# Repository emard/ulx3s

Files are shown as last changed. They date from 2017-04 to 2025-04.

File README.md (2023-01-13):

# ULX3S PCB

[ULX3S](http://radiona.org/ulx3s) = [University digital Logic](https://www.fer.unizg.hr/en/course/diglog) Learning
Xtensible board release 3 with SDRAM,
Successor of [ULX2S](http://github.com/emard/ulx2s).

[Manual](/doc/MANUAL.md) *
[Quickstart Binaries](http://github.com/emard/ulx3s-bin) *
[ULX3S at Kitspace](https://kitspace.org/boards/github.com/emard/ulx3s)

3D preview

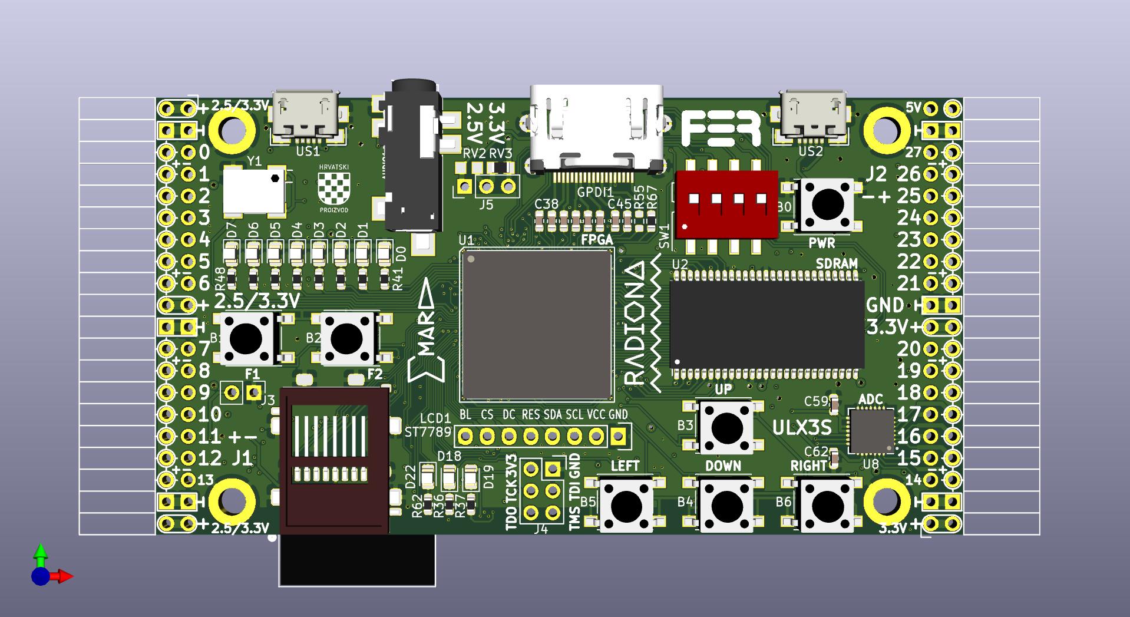
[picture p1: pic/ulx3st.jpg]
TOP

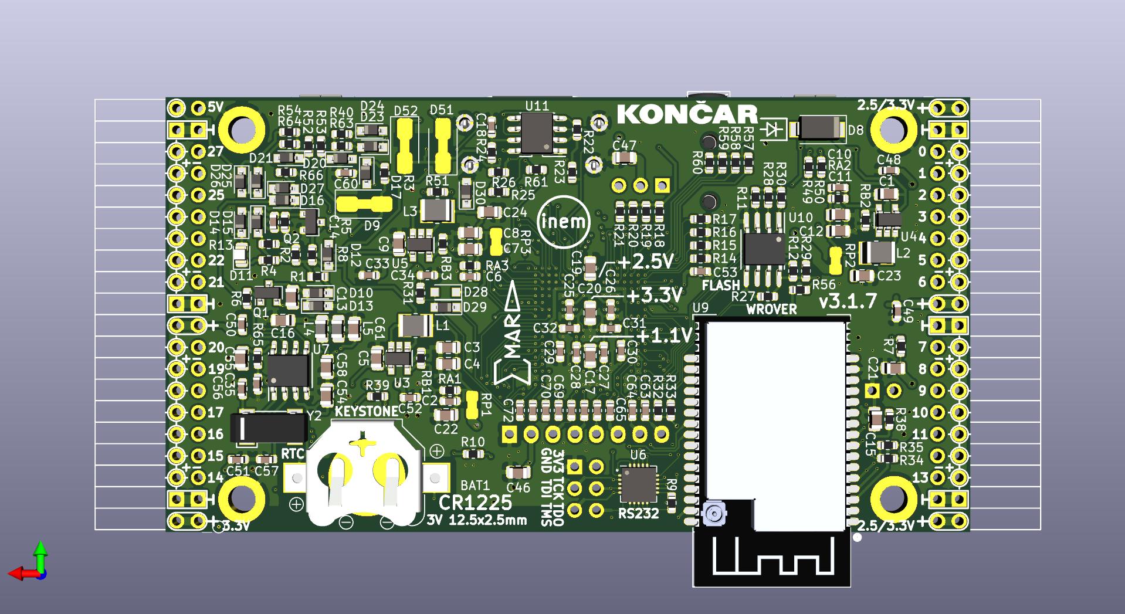
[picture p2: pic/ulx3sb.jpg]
BOTTOM


Prototypes available
at [SKRIPTARNICA](http://skriptarnica.hr/vijest.aspx?newsID=1466),
local shop inside of [FER](https://www.fer.unizg.hr/) university.

This is a small (94x51 mm) standalone FPGA board 
for education, research and general purpose, with a full 
featured selection of chips which I all wanted on
a low-cost PCB, but haven't found on the market.
It's open source and open hardware because if it is
good for our development of [f32c](http://github.com/f32c/f32c) SOC,
it should be also good to other projects.

ULX3S will carry all digital logic on our
research, [education](https://www.fer.unizg.hr/en/course/diglog) and
[makerspace](https://radiona.org) projects in next 5 years.

ULX3S is standalone embeddable gadget with onboard display, buttons,
storage, WiFi and compatible connectors.

ULX3S can do things no other board can.

ULX3S can self-reflash with a bitstream sent
remotely from web interface over WiFi or from SD
card browsed by onboard OLED display and buttons.

ULX3S can completely power down and wakeup from
battery backed RTC.

ULX3S has rich range of chips and connectivity
required for many other open source projects:
SDRAM, USB, PS/2, SDCARD, Digital Video, FLASH, RTC, I2C, OLED, AUDIO, ADC,
onboard FM/ASK antenna 88-433.92 MHz and 56 GPIO pins routed as differential
pairs and have pinout that is PMOD compatible. There are 12 true
differential bidirectional pairs and 16 single-ended pairs.

ULX3S is sufficiently equipped to
emulate [Amiga](https://github.com/emard/Minimig_ECS) retro
computer and run its games, but can do much more like
running [Linux](https://twitter.com/fpga_dave/status/1053290842809683968).

[Schematics](/doc/schematics.pdf) and PCB started with KiCAD 4.
After version v1.8 project switched to KiCAD 5 PCB editor:

    kicad ulx3s.pro

View generated gerbers

    gerbv -p plot/ulx3s.gvp

# Features

FPGA: Lattice ECP5 [LFE5U-85F-6BG381C](http://www.latticesemi.com/view_document?document_id=50461) (12/25/45/85K LUT)

USB: FTDI [FT231XS](https://www.ftdichip.com/Support/Documents/DataSheets/ICs/DS_FT231X.pdf) (500kbit JTAG and 3Mbit USB-serial)

GPIO: 56 pins (12 true differential pairs, 16 single-ended pairs),
[PMOD](https://reference.digilentinc.com/_media/pmod:pmod:originalPmodInterfaceSpecification.pdf) compatible
with power out 3.3V/1A 2.5V/1.5A

RAM: 16-bit SDRAM [MT48LC32M16](https://www.micron.com/-/media/client/global/Documents/Products/Data%20Sheet/DRAM/256Mb_sdr.pdf) (8/16/32/64 MB)

Flash: Quad-SPI Flash [IS25LP128F](http://www.issi.com/WW/pdf/25LP-WP128F.pdf) (4/8/16 MB for FPGA config and user data)

Storage: Micro-SD slot

LEDs: 11 (8 blink-LEDs, 2 USB LEDs, 1 WiFi LED)

Buttons: 7 (4 direction, 2 fire, 1 power button)

Audio: 3.5 mm jack with 4 contacts (analog stereo + digital audio or composite video)

Video: GPDI connector with 3.3V-5V I2C bidirectional level shifter

Display: placeholder for 0.96" SPI COLOR OLED [SSD1331](https://drive.google.com/file/d/0B5lkVYnewKTGRlpxcEdWaXNvWnM/view)

WiFi+bluetooth: placeholder for [ESP-32](https://www.espressif.com/sites/default/files/documentation/esp32_datasheet_en.pdf) (Standalone JTAG web interface over WiFi)

Antenna: 88-108/433 MHz FM/ASK onboard

ADC: 8 channels, 12 bit, 1 MSa/s [MAX11125](https://datasheets.maximintegrated.com/en/ds/MAX11120-MAX11128.pdf) (4/8-ch, 8/10/12-bit, 0.5/1 MSa/s)

Power: 3 Switching voltage regulators: 1.1V, 2.5V, 3.3V (1.5/2A)

Clock: 25 MHz onboard, external differential clock input

Low power sleep: 5uA/5V standby, RTC [MCP7940N](http://ww1.microchip.com/downloads/en/DeviceDoc/20005010F.pdf) clock wakeup, power button, 32768 Hz quartz and battery

GPDI is General Purpose Differential Interface,
Electrically LVDS, mostly TMDS tolerant
female receptacle more-or-less compatible
with digital monitors/TVs

# Production

Independent production
like [q3k](https://twitter.com/q3k/status/1029010026269167618) or
[samlittlewood](https://twitter.com/samlittlewood/status/1108531208001077250) is
welcome and desirable under conditions of [modified MIT LICENSE](/LICENSE.md).
If you do manual assembly here is [minimal parts list](/doc/MINIMAL.md).

ZIP the gerbers and send them to manufacturer:

    zip -r /tmp/ulx3s.zip plot/ulx3s

If you are going to order this project by yourself, it is important
what manufacturer to choose for PCBA (PCB and Assembly) service.

Parts can be ordered from [Detailed BOM](/doc/ulx3s_bom.csv)
or from [ULX3S at Kitspace](https://kitspace.org/boards/github.com/emard/ulx3s),
which automatically submits [Simplified 1-click BOM](/1-click-bom.tsv) by
clicking on "Digikey" or "Mouser" button. On each click, Digikey and Mouser will keep
accumulating the BOM in the shopping cart. Number of unique parts on Digikey and Mouser
should be equal but DigiKey may split some parts (LEDs) in multiple rows.
To reset shopping cart, click "New Cart" or "New Basket".
Kitspace may be updated with about 1 day delay after this project update.

Choose PCBA manufacturer which can produce PCB of IPC CLASS 3 quality,
5/5 mil trace resolution and 0.2 mm holes.
Avoid manufacturer who claims "quality" and "satisfaction" but doesn't
really know what will be IPC CLASS rating for this project.

PCBA manufacturer prices for the parts should be approximately equal as those
from distributors like [Mouser](http://www.mouser.com) or [DigiKey](http://www.digikey.com).
Avoid any PCBA manufacturer who asks 3$ for the 1$ part or 40$ for the 30$ part.
Select [Mouser](http://www.mouser.com) language/location icon to PCBA manufacturer
country of origin and $-currency to check is PCBA manufacturer telling the truth
about prices.

Before soldering the parts, ask manufacturer for [pictures](/pic/ulx3sb-v18.jpg) of PCB.
CLASS 3 demands, among other things, that all drill holes stay inside of VIA pads.
If some holes [break-out](/pic/ulx3sb-v18-breakout-c19.png) from pads,
ask manufacturer to make new PCBs with better drill and copper layer alignment.

[PCBCART](http://www.pcbcart.com) offers CLASS 3 quality and assembly at reasonable cost.
Prices for the parts are equal to [Mouser](http://www.mouser.com).

Don't pay everything at once. Following payment phases during the
PCBA production are recommended:

    1. Pay for the parts
    2. Manufacturer orders the parts and optionally negotiates with you about part numbers.
       Depending on market availability, some parts may come in different physical package.
    3. Send updated gerbers which fit to ordered parts.
    4. Pay for PCB
    5. Manufacturer sends pictures of produced PCB for your inspection.
       If anything looks suspicious, ask also for X-ray imaging.
    6. Pay for the assembly and shipping.

Nobody wants quality issues, so it is good to ask if manufacturer has qualified personnel
able to follow instructions 
for [ULX3S self-test](https://github.com/emard/ulx3s-bin) before shipping.

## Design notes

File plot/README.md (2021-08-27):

# Submitting for production (panelized by manufacturer)

If manufacturer panelizes, we should create
gerber files for a single PCB.

From pcbnew open PCB, view it and menu

    File->Plot

Click "Plot" to create gerbers and click "Generate Drill File"
another window will open. Click "Drill file" to create drill files.

Generate footprint positions

    File->Fabrication Outputs->Footprint Position (.pos) File

Generate floorplan PDF for top and bottom side

    File->Print
    [x] F.Fab  [ ] Print Mirrored
    [x] B.Fab  [x] Print Mirrored

RAR or ZIP to a file

    cd plot
    rar a  /tmp/ulx3s-pcb.rar gerbers
    zip -r /tmp/ulx3s-pcb.zip gerbers

Open [Seeedstudio PCB production](https://www.seeedstudio.com/fusion_pcb.html)
page, select:

    Size: 94x51 mm
    Layer: 4-layer board
    Min Solder Mask: 0.1 mm
    Min Hole size: 0.2 mm
    Min Tracking/Spacing: 5/5 mils
    Quality: IPC Class 3

click "Add your gerber file" and upload this rar file then
click on "Gerber Viewer" to see what will be produced.

Exporting for production:

Drill file:
[x] Excellon format
[x] inch units
[x] suppress trailing zeros
[x] PTH and NPTH in the same file

Footprint position file:
[x] ASCII format
[x] mm units

# Submitting for production (panelized by us)

If we panelize, we should create gerbers for panel
and the stencil. Gerbers should have a file describing
depanelization cuts (vertical v-cuts and horizontal mill
lines).

Install [KiKit](https://github.com/yaqwsx/KiKit) or upgrade

    pip3 uninstall kikit
    pip3 install git+https://github.com/yaqwsx/KiKit@master
    pip3 install --upgrade git+https://github.com/yaqwsx/KiKit@master
    pip3 show kikit
    Version: 0.99-pre1.0+35.g4fe4b78

Generate gerbers in RAR file (needs "KiKit" and "rar" installed)

    make

View panel gerbers with gerbv:

    cd plot
    gerbv (File->Open ulx3s-panel.gvp, F5 to refresh)

Count number of pads in gerbv:

    select visible either PasteTop or PasteBottom layer.
    (all other layers de-selected)
    Analyze->Analyze visible Gerber layers->D codes
    D03 count (flash aperture) is the number of pads.
    PasteTop    : 4464 pads
    PasteBottom : 1016 pads

View panel design with pcbnew (try View->3D Viewer):

    pcbnew plot/panel/ulx3s-panel.kicad_pcb

Upload "plot/panel/ulx3s-panel-gerber.rar" file generated by "make" to 
[JLCPCB](http://jlcpcb.com) and select options:

    PCB Panel
    -------------------
    Base Material       : [FR-4] Aluminium
    Layers              : 1  2 [4] 6
    Dimensions [mm]     : 213 * 246
    PCB Qty             : 5 [10] 15  20
    Different Design    : [1] 2  3  4
    Delivery Format     : Single PCB [Panel by Customer] Panel by JLCPCB
    Panel Format        : Columns: 2  Rows: 4
    PCB Thickness       : 0.8  1.0  1.2 [1.6] 2.0 mm
    Impedance           : [No] Yes
    PCB Color           : [Green] Red Yellow Blue White Black
    Silkscreen          : White
    Surface Finish      : HASL(with lead) LeadFree HASL-RoHS [ENIG-RoHS]
    Outer Copper Weight : [1 oz] 2 oz
    Inner Copper Weight : [0.5 oz] 2 oz
    Gold Fingers        : [No] Yes
    Material Type       : FR4-Standard Tg 130-145C [FR4 TG155] 
    Confirm Production file : No [Yes]
    Flying Probe Test   : [Fully Test] Not Test
    Castellated Holes   : [No] Yes
    Remove Order Number : [No] Yes  Specify Location

    Advanced options
    Min Hole            : 0.45 mm [0.2/0.4 mm]
    4-Wire Kelvin Test  : No [Yes]
    Paper between PCBs  : No [Yes]
    Appearance Quality  : [IPC Class 2 Standard] Superb Quality

    PCB Remark:         : 4 vertical V-CUTS, 16 horizontal MILL LINES of 2 mm width

    SMT Assembly        : No

    Stencil             : Yes (Order together with PCB)
    -------------------
    Framework           : No [Yes]
    Dimensions [mm]     :[470*370 (valid area 290*190)]
                          400*300 (valid area 240*140)
                          520*420 (valid area 340*240)
    Customized size     : [No] Yes
    Stencil Side        : Top+Bottom (On Single Stencil)
                          Top
                          Bottom 
                         [Top&Bottom (On Separate Stencil)]
    Electropolishing    : No [Yes]
    Fiducials           : No Fiducial
                         [Etched Through]
                          Etched Half into board

    Sending options     : EuroPacket

Check [JLCPCB extra costs](https://support.jlcpcb.com/article/62-what-cases-will-be-charged-of-extra-cost).
For stencil, up to 1000 pads above 4000 they charge 4.3$,
so they will ask for additional 9.6$ because
stencil has 4464 pads on top and 1016 on bottom, 
total 5480 pads.

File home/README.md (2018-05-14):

# User's home directory config

This is copy of my home config kicad directory

    ~/.config/kicad/

It seems that newly installed kicad 5 debian
doesn't by default set all paths correctly.

Opening ulx3s project shows many schematics simbols
as question marks.

Manually copying this config to user's home config
seems to help.

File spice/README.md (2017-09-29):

# Spice model for power section

Board can power down into low power mode and
can wake up from battery powered RTC.

RC network with adjusted time constants
tries to provide such function.

Here is spice model to test it and optionally
adjust the values

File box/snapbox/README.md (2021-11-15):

# Snap-on Screwless Box

Box for PCBs and similar.
Top and bottom parts snap-on and lock when pushed together.

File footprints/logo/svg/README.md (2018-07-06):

# Logos

Use [SVG2MOD](https://github.com/mtl/svg2mod) to convert from SVG to kicad
footprint.

In short before conversion srawing layer in the SVG file has to be
renamed usually "Layer 1" to "Cu" or "SilkS" (case insensitive). Renaming can be
done from SVG editor like "Inkscape" but in most case, "sed" will work too.

At convertsion usually some floating point scale factor is needed to make
object of desired size e.g "-f 1.5"

It can help if file is opened and saved from inkscape.

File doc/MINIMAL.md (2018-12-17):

# Minimal required parts

When manually assembling boards, it is good to know
the minimal parts list that has to be assembled for the
board to respond and be programmed.

FPGA

    U1

Switching power supplies:

    C1,U3,L1,C2,RA1,RB1,C3,C4,C22,C17
    C9,U4,L2,C10,RA2,RB2,C11,C12,C23,C19
    C5,U5,L3,C6,RA3,RB3,C7,C8,C24,C20

Power-up and hold circuit:

    US1               - USB connector
    D8                - US1 power routing diode
    R10,D12           - USB power up
    D16,R3,B0         - BTN0 power up
    R6,Q1,D13,D10,R1  - power up transistor
    D11,R4,R2         - power hold

FPGA decoupling capacitors, board could probably
work without them:

    C17,C19,C20,C25,C26,C31,C32,C27,C28,C29,C30

USB-serial to program FPGA over USB. FPGA can also
be programmed without USB-serial chip using J4 JTAG header
and external JTAG programmer:

    R49,R50,R9,U6

Clock 25MHz to properly clock examples.
FPGA will respond with JTAG ID and can be
programmed even work for combinatorial-only
examples (no registers) without this clock.

    Y1

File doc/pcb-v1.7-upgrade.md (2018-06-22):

# PCB v1.7 upgrade

This is the first board produced, most important
parts work which is mirracle in itself, and there
are some mistakes, luckily most of them can be fixed.

Mount:

    U3, U4, U5:  TLV62569DBV
    SDCARD:      SCHD3A0100
    U11 I2C:     PCA9306D SOIC-8 150-mil
    U10 FLASH:   IS25LP032D-JNLE-TR SOIC-8 150mil
    U9 WIFI:     ESP32, but not all pins! read below:

FIX: Replace this parts:

    D11=LED (High efficiency RED recommended)
    R4,R25,R26=4.7k

D11 and R4 are are on the back side on the left,
under the edge of SDRAM chip.

R25 and R26 are on the back side top,
under the GPDI connector.

Optionally, as alternative software shutdown, 
connect J2 "25-" pin to R13-D15 junction.

Don't connect ESP32 pins leading to SD card,
in the top 10-pin row, connect only 2 pins on left side and 2 pins on right
and leave 6 central pins unconnected. GND and VCC
can be connected, but no other SD signal pins.
Either cut the traces or carefully solder without 
touching those pads.

Cut WIFIEN trace and connect it to the junction of
R35 and J3, jumper should work then.

# What is fixed

Shutdown:

PCB v1.7 assembled comes with D11=1N4148 and R4=15k, those will
keep waking up the board after shutdown signal because FT231x internal
regulator will provide some voltage (cca 2.5V will appear at 3.3V line)
and that is enough to wake up the board because voltage
on ENABLE pin at switching regulators will be above its turn on
threshold of 1.5V.

Using higher voltage drop diode (RED, YELLOW or GREEN LED cca 1.7-2V, not
BLUE or WHITE) and adequate resistor, the voltage at ENABLE pin is now about
1.3V, inside of the switching regulator's hysteresis range. ENABLE is
not above turn-on threshold neither below turn-off threshold so it will
self-hold switching regulator during normal operation and at controlled
shutdown signal, it will drop below turn-off threshold, allowing reliable
shutdown.

Software shutdown is not routed to BGA pads. It is possible to connect
any GPIO (we recommend "25-") to SHUTDOWN.

I2C:

Too low pull up resistors (470 ohm) are at 5V side of the level converter PCA9306
and some monitors will receive niose with that. If data traffic at i2c is
not received 100% error-free, some monitors will get into serious problems.
When monitor interprets some data garbage as random write command and
overwrites its internal settings, such monitor might become premanently
useless. Correct pull up resistors are 4.7k and they should work properly.

WIFI:

On PCB v1.7 SD card is connected to those ESP32 pins which are widely advertised
as SD card pins, but those pins are shared with internal SPI FLASH.
So ESP32 won't boot if anything is connected there.
SD card could be connected on other pins, probably shared with OLED.
It has not yet been tested, so no patch recommendation yet.

WiFi-OFF jumper J3 doesn't have priority over FPGA enable.
If ESP32 needs to be disabled (for example, it keeps driving JTAG)
and FPGA runs bitstream which holds WiFi enabled, then J3 jumper will not
disable WiFi chip because WIFIEN is connected to wrong pin of R35.

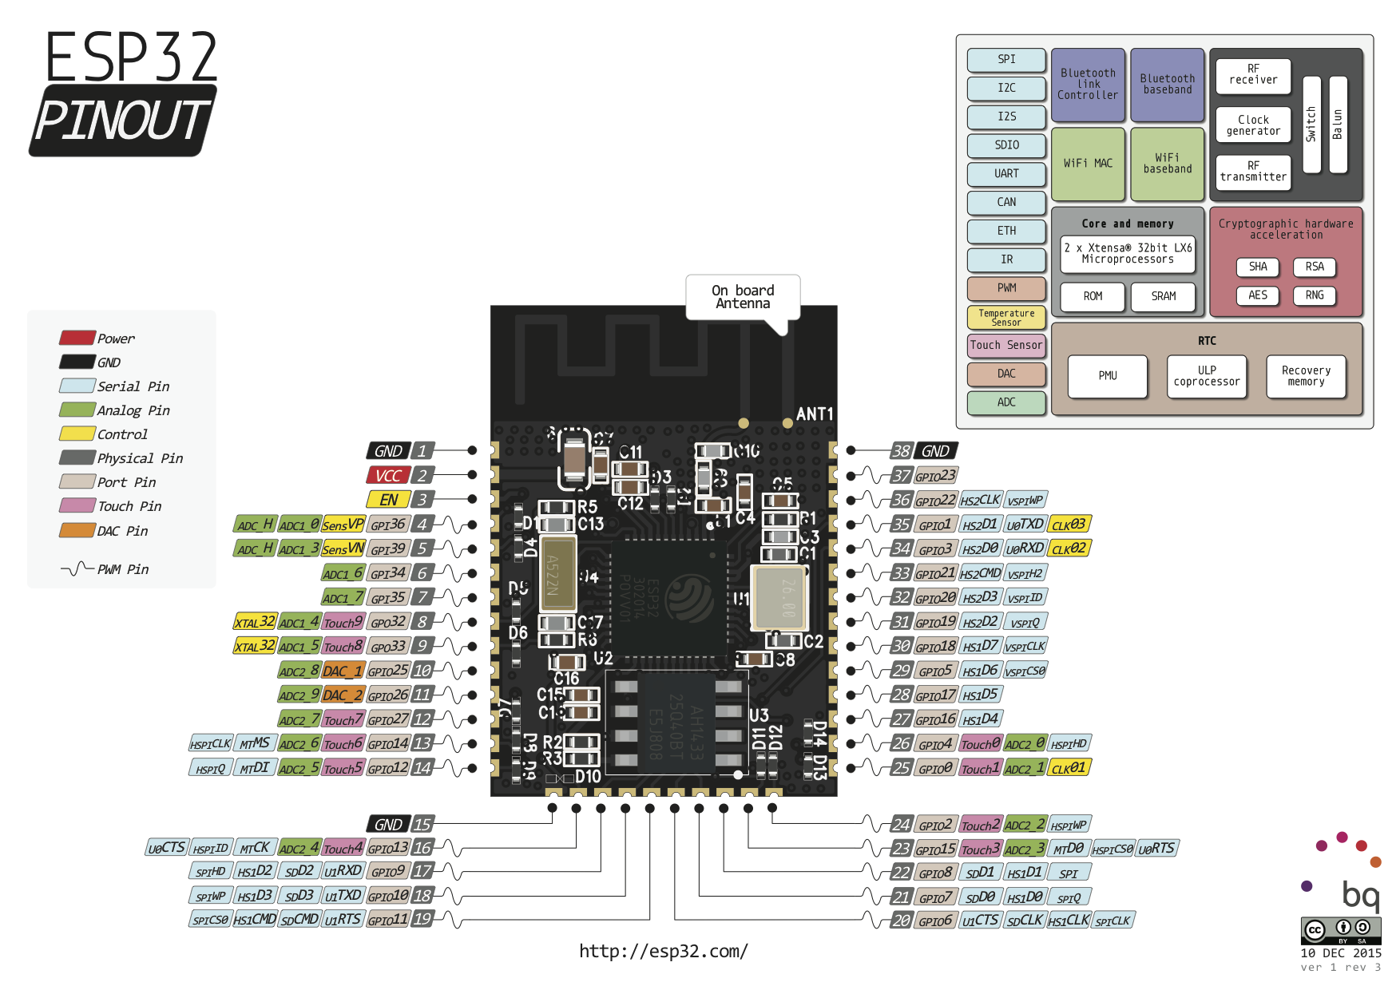
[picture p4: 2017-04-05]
doc/ESP32_Pinout_a1_3.png

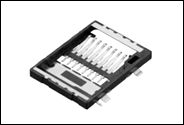
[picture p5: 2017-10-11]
doc/sdcard/sdcard-schd3a010/alps-SCHD3A0100.jpg

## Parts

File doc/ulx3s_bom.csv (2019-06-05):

Component | Description | Part | References | Value | Footprint | Quantity Per PCB | Datasheet | Koncar | Vertical | MNF1_URL | MPN | MFG1 | Digikey | price100_Vertical | Side | Mouser | price700_LCSC | LCSC | price100_RS | RS | MPN3 | Digike_y3 | MNF3_URL | Digike_y2 | MPN2 | MFG2 | MFG3 | Datasheet3 | MNF2_URL | Mouse_r2 | price1500_Mouser | Mouse_r3 | Mouse_r4 | Mouse_r5 | price1200_Chip1stop | Chip1stop | price200_Mouser | MP_N3 | MP_N2 | Datasheet2 | LowCost | price300_LCSC | TME | price300_TME | price200_LCSC | price400_LCSC | Mouser_URL | price100_AvnetEU | AvnetEU | price100_Mouser | price100_Onlinecomponents | Onlinecomponents | price300_Vertical | DatasheetLC | MP_N4 | MFG4 | MP_N5 | price_Arrow | Arrow
1 | audio jack TRS 6 pins apple/nokia | JACK_TRS_6PINS_APPLE | AUDIO1 | JACK_TRS_6PINS | CUI_SJ-43516-SMT | 1 | http://www.cui.com/product/resource/sj-4351x-smt-series.pdf | FAU001 | SJ-43516-SMT-TR | www.cui.com | SJ-43516-SMT-TR | CUI | CP-43516SJCT-ND | 0.8015$ | T | 490-SJ-43516-SMT-TR
2 | Push button switch, generic, two pins | SW_Push | B0 B1 B2 B3 B4 B5 B6 | PTS645 | SW_SPST_PTS645 | 7 | http://www.ckswitches.com/media/1471/pts645.pdf | FSW001 |  | www.ckswitches.com | PTS645SL50SMTR92 LFS |  | CKN9088CT-ND |  | T | 611-PTS645SL50SMTR92 | 0.09966$ | C221877
3 | Single-cell battery | Battery_Cell | BAT1 | CR1225 | Keystone_3000_1x12mm-CoinCell | 1 | http://www.keyelco.com/product-pdf.cfm?p=777 | FBAT001 |  | www.keyelco.com | 3000TR | Keystone | BK-885-ND |  |  | 855-S8201-46R |  |  | 0.33296$ | 1613707 | S8201-46R | 952-1662-1-ND | www.harwin.com | 36-3000CT-ND | BK-885 | MPD | Harwin | https://cdn.harwin.com/pdfs/S8201R.pdf | www.memoryprotectiondevices.com
4 | Unpolarized capacitor | C | C13 C16 C17 C19 C20 C22 C23 C24 C46 C47 | 2.2uF | C_0805_2012Metric | 10 |  | FC001 |  | www.yageo.com | CC0805MRX5R6BB225 |  | 587-5918-1-ND |  |  | 80-C0805C225K4R3123 |  |  |  |  |  |  |  | 1276-2903-1-ND |  |  |  |  |  | 603-CC805MRX5R6BB225
5 | Unpolarized capacitor | C | C14 C36 C37 C38 C39 C40 C41 C42 C43 C44 C45 C59 C60 C62 | 220nF | C_0603_1608Metric | 14 |  | FC002 |  | www.yageo.com | CC0603KRX7R8BB224 |  | 1276-1112-1-ND |  | TB | 81-GCM188R71E224K55D |  |  |  |  |  |  |  |  |  |  |  |  |  | 603-CC603KRX7R6BB224
6 | Unpolarized capacitor | C | C25 C26 C27 C28 C29 C30 C31 C32 C33 C34 C35 C48 C49 C50 C51 C52 C53 | 22nF | C_0603_1608Metric | 17 |  | FC003 |  | www.yageo.com | CC0603JRX7R8BB223 CX0603MRX7R8BB223 |  | 587-1238-1-ND |  |  | 603-CC603JRX7R8BB223 |  |  |  |  |  |  |  | 1276-2000-1-ND |  |  |  |  |  | 603-AC603KRX7R7BB223 | 35.7$
7 | Unpolarized capacitor | C | C1 C3 C4 C5 C7 C8 C9 C11 C12 C15 C21 C54 C55 C58 C61 | 22uF | C_0805_2012Metric | 15 |  | FC004 |  | www.yageo.com | CC0805ZKY5V5BB226 |  | 1276-2413-1-ND |  |  | 81-GRM21BR61A226ME1L |  |  |  |  |  |  |  | 1276-2412-1-ND |  |  |  |  |  | 81-GRM21BR61A226ME1K |  | 81-GRM219R61C226ME5L | 81-GRM188C60J226ME0J | 963-LMK212BBJ226MG-T
8 | Unpolarized capacitor | C | C56 C57 | 3.3pF | C_0603_1608Metric | 2 |  | FC005 |  | www.yageo.com | CC0603CRNPO9BN3R3 |  | 311-3848-1-ND |  |  | 710-885012006048 |  |  |  |  |  |  |  | 311-3855-1-ND
9 | Unpolarized capacitor | C | C2 C6 C10 C18 | 470pF | C_0603_1608Metric | 4 |  | FC006 |  | www.yageo.com | CS0603KRX7R9BB471 |  | 399-9086-1-ND |  |  | 603-CC603KRX7R9BB471 |  |  |  |  |  |  |  |  |  |  |  |  |  | 603-CS0603KRX79BB471
10 | Diode | D | D10 D13 D14 D16 D17 D23 D24 D25 D26 D27 D29 | 1N914 | D_SOD-323_HandSoldering | 11 |  | FV001 |  | www.fairchildsemi.com | 1N4148WS |  | 1N914BWSCT-ND |  |  | 863-MMDL914T1G |  |  |  |  |  | 1N4148WXTPMSCT-ND |  | 1N4148WSFSCT-ND |  |  |  |  |  |  |  |  |  |  | 0.01209$ | C1S541901230010
11 | Zener diode, small symbol, filled shape | D_Zener_Small_ALT | D20 D21 | 3.6V | D_SOD-323_HandSoldering | 2 | http://www.taiwansemi.com/products/datasheet/BZT52C2V4S%20SERIES_H1709.pdf | FV002 |  | www.taiwansemi.com | BZT52C3V6S |  | BZT52C3V6S-TPMSCT-ND |  |  | 833-BZT52C3V6S-TP |  |  |  |  |  |  |  |  |  |  |  |  |  |  |  |  |  |  |  |  | 0.096$
12 | Schottky diode | D_Schottky | D12 D15 | BAT54W | D_SOD-323_HandSoldering | 2 |  | FV003 |  | www.onsemi.com | NSR0530HT1G | ON semiconductor | NSR0530HT1GOSCT-ND |  |  | 755-RSX051VYM30FHTR |  |  |  |  |  |  |  |  | BAT54WSQ-7-F | Diodes inc. |  |  | www.diodes.com |  |  |  |  |  |  |  | 0.093$
13 | Light emitting diode | LED | D22 | BLUE | LED_0805_2012Metric | 1 | http://optoelectronics.liteon.com/upload/download/DS-22-99-0226/LTST-C170TBKT.pdf | FV004 |  | www.liteon.com | LTST-C170TBKT |  | 160-1579-1-ND |  | T | 859-LTST-C170TBKT |  |  |  |  |  |  |  |  |  |  |  | https://www.rohm.com/datasheet/SML-M13UT |  | 755-SMLMN2BCTT86C |  | 859-LTST-C171TBKT |  |  |  |  |  | SMLMN2BCTT86C | LTST-C171TBKT | http://optoelectronics.liteon.com/upload/download/ds22-2000-233/ltst-c171tbkt(0630).pdf
14 | Light emitting diode, filled shape | LED_ALT | D3 D7 | BLUE | LED_0805_2012Metric | 2 | http://optoelectronics.liteon.com/upload/download/DS-22-99-0226/LTST-C170TBKT.pdf | FV004 |  | www.liteon.com | LTST-C170TBKT |  | 160-1579-1-ND |  | T | 859-LTST-C170TBKT |  | C98222 |  |  |  |  |  |  |  |  |  | https://www.rohm.com/datasheet/SML-M13UT |  | 755-SMLMN2BCTT86C |  | 859-LTST-C171TBKT |  |  |  |  |  | SMLMN2BCTT86C | LTST-C171TBKT | http://optoelectronics.liteon.com/upload/download/ds22-2000-233/ltst-c171tbkt(0630).pdf | LTST-C170KRKT | 0.02930$
15 | Light emitting diode | LED | D18 | GREEN | LED_0805_2012Metric | 1 | http://optoelectronics.liteon.com/upload/download/DS22-2000-073/LTST-C170KGKT.pdf | FV005 |  | www.liteon.com | LTST-C170TGKT |  | 160-1887-1-ND |  | T | 859-LTST-C170TGKT
16 | Light emitting diode, filled shape | LED_ALT | D2 D6 | GREEN | LED_0805_2012Metric | 2 | http://optoelectronics.liteon.com/upload/download/DS22-2000-073/LTST-C170KGKT.pdf | FV005 |  | www.liteon.com | LTST-C170TGKT |  | 160-1887-1-ND |  | T | 859-LTST-C170TGKT |  |  |  |  |  |  |  |  |  |  |  |  |  |  |  |  |  |  |  |  |  |  |  |  | LTST-C170KRKT |  | LTST-C170TGKT | 0.0789$
17 | Light emitting diode, filled shape | LED_ALT | D1 D5 | ORANGE | LED_0805_2012Metric | 2 | https://optoelectronics.liteon.com/upload/download/DS-22-99-0185/LTST-C170KFKT.pdf | FV006 |  | www.liteon.com | LTST-C170KFKT |  | 160-1413-1-ND |  | T | 859-LTST-C170KFKT |  | C284931 |  |  |  |  |  |  |  |  |  |  |  |  |  |  |  |  |  |  |  |  |  |  | LTST-C170KRKT |  |  |  | 0.02075$
18 | Light emitting diode, filled shape | LED_ALT | D0 D4 D11 D19 | RED | LED_0805_2012Metric | 4 | https://optoelectronics.liteon.com/upload/download/DS-22-99-0150/LTST-C170KRKT.pdf | FV007 |  | www.liteon.com | LTST-C170KRKT |  | 160-1415-1-ND |  | TB | 859-LTST-C170KRKT |  | C94868 |  |  |  |  |  |  |  |  |  |  |  |  |  |  |  |  |  |  |  |  |  |  |  |  |  |  |  | 0.0195$ | www.mouser.com
19 | Schottky diode, small symbol | D_Schottky_Small | D8 | STPS2L30AF | D_SMA | 1 |  | FV008 |  | www.st.com | STPS2L30AF |  | 497-12310-1-ND |  |  | 511-STPS2L30AF |  |  |  |  |  |  |  |  |  |  |  |  |  |  |  |  |  |  |  |  |  |  |  |  |  |  |  |  |  |  |  | 0.22121$ | STPS2L30AF
20 | HDMI-D | HDMI-D | GPDI1 | GPDI-D | CONN-10029449-111RLF | 1 | http://portal.fciconnect.com/Comergent/fci/drawing/10029449.pdf | FX001 |  | www.amphenol-icc.com | 10029449-111RLF |  | 609-4614-1-ND |  | T | 649-10029449-111RLF |  |  |  |  |  |  |  | A136174CT-ND | 5-1903015-5 |  |  |  | www.te.com |  |  |  |  |  |  |  |  |  |  | https://hr.mouser.com/datasheet/2/418/NG_CD_1903015_S-662666.pdf |  |  |  |  |  |  |  |  |  | 0.439€ | 0.364$ | 10029449-111RLF
21 | Inductor | L | L1 L2 L3 | 2.2uH | L_1008_1210 | 3 | http://psearch.en.murata.com/inductor/product/DFE252012PD-2R2M%23.pdf | FL001 | DFE322512F-2R2M=P2 | www.murata.com | DFE322512F-2R2M=P2 | Murata | 490-10649-1-ND |  |  | 81-DFE322512F-2R2MP2 |  | C285914 |  |  |  |  | www.bourns.com |  |  | Murata | Bourns |  | www.murata.com |  |  |  |  |  |  |  |  | SRP2512A-2R2M | DFE252012P-2R2M=P2 |  | 81-DFE252012P-2R2MP2 | 0.1082$ |  |  |  |  |  |  |  |  |  |  | 0.48360$ | https://datasheet.octopart.com/LQH32PB2R2NN0L-Murata-datasheet-20916646.pdf | HEI322512A-2R2M-Q8 | Chilisin Elec | 81-LQH32PB2R2NN0L
22 | Inductor, small symbol | L_Small | L4 L5 | 33uH | L_0805_2012Metric_Pad1.15x1.40mm_HandSolder | 2 | ~ | FL002 |  | www.bourns.com | CV201210-330K |  | CV201210-330KCT-ND |  |  | 652-CV201210-330K
23 | N-MOSFET transistor, gate/source/drain | Q_NMOS_GSD | Q2 | 2N7002 | SOT-23 | 1 | https://assets.nexperia.com/documents/data_sheet/2N7002.pdf | FT002 |  | www.nxp.com | 2N7002P,215 |  | 2N7002K-TPMSCT-ND |  |  | 757-T2N7002AKLM |  |  |  |  |  |  |  |  |  |  |  |  |  | 512-2N7002L |  |  |  |  |  |  |  |  |  |  |  |  |  |  |  |  |  |  |  |  |  |  |  |  |  |  |  | 0.0437$ | T2N7002AK,LM
24 | PNP transistor, base/emitter/collector | Q_PNP_BEC | Q1 | BC857 | SOT-23 | 1 | https://assets.nexperia.com/documents/data-sheet/BC856_BC857_BC858.pdf | FT001 |  | www.nxp.com | BC857 |  | TBC857BLMCT-ND |  |  | 583-BC856A-T |  |  |  |  |  |  |  |  |  |  |  |  |  | 863-BC857BLT1G |  |  |  |  |  |  |  |  |  |  |  |  |  |  |  |  |  |  |  | 0.06$
25 | Resistor | R | R38 | 0.47 | R_0603_1608Metric | 1 |  | FR001 |  | www.ctscorp.com | 73L2R47J | CTS | 73L2R47JCT-ND |  |  | 774-73L2R47J
26 | Resistor | R | R6 R8 R14 R18 R29 R40 R54 R57 R66 | 1.1k | R_0603_1608Metric | 9 |  | FR002 |  | www.yageo.com | RC0603FR-071K1L |  | P1.10KHCT-ND |  |  | 603-RC0603FR-071K1L
27 | Resistor | R | R24 | 100k | R_0603_1608Metric | 1 |  | FR003 |  | www.yageo.com | AC0603FR-10100KL |  | P100KHCT-ND |  |  | 71-RCA0603100KJNEC |  |  |  |  |  |  |  |  |  |  |  |  |  | 71-CRCW0603100KFKEAC
28 | Resistor | R | R11 R12 R27 R28 | 10k | R_0603_1608Metric | 4 |  | FR014 |  | www.yageo.com | RC0603FR-0710KL |  | 311-10KLMCT-ND |  |  | 603-RC0603FR-0710KL
29 | Resistor | R | R7 R10 R17 R21 R39 R51 R60 | 130 | R_0603_1608Metric | 7 |  | FR004 |  | www.yageo.com | RC0603FR-07130RL |  | 311-130HRCT-ND |  |  | 603-RC0603FR-07130RL
30 | Resistor | R | R9 R13 R31 R32 R33 R34 R55 R63 R64 RA1 RA2 RA3 | 15k | R_0603_1608Metric | 12 |  | FR005 |  | www.yageo.com | RC0603FR-0715KL RC0603FR-1015KL |  | YAG3569CT-ND |  |  | 603-RC0603FR-0715KL |  |  |  |  |  |  |  |  |  |  |  |  |  | 603-RC0603FR-1015KL | 8.4$ | 603-RC0603FR-1315KL
31 | Resistor | R | R2 RB1 | 18k | R_0603_1608Metric | 2 |  | FR006 |  | www.yageo.com | RC0603FR-1018KL |  | 311-18.0KHRCT-ND |  |  | 71-CRCW060318K0FKEAC
32 | Resistor | R | R5 | 2.2M | R_0603_1608Metric | 1 |  | FR007 |  | www.yageo.com | RC0603FR-132M2L |  | P2.20MHCT-ND |  |  | 603-AC0603FR-072M2L
33 | Resistor | R | R49 R50 R52 R53 | 27 | R_0603_1608Metric | 4 |  | FR008 |  | www.yageo.com | AC0603JR-0727RL |  | 311-27.0HRCT-ND |  |  | 603-AC0603JR-0727RL
34 | Resistor | R | R16 R20 R59 | 270 | R_0603_1608Metric | 3 |  | FR010 |  | www.yageo.com | RC0603FR-07270RL |  | 311-270HRCT-ND |  |  | 603-RC0603FR-07270RL
35 | Resistor | R | R22 R23 RB3 | 3.3k | R_0603_1608Metric | 3 |  | FR009 |  | www.yageo.com | RT0603FRE073K3L |  | YAG3605CT-ND |  |  | 603-RC0603FR-073K3L |  |  |  |  |  |  |  |  |  |  |  |  |  | 603-RC0603FR-103K3L
36 | Resistor | R | R1 R3 R4 R25 R26 R30 RB2 | 4.7k | R_0603_1608Metric | 7 |  | FR011 |  | www.yageo.com | AC0603FR-104K7L |  | YAG3613CT-ND |  |  | 755-SFR03EZPF4701 |  |  |  |  |  |  |  |  |  |  |  |  |  | 603-RC0603FR-074K7L |  | 603-AC0603FR-074K7L
37 | Resistor | R | R15 R19 R35 R36 R37 R41 R42 R43 R44 R45 R46 R47 R48 R58 R61 R62 R65 | 549 | R_0603_1608Metric | 17 |  | FR012 |  | www.yageo.com | RC0603FR-07549RL |  | 311-549HRCT-ND |  | TB | 603-RC0603FR-07549RL
38 | Jumper, normally closed, small symbol | Jumper_NC_Small | RV3 | 0 | R_0805_2012Metric_Pad1.29x1.40mm_HandSolder | 1 |  | FR013 |  | www.yageo.com | RC0805JR-070RL |  | YAG1327CT-ND |  | T | 71-RCG08050000Z0EA
39 | Micro SD Card Socket with CD | Micro_SD_Card_CD | SD1 | SCHD3A0100 | SCHD3A100 | 1 | https://www.relayspec.com/catalogs/001285/2010/SCHD.pdf | FX002 |  | www.on-stars.com | SCHD3A0100 |  | WM6698DKR-ND |  | T | 538-47219-2001 |  | C164170 |  |  |  |  |  |  | 47219-2001 |  |  |  | www.molex.com |  |  |  |  |  |  |  |  |  |  | https://www.molex.com/pdm_docs/sd/472192001_sd.pdf
40 | 4x DIP Switch, Single Pole Single Throw (SPST) switch, small symbol | SW_DIP_x04 | SW1 | SW_DIP_x04 | SW_DIP_x4_W8.61mm_Slide_LowProfile | 1 | https://www.ctscorp.com/wp-content/uploads/219.pdf | FSW002 |  | www.jameco.com | 219-4MST |  | CT2194MST-ND |  | T | 774-2194MST
41 | ESP-WROOM32 | ESP-WROOM32 | U9 | ESP32-WROOM | ESP32-WROOM-stencil | 1 | http://espressif.com/sites/default/files/documentation/esp32_datasheet_en.pdf | FU001 |  | espressif.com | ESP-WROOM-32 |  | 1904-1010-1-ND |  |  | 356-ESP-WROOM-32 |  |  |  |  |  |  |  |  |  |  |  |  |  |  |  |  |  |  |  |  |  |  |  |  | Leave empty |  |  |  |  |  |  |  |  | 3.32€
42 | Full Speed USB to Full Handshake UART, SSOP-20 | FT231XS | U6 | FT231XS | FT231X-SSOP-20_4.4x6.5mm_Pitch0.65mm | 1 | www.ftdichip.com/Documents/DataSheets/ICs/DS_FT231X.pdf | FU002 |  | www.ftdichip.com | FT231XS |  | 768-1129-1-ND |  |  | 895-FT231XS-R |  |  | 1.86$ | 7570032
43 | SPI Serial EEPROM, DIP-8/SOIC-8/TSSOP-8 | 25LCxxx | U10 | IS25LP128F-JBLE | SOA008-150-208mil | 1 | http://www.issi.com/WW/pdf/25LP-WP128F.pdf | FU003 |  | www.issi.com | IS25LP128F-JBLE |  | W25Q128JVSIQCT-ND |  |  | 454-W25Q128JVSIMTR |  | C97521 |  |  | IS25LP032D-JNLA3 | 706-1607-1-ND | www.issi.com | IS25LP128F-JBLE-ND | IS25LP032D-JNLE-TR |  |  |  | www.issi.com |  |  |  |  |  |  |  |  |  |  | http://www.issi.com/WW/pdf/25LP-WP032D.pdf | 870-IS25LP032DJBLETR
44 | ECP5U85 | LFE5U-85F-6BG381C | U1 | LFE5U-85F-6BG381C | BGA-381_pitch0.8mm_dia0.4mm | 1 | http://www.latticesemi.com/~/media/LatticeSemi/Documents/DataSheets/ECP5/FPGA-DS-02012.pdf | FU004 |  | www.latticesemi.com | LFE5U-85F-6BG381C | Lattice | 220-2071-ND |  | T | 842-LFE5U85F6BG381C |  |  |  |  |  |  |  |  |  | Lattice |  |  | www.latticesemi.com |  |  |  |  |  |  |  |  |  | LFE5U-12F-6BG381C |  | 842-LFE5U12F6BG381C |  |  |  |  |  | www.mouser.com
45 | SPI ADC | MAX1112x | U8 | MAX11125 | MAX1112x-TQFN-28-1EP_5x5mm_Pitch0.5mm | 1 | https://datasheets.maximintegrated.com/en/ds/MAX11120-MAX11128.pdf | FU005 |  | www.maximintegrated.com | MAX11125ATI+ |  | MAX11125ATI+-ND |  | T | 700-MAX11125ATI+ |  |  |  |  |  |  |  |  | MAX11123ATI+ |  |  |  | www.maximintegrated.com |  |  |  |  |  |  |  |  |  |  |  | 700-MAX11123ATI+
46 | Realtime Clock/Calendar I2C Interface, SOIC-8 | PCF8563T | U7 | MCP7940NT | SOT96-1 | 1 | http://ww1.microchip.com/downloads/en/DeviceDoc/20005010F.pdf | FU006 |  | www.microchip.com | MCP7940NT-I/SN |  | MCP7940NT-I/SNCT-ND |  |  | 579-MCP7940NT-I/SN |  |  |  |  |  |  |  | 568-5306-1-ND | PCF8523T/1,118 |  |  |  | www.nxp.com |  |  |  |  |  |  |  |  |  |  | https://www.nxp.com/docs/en/data-sheet/PCF8523.pdf |  |  |  |  |  |  |  |  |  |  |  |  |  |  |  |  |  |  | MCP7940NT-I/SN
47 | SDRAM | MT48LC16M16A2TG | U2 | MT48LC16M16A2TG | TSOP54 | 1 | https://www.micron.com/~/media/Documents/Products/Data%20Sheet/DRAM/256Mb_sdr.pdf | FU007 |  | www.micron.com | MT48LC16M16A2TG-6A | Micron | 1450-1385-1-ND |  | T | 913-AS4C32M16SB-7TCN |  | C62379 |  |  | W9812G6KH-6 |  |  | 1450-1352-1-ND | IS42S16160G-7TL-TR | ISSI | Winbond |  | www.issi.com | 913-4816M16A2TG6AGTR |  |  |  |  |  |  |  |  |  |  |  |  |  |  |  |  |  |  |  |  |  |  |  |  |  | Alliance
48 | 2-Bit Bidirectional Voltage-Level Translator in SOIC-8 Package | PCA9306D | U11 | PCA9306D | SM8 | 1 | https://www.nxp.com/docs/en/data-sheet/PCA9306.pdf | FU008 |  | www.nxp.com | PCA9306D |  | 568-4215-1-ND |  |  | 771-PCA9306D-T |  |  |  |  |  |  |  |  |  |  |  |  |  |  |  |  |  |  |  |  |  |  |  |  | Leave empty
49 | DC-DC Converter | DCDC | U3 U4 U5 | TLV62569DBV | TSOT-25 | 3 | http://www.ti.com/lit/ds/symlink/tlv62569.pdf | FU009 |  | www.ti.com | TLV62569DBVR | TI | 296-47360-1-ND |  |  | 595-TLV62569DBVR |  | C141836 |  |  |  |  |  |  | DIO6015BCST5 | DIOO |  |  | www.dioo.com | 453-DIO6015BCST5 |  |  |  |  |  |  |  |  |  |  | 453-DIO6015BCST5 |  |  |  |  |  |  |  |  |  |  |  |  | http://www.dioo.com/attachments/files/20161031180022_361.pdf
50 | Micro USB | USB_OTG | US1 US2 | MICRO_USB | USB-MICRO-B-FCI-10118192-0001LF | 2 | http://portal.fciconnect.com/Comergent/fci/drawing/10118192.pdf | FU010 |  | www.fciconnect.com | 10118192-0001LF | FCI | 609-4613-1-ND |  | T | 649-10118192-0001LF |  |  |  |  |  |  |  |  | 47346-0001 | Molex |  |  | www.molex.com | 538-47346-0001 |  |  |  |  |  |  |  |  |  | https://www.molex.com/pdm_docs/sd/473460001_sd.pdf
51 | Four pin crystal, GND on pins 2 and 3 | Crystal_GND23 | Y2 | 32768Hz | Crystal_SMD_ABS25 | 1 | https://www.iqdfrequencyproducts.com/products/pn/LFXTAL016178Reel.pdf | FQ002 |  | www.iqdfrequencyproducts.com | LFXTAL016178REEL |  | 1923-1021-1-ND |  |  | 449-LFXTAL016178REEL |  |  |  |  | LFXTAL003000Reel |  |  | 1923-1019-1-ND | CM7V-T1A-32.768k-9pF-20PPM-TA-QA T3 |  |  | http://www.iqdfrequencyproducts.com/products/pn/LFXTAL003000Reel.pdf |  | 428-201568-MG03 |  | 815-ABS25-32.768KHZT |  |  |  |  |  |  |  |  |  |  | 32.768K-855MXR
52 | Four pin crystal, GND on pins 2 and 4 | Crystal_GND24 | Y1 | FNETHE025 | Crystal_SMD_7050_4Pads | 1 | https://www.diodes.com/assets/Datasheets/FNETHE025.pdf | FQ001 |  | www.diodes.com | FNETHE025 |  | FNETHE025CT-ND |  | T | 729-FNETHE025
Component Groups: | 52
Component Count: | 196
Fitted Components: | 196
Number of PCBs: | 1
Total components: | 196
Schematic Version: | 3.0.8
Schematic Date:
BoM Date: | srijeda, 05. lipnja 2019. 12:30:37 CEST
Schematic Source: | /home/guest/src/fpga/circuits/ulx3s/ulx3s.sch
KiCad Version: | Eeschema 5.0.2+dfsg1-1
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

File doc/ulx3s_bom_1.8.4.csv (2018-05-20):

Component | Description | Part | References | Value | Footprint | Quantity Per PCB | Datasheet | MFG_URL | Distributor1_PN | MFG_PN | Distributor1_URL | Distributor1_PN2 | Distributor1_PN1 | MFG2_URL | MFG1_PN | MFG2_PN | MFG1_URL | Distributor2_URL | Datasheet2 | Distributor2_PN | Note | MFG_TR_DS
1 | audio jack TRS 6 pins | JACK_TRS_6PINS | AUDIO1 | JACK_TRS_6PINS | CUI_SJ-43516-SMT | 1 | http://www.cui.com/product/resource/sj-4351x-smt-series.pdf | www.cui.com | 490-SJ-43516-SMT-TR | SJ-43516-SMT-TR | www.mouser.com
2 | single battery cell | Battery_Cell | BAT1 | CR1225 | Keystone_3000_1x12mm-CoinCell | 1 | http://www.keyelco.com/product-pdf.cfm?p=777 | www.keyelco.com | 534-3000TR | 3000TR | www.mouser.com
3 | Push button switch, generic, two pins | SW_Push | BTN0 BTN1 BTN2 BTN3 BTN4 BTN5 BTN6 | PTS645 | SW_SPST_PTS645 | 7 | http://www.ckswitches.com/media/1471/pts645.pdf | www.ckswitches.com |  | PTS645SL50SMTR92 LFS | www.mouser.com
4 | Unpolarized capacitor | C | C14 C36 C37 C38 C39 C40 C41 C42 C43 C44 C45 | 100nF | C_0603_1608Metric | 11 |  | www.yageo.com |  | CC0603KRX7R8BB104
5 | Unpolarized capacitor | C | C13 C16 C17 C19 C20 C22 C23 C24 C46 C47 | 2.2uF | C_0805_2012Metric | 10 |  | www.yageo.com |  | CC0805MRX5R6BB225
6 | Unpolarized capacitor | C | C25 C26 C27 C28 C29 C30 C31 C32 C33 C34 C35 C48 C49 C50 C51 C52 C53 | 22nF | C_0603_1608Metric | 17 |  | www.yageo.com |  | CX0603MRX7R8BB223
7 | Unpolarized capacitor | C | C1 C3 C4 C5 C7 C8 C9 C11 C12 C15 C21 C54 | 22uF | C_0805_2012Metric | 12 |  | www.yageo.com |  | CC0805ZKY5V5BB226
8 | Unpolarized capacitor | C | C2 C6 C10 C18 | 470pF | C_0603_1608Metric | 4 |  | www.yageo.com |  | CS0603KRX7R9BB471
9 | Diode | D | D10 D13 D14 D16 D17 | 1N4148 | D_SOD-323_HandSoldering | 5 |  | www.fairchildsemi.com | 512-1N4148WS | 1N4148WS | www.mouser.com
10 | Zener Diode, small symbol, alternativ symbol | D_Zener_Small_ALT | D20 D21 | 3.6V | D_SOD-323_HandSoldering | 2 | http://www.taiwansemi.com/products/datasheet/BZT52C2V4S%20SERIES_H1709.pdf | http://www.taiwansemi.com/en | 821-BZT52C3V6S | BZT52C3V6S | www.mouser.com
11 | Schottky diode | D_Schottky | D12 D15 D23 D24 D25 D26 | BAT54W | D_SOD-323_HandSoldering | 6 | https://www.diodes.com/assets/Datasheets/ds30065.pdf | www.onsemi.com | 863-NSR0530HT1G | NSR0530HT1G | www.mouser.com | 621-BAT54WSQ-7-F | 621-BAT54WSQ-7-F | www.diodes.com | BAT54WSQ-7-F | BAT54WSQ-7-F | www.diodes.com
12 | LED generic, alternativ symbol | LED_ALT | D3 D7 D22 | BLUE | LED_0805_2012Metric | 3 | http://www.mouser.com/ds/2/239/Lite-On-LTST-C170TBKT-1175372.pdf | www.liteon.com | 859-LTST-C170TBKT | LTST-C170TBKT | www.mouser.com
13 | LED generic, alternativ symbol | LED_ALT | D2 D6 D18 | GREEN | LED_0805_2012Metric | 3 | http://optoelectronics.liteon.com/upload/download/DS22-2000-073/LTST-C170KGKT.pdf | www.lite-on.com | 859-LTST-C170KGKT | LTST-C170KGKT | www.mouser.com
14 | LED generic, alternativ symbol | LED_ALT | D1 D5 | ORANGE | LED_0805_2012Metric | 2 | https://optoelectronics.liteon.com/upload/download/DS-22-99-0185/LTST-C170KFKT.pdf | www.liteon.com | 859-LTST-C170KFKT | LTST-C170KFKT | www.mouser.com
15 | LED generic, alternativ symbol | LED_ALT | D0 D4 D11 D19 | RED | LED_0805_2012Metric | 4 | https://optoelectronics.liteon.com/upload/download/DS-22-99-0150/LTST-C170KRKT.pdf | www.liteon.com | 859-LTST-C170KRKT | LTST-C170KRKT | www.mouser.com
16 | Schottky diode, small symbol | D_Schottky_Small | D8 D9 D51 D52 | STPS2L30AF | D_SMA_Handsoldering | 4 |  |  | 511-STPS2L30AF | STPS2L30AF | www.mouser.com
17 |  | HDMI-D | GPDI1 | GPDI-D | CONN-10029449-111RLF | 1 | http://portal.fciconnect.com/Comergent/fci/drawing/10029449.pdf | www.amphenol-icc.com | 649-10029449-111RLF | 10029449-111RLF | www.mouser.com |  |  |  |  |  |  | www.mouser.com | https://hr.mouser.com/datasheet/2/418/NG_CD_1903015_S-662666.pdf | 571-5-1903015-5
18 | Generic connector, double row, 02x03, odd/even pin numbering scheme (row 1 odd numbers, row 2 even numbers), script generated (kicad-library-utils/schlib/autogen/connector/) | Conn_02x03_Odd_Even | J4 | CONN_02X03 | Socket_Strip_Straight_2x03 | 1 |  |  |  |  |  |  |  |  |  |  |  |  |  |  | Do not install
19 | Generic connector, double row, 02x20, odd/even pin numbering scheme (row 1 odd numbers, row 2 even numbers), script generated (kicad-library-utils/schlib/autogen/connector/) | Conn_02x20_Odd_Even | J1 J2 | CONN_02X20 | Socket_Strip_Angled_2x20 | 2 |  |  |  |  |  |  |  |  |  |  |  |  |  |  | Do not install
20 | Generic connector, single row, 01x03, script generated (kicad-library-utils/schlib/autogen/connector/) | Conn_01x03 | J5 | VJ1 | PinHeader_1x03_P2.54mm_Vertical | 1 |  |  |  |  | www.mouser.com |  |  |  |  |  |  |  |  |  | Do not install
21 | Generic connector, double row, 02x01, this symbol is compatible with counter-clockwise, top-bottom and odd-even numbering schemes., script generated (kicad-library-utils/schlib/autogen/connector/) | Conn_02x01 | J3 | WIFI_OFF | PinHeader_1x02_P2.54mm_Vertical | 1 |  |  |  |  |  |  |  |  |  |  |  |  |  |  | Do not install
22 | Inductor | L | L1 L2 L3 | 2.2uH | L_1008_1210 | 3 | http://psearch.en.murata.com/inductor/product/DFE252012PD-2R2M%23.pdf | www.murata.com | 652-SRP2512A-2R2M | DFE252012P-2R2M=P2 | www.mouser.com
23 | Connector, single row, 01x07 | SSD_13xx | OLED1 | SSD_1331 | oled_13xx | 1 | https://drive.google.com/file/d/0B5lkVYnewKTGRlpxcEdWaXNvWnM/view | www.displaymodule.com |  | DM-OLEDC095-626 | www.mouser.com |  |  |  |  |  |  |  |  |  | Do not install
24 | Transistor N-MOSFETwith substrate diode (general) | Q_NMOS_GSD | Q2 | 2N7002 | SOT-23_Handsoldering | 1 | https://assets.nexperia.com/documents/data_sheet/2N7002.pdf | www.nexperia.com | 771-2N7002P-215 | 2N7002P,215 | www.mouser.com
25 | Transistor PNP (general) | Q_PNP_BEC | Q1 | BC857 | SOT-23_Handsoldering | 1 | https://assets.nexperia.com/documents/data-sheet/BC856_BC857_BC858.pdf |  | 771-BC857B-T/R | BC857 | www.mouser.com
26 | Resistor | R | R56 | 0 | R_0603_1608Metric | 1 |  | www.yageo.com |  | RC0603JR-070RL |  |  |  |  |  |  |  |  |  |  | Do not install
27 | Resistor | R | R38 | 0.47 | R_0603_1608Metric | 1 |  | www.ctscorp.com |  | 73L2R47J
28 | Resistor | R | R14 R18 R57 | 1.2k | R_0603_1608Metric | 3 |  | www.yageo.com |  | RC0603FR-101K2L
29 | Resistor | R | R40 R54 | 1.5k | R_0603_1608Metric | 2 |  | www.yageo.com |  | RC0603FR-071K5L
30 | Resistor | R | R24 | 100k | R_0603_1608Metric | 1 |  | www.yageo.com |  | AC0603FR-10100KL
31 | Resistor | R | R11 R12 R27 R28 R31 R32 R33 | 10k | R_0603_1608Metric | 7 |  | www.yageo.com |  | AC0603FR-0710KL
32 | Resistor | R | R7 R10 R17 R21 R39 R51 R60 | 150 | R_0603_1608Metric | 7 |  | www.yageo.com |  | AC0603FR-07150RL
33 | Resistor | R | R1 R9 R13 R34 R55 R63 R64 RA1 RA2 RA3 | 15k | R_0603_1608Metric | 10 |  | www.yageo.com |  | AC0603FR-1015KL
34 | Resistor | R | R6 R8 R29 R36 R37 R41 R42 R43 R44 R45 R46 R47 R48 R62 | 1k | R_0603_1608Metric | 14 |  | www.yageo.com |  | RC0603FR-071KL
35 | Resistor | R | R22 R23 | 2.2k | R_0603_1608Metric | 2 |  | www.yageo.com |  | RC0603FR-072K2L
36 | Resistor | R | R49 R50 R52 R53 | 27 | R_0603_1608Metric | 4 |  | www.yageo.com |  | AC0603JR-0727RL
37 | Resistor | R | R16 R20 R59 | 330 | R_0603_1608Metric | 3 |  | www.yageo.com |  | RC0603JR-07330RP
38 | Resistor | R | R5 | 4.7M | R_0603_1608Metric | 1 |  | www.bourns.com |  | CR0603-JW-475ELF
39 | Resistor | R | R3 R4 R25 R26 R30 RB2 | 4.7k | R_0603_1608Metric | 6 |  | www.yageo.com |  | AC0603FR-104K7L
40 | Resistor | R | R35 R61 | 470 | R_0603_1608Metric | 2 |  | www.yageo.com |  | RC0603FR-07470RL
41 | Resistor | R | R2 | 47k | R_0603_1608Metric | 1 |  | www.yageo.com |  | AC0603FR-0747KL
42 | Resistor | R | R15 R19 R58 | 680 | R_0603_1608Metric | 3 |  | www.yageo.com |  | RC0603FR-10680RL
43 | Resistor | R | RB1 | 18k | R_0603_1608Metric | 1 |  | www.yageo.com |  | RC0603FR-1018KL
44 | Resistor | R | RB3 | 3.3k | R_0603_1608Metric | 1 |  | www.yageo.com |  | RT0603FRE073K3L
45 | Jumper, normally closed | Jumper_NC_Small | RP1 RP2 RP3 | 0 | R_0603_1608Metric_Pad0.84x1.00mm_HandSolder | 3 |  | www.yageo.com |  | RC0603JR-070RL | www.mouser.com
46 | Jumper, 2-pole, open | Jumper_2_Open | RV2 RV3 | 0 | R_0603_1608Metric_Pad0.84x1.00mm_HandSolder | 2 |  | www.yageo.com |  | RC0603JR-070RL | www.mouser.com |  |  |  |  |  |  |  |  |  | Do not install
47 | Micro SD Card Socket with CD | Micro_SD_Card_CD | SD1 | SCHD3A0100 | SCHD3A100 | 1 | https://www.relayspec.com/catalogs/001285/2010/SCHD.pdf | www.alps.com | SCHD3A0100 | SCHD3A0100 | www.on-stars.com |  |  |  |  |  |  | www.mouser.com |  | 688-SCHD3A0100
48 | Generic connector, double row, 02x04, counter clockwise pin numbering scheme (similar to DIP packge numbering), script generated (kicad-library-utils/schlib/autogen/connector/) | Conn_02x04_Counter_Clockwise | SW1 | DIPSW | SW_DIP_x4_W8.61mm_Slide_LowProfile | 1 | https://www.ctscorp.com/wp-content/uploads/219.pdf | www.jameco.com | 774-2194MST | 219-4MST | www.mouser.com
49 |  | ESP-32S | U9 | ESP-WROOM-32 | ESP32-WROOM | 1 | http://espressif.com/sites/default/files/documentation/esp32_datasheet_en.pdf | espressif.com |  | ESP-WROOM-32 | www.mouser.com
50 | Full Speed USB to Full Handshake UART, SSOP-20 | FT231XS | U6 | FT231XS | SSOP-20_4.4x6.5mm_Pitch0.65mm | 1 | www.ftdichip.com/Documents/DataSheets/ICs/DS_FT231X.pdf | www.ftdichip.com | 895-FT231XS-R | FT231XS | www.mouser.com
51 | SPI Serial EEPROM, DIP-8/SOIC-8/TSSOP-8 | 25LCxxx | U10 | IS25LP032D-JNLE-TR | SOA008-150mil | 1 | http://www.issi.com/WW/pdf/25LP-WP032D.pdf | www.issi.com | 870-IS25LP032DJNLETR | IS25LP032D-JNLE-TR | www.mouser.com
52 | ECP5U85 | LFE5U-85F-6BG381C | U1 | LFE5U-85F-6BG381C | BGA-381_pitch0.8mm_dia0.4mm | 1 | http://www.latticesemi.com/~/media/LatticeSemi/Documents/ApplicationNotes/EH/TN1260.pdf | www.latticesemi.com | 842-LFE5U85F6BG381C | LFE5U-85F-6BG381C | www.mouser.com
53 | SPI ADC | MAX1112x | U8 | MAX11125 | QFN-28-1EP_5x5mm_Pitch0.5mm | 1 | https://datasheets.maximintegrated.com/en/ds/MAX11120-MAX11128.pdf | www.maximintegrated.com | 700-MAX11125ATI+ | MAX11125ATI+ | www.mouser.com
54 |  | MT48LC16M16A2TG | U2 | MT48LC16M16A2TG | TSOP54 | 1 | https://www.micron.com/~/media/Documents/Products/Data%20Sheet/DRAM/256Mb_sdr.pdf | www.micron.com | 913-4816M16A2TG6AGTR | MT48LC16M16A2TG-6A | www.mouser.com
55 | 2-Bit Bidirectional Voltage-Level Translator in SOIC-8 Package | PCA9306D | U11 | PCA9306D | SM8 | 1 | https://www.nxp.com/docs/en/data-sheet/PCA9306.pdf
56 | Realtime Clock/Calendar I2C Interface, SOIC-8 | PCF8563T | U7 | PCF8523 | SOT96-1 | 1 | https://www.nxp.com/docs/en/data-sheet/PCF8523.pdf |  | 771-PCF8523T/1118 | PCF8523T/1,118 | www.mouser.com |  |  |  |  |  |  |  |  |  |  | https://www.nxp.com/docs/en/packing/SOT96-1_118.pdf
57 | DC-DC Converter | DCDC | U3 U4 U5 | TLV62569DBV | TSOT-25 | 3 | http://www.ti.com/lit/ds/symlink/tlv62569.pdf | www.ti.com | 595-TLV62569DBVR | TLV62569DBVR | www.mouser.com
58 |  | USB_OTG1 | US1 US2 | MICRO_USB | USB-MICRO-B-FCI-10118192-0001LF | 2 | portal.fciconnect.com/Comergent/fci/drawing/10118192.pdf | www.fciconnect.com |  | 10118192-0001LF | www.mouser.com
59 | Four pin crystal (GND on pins 2 and 3), e.g. in SMD package | Crystal_GND23 | Y2 | 32768Hz | Crystal_SMD_ABS25 | 1 | http://www.iqdfrequencyproducts.com/products/pn/LFXTAL003000Reel.pdf | www.iqdfrequencyproducts.com | 815-ABS25-32.768KHZT | LFXTAL003000Reel | www.mouser.com
60 | Four pin crystal (GND on pins 2 and 4), e.g. in SMD package | Crystal_GND24 | Y1 | FNETHE025 | Crystal_SMD_7050_4Pads | 1 | https://www.diodes.com/assets/Datasheets/FNETHE025.pdf | www.diodes.com | 729-FNETHE025 | FNETHE025 | www.mouser.com
Component Groups: | 60
Component Count: | 196
Fitted Components: | 196
Number of PCBs: | 1
Total components: | 196
Schematic Version: | 1.8.4
Schematic Date:
BoM Date: | nedjelja, 20. svibnja 2018. 21:39:32 CEST
Schematic Source: | /home/davor/src/circuits/fpga/ulx3s/ulx3s.sch
KiCad Version: | Eeschema 5.0.0-rc2-dev-unknown+dfsg1+20180318-2

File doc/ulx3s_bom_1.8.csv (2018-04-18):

Component | Description | Part | References | Value | Footprint | Quantity Per PCB | Datasheet | Note | MFG_URL | Distributor1_PN | MFG_PN | Distributor1_URL | Distributor2_URL | Distributor2_PN | MFG_TR_DS
1 | Antenna symbol | Antenna | AE1 | 433MHz | Pin_Header_Straight_1x03_Pitch2.54mm | 1 |  | Do not install
2 | audio jack TRS 6 pins | JACK_TRS_6PINS | AUDIO1 | JACK_TRS_6PINS | CUI_SJ-43516-SMT | 1 | http://www.cui.com/product/resource/sj-4351x-smt-series.pdf |  | www.cui.com | 490-SJ-43516-SMT-TR | SJ-43516-SMT-TR | www.mouser.com
3 | single battery cell | Battery_Cell | BAT1 | CR1225 | Keystone_3000_1x12mm-CoinCell | 1 | http://www.keyelco.com/product-pdf.cfm?p=777 |  | www.keyelco.com | 534-3000TR | 3000 | www.mouser.com
4 |  | CONN_02X01 | BTN0 BTN1 BTN2 BTN3 BTN4 BTN5 BTN6 | PTS645 | SW_SPST_PTS645 | 7 | http://www.ckswitches.com/media/1471/pts645.pdf |  | www.ckswitches.com |  | PTS645SL50SMTR92 LFS | www.mouser.com
5 | Unpolarized capacitor | C | C14 C36 C37 C38 C39 C40 C41 C42 C43 C44 C45 | 100nF | C_0603 | 11
6 | Unpolarized capacitor | C | C13 C16 C17 C19 C20 C22 C23 C24 C46 C47 | 2.2uF | C_0805_HandSoldering | 10
7 | Unpolarized capacitor | C | C25 C26 C27 C28 C29 C30 C31 C32 C33 C34 C35 C48 C49 C50 C51 C52 C53 | 22nF | C_0603 | 17
8 | Unpolarized capacitor | C | C1 C3 C4 C5 C7 C8 C9 C11 C12 C15 C21 | 22uF | C_0805_HandSoldering | 11
9 | Unpolarized capacitor | C | C2 C6 C10 C18 | 470pF | C_0603_HandSoldering | 4
10 | Diode | D | D10 D13 D14 D16 D17 | 1N4148 | D_SOD-323_HandSoldering | 5
11 | Zener Diode, small symbol, alternativ symbol | D_Zener_Small_ALT | D20 D21 | 3.6V | D_SOD-323_HandSoldering | 2 | http://www.taiwansemi.com/products/datasheet/BZT52C2V4S%20SERIES_H1709.pdf |  | http://www.taiwansemi.com/en | 821-BZT52C3V6S | BZT52C3V6S | www.mouser.com
12 | Schottky diode | D_Schottky | D12 D15 D23 D24 D25 D26 | BAT54W | D_SOD-323_HandSoldering | 6
13 | LED generic, alternativ symbol | LED_ALT | D3 D7 D22 | BLUE | LED_0805 | 3 | http://www.mouser.com/ds/2/239/Lite-On-LTST-C170TBKT-1175372.pdf |  | www.liteon.com | 859-LTST-C170TBKT | LTST-C170TBKT | www.mouser.com
14 | LED generic, alternativ symbol | LED_ALT | D2 D6 D18 | GREEN | LED_0805 | 3 | http://optoelectronics.liteon.com/upload/download/DS22-2000-073/LTST-C170KGKT.pdf |  | www.lite-on.com | 859-LTST-C170KGKT | LTST-C170KGKT | www.mouser.com
15 | LED generic, alternativ symbol | LED_ALT | D1 D5 | ORANGE | LED_0805 | 2 | https://optoelectronics.liteon.com/upload/download/DS-22-99-0185/LTST-C170KFKT.pdf |  | www.liteon.com | 859-LTST-C170KFKT | LTST-C170KFKT | www.mouser.com
16 | LED generic, alternativ symbol | LED_ALT | D0 D4 D11 D19 | RED | LED_0805 | 4 | https://optoelectronics.liteon.com/upload/download/DS-22-99-0150/LTST-C170KRKT.pdf |  | www.liteon.com | 859-LTST-C170KRKT | LTST-C170KRKT | www.mouser.com
17 | Schottky diode, small symbol | D_Schottky_Small | D8 D9 D51 D52 | STPS2L30AF | D_SMA_Handsoldering | 4 |  |  |  | 511-STPS2L30AF | STPS2L30AF | www.mouser.com
18 |  | MICRO-HDMI-D | GPDI1 | GPDI-D | hdmi-swm-19 | 1 | http://portal.fciconnect.com/Comergent/fci/drawing/10029449.pdf |  | www.amphenol-icc.com | 649-10029449-111RLF | 10029449-111RLF | www.mouser.com
19 |  | CONN_02X03 | J4 | CONN_02X03 | Socket_Strip_Straight_2x03 | 1 |  | Do not install
20 |  | CONN_02X20 | J1 J2 | CONN_02X20 | Socket_Strip_Angled_2x20 | 2 |  | Do not install
21 | Generic connector, single row, 01x03 | Conn_01x03 | J5 | VJ1 | Pin_Header_Angled_1x03_Pitch2.54mm | 1 |  | Do not install |  |  |  | www.mouser.com
22 |  | CONN_02X01 | J3 | WIFI_OFF | Socket_Strip_Straight_2x01 | 1 |  | Do not install
23 | Inductor | L | L1 L2 L3 | 2.2uH | R_1210_HandSoldering | 3 | http://psearch.en.murata.com/inductor/product/DFE252012PD-2R2M%23.pdf |  | www.murata.com | 652-SRP2512A-2R2M | DFE252012P-2R2M=P2 | www.mouser.com
24 | Connector, single row, 01x07 | SSD_13xx | OLED1 | SSD_1331 | oled_13xx | 1 | https://drive.google.com/file/d/0B5lkVYnewKTGRlpxcEdWaXNvWnM/view | Do not install | www.displaymodule.com |  | DM-OLEDC095-626 | www.mouser.com
25 | Transistor N-MOSFETwith substrate diode (general) | Q_NMOS_GSD | Q2 | 2N7002 | SOT-23_Handsoldering | 1 | https://assets.nexperia.com/documents/data_sheet/2N7002.pdf |  |  | 512-2N7002 | 2N7002 | www.mouser.com
26 | Transistor PNP (general) | Q_PNP_BEC | Q1 | BC857 | SOT-23_Handsoldering | 1 | https://assets.nexperia.com/documents/data-sheet/BC856_BC857_BC858.pdf |  |  | 771-BC857B-T/R | BC857 | www.mouser.com
27 | Resistor | R | R56 | 0 | R_0603_HandSoldering | 1 |  | Do not install
28 | Resistor | R | R38 | 0.47 | R_0603_HandSoldering | 1
29 | Resistor | R | R14 R18 R57 | 1.2k | R_0603_HandSoldering | 3
30 | Resistor | R | R40 R54 | 1.5k | R_0603 | 2
31 | Resistor | R | R24 | 100k | R_0603_HandSoldering | 1
32 | Resistor | R | R11 R12 R27 R28 R31 R32 R33 | 10k | R_0603_HandSoldering | 7
33 | Resistor | R | R7 R10 R17 R21 R39 R51 R60 | 150 | R_0603_HandSoldering | 7
34 | Resistor | R | R1 R9 R13 R34 R55 RA1 RA2 RA3 | 15k | R_0603_HandSoldering | 8
35 | Resistor | R | R63 R64 | 15k | R_0603 | 2
36 | Resistor | R | R6 R8 R29 R36 R37 R62 | 1k | R_0603_HandSoldering | 6
37 | Resistor | R | R41 R42 R43 R44 R45 R46 R47 R48 | 1k | R_0603 | 8
38 | Resistor | R | R22 R23 | 2.2k | R_0603_HandSoldering | 2
39 | Resistor | R | R49 R50 R52 R53 | 27 | R_0603_HandSoldering | 4
40 | Resistor | R | R16 R20 R59 | 330 | R_0603_HandSoldering | 3
41 | Resistor | R | R5 | 4.7M | R_0603_HandSoldering | 1
42 | Resistor | R | R3 R4 R25 R26 R30 RB2 | 4.7k | R_0603_HandSoldering | 6
43 | Resistor | R | R35 R61 | 470 | R_0603_HandSoldering | 2
44 | Resistor | R | R2 | 47k | R_0603_HandSoldering | 1
45 | Resistor | R | R15 R19 R58 | 680 | R_0603_HandSoldering | 3
46 | Resistor | R | RB1 | 18k | R_0603_HandSoldering | 1
47 | Resistor | R | RB3 | 3.3k | R_0603_HandSoldering | 1
48 | Jumper, normally closed | Jumper_NC_Small | RP1 RP2 RP3 | 0 | R_0603_HandSoldering | 3 |  |  |  |  |  | www.mouser.com
49 | Micro SD Card Socket with CD | Micro_SD_Card_CD | SD1 | SCHD3A0100 | SCHD3A100 | 1 | https://www.relayspec.com/catalogs/001285/2010/SCHD.pdf |  | www.alps.com | SCHD3A0100 | SCHD3A0100 | www.on-stars.com | www.mouser.com | 688-SCHD3A0100
50 |  | DIL8 | SW1 | DIPSW | SW_DIP_x4_W8.61mm_Slide_LowProfile | 1 | https://www.ctscorp.com/wp-content/uploads/219.pdf |  | www.jameco.com | 774-2194MST | 219-4MST | www.mouser.com
51 |  | ESP-32S | U9 | ESP-WROOM-32 | ESP32-WROOM | 1 | http://espressif.com/sites/default/files/documentation/esp32_datasheet_en.pdf | Do not install | espressif.com |  | ESP-WROOM-32 | www.mouser.com
52 | Full Speed USB to Full Handshake UART, SSOP-20 | FT231XS | U6 | FT231XS | SSOP-20_4.4x6.5mm_Pitch0.65mm | 1 | www.ftdichip.com/Documents/DataSheets/ICs/DS_FT231X.pdf |  | www.ftdichip.com | 895-FT231XS-R | FT231XS | www.mouser.com
53 | FRAM memory (EEPROM compatible) with SPI interface in 8-pin package | MB85RS16 | U10 | IS25LP032D-JNLE-TR | SOA008-150mil | 1 | http://www.issi.com/WW/pdf/25LP-WP032D.pdf |  | www.issi.com | 870-IS25LP032DJNLETR | IS25LP032D-JNLE-TR | www.mouser.com
54 | ECP5U85 | LFE5U-85F-6BG381C | U1 | LFE5U-85F-6BG381C | BGA-381_pitch0.8mm_dia0.4mm | 1 | http://www.latticesemi.com/~/media/LatticeSemi/Documents/DataSheets/ECP5/FPGA-DS-02012.pdf |  |  | 842-LFE5U85F6BG381C | LFE5U-85F-6BG381C | www.mouser.com
55 | SPI ADC | MAX11125 | U8 | MAX11125 | QFN-28-1EP_5x5mm_Pitch0.5mm | 1 | https://datasheets.maximintegrated.com/en/ds/MAX11120-MAX11128.pdf |  | www.maximintegrated.com | 700-MAX11125ATI+ | MAX11125ATI+ | www.mouser.com
56 |  | MT48LC16M16A2TG | U2 | MT48LC16M16A2TG | TSOP54 | 1 | https://www.micron.com/~/media/Documents/Products/Data%20Sheet/DRAM/256Mb_sdr.pdf |  | www.micron.com | 913-4816M16A2TG6AGTR | MT48LC16M16A2TG-6A | www.mouser.com
57 |  | DIL8 | U11 | PCA9306D | SM8 | 1 | https://www.nxp.com/docs/en/data-sheet/PCA9306.pdf |  | www.nxp.com | 771-PCA9306D-T | PCA9306D | www.mouser.com
58 | Realtime Clock/Calendar I2C Interface, DIP/SOIC/TSSOP-8 | PCF8563 | U7 | PCF8523 | SOT96-1 | 1 | https://www.nxp.com/docs/en/data-sheet/PCF8523.pdf |  |  | 771-PCF8523T/1118 | PCF8523 | www.mouser.com |  |  | https://www.nxp.com/docs/en/packing/SOT96-1_118.pdf
59 | DC-DC Converter | TLV62569DBV | U3 U4 U5 | TLV62569DBV | TSOT-25 | 3 | http://www.ti.com/lit/ds/symlink/tlv62569.pdf |  | www.ti.com | 595-TLV62569DBVR | TLV62569DBV | www.mouser.com
60 |  | USB_OTG1 | US1 US2 | MICRO_USB | USB-MICRO-B-FCI-10118192-0001LF | 2 | portal.fciconnect.com/Comergent/fci/drawing/10118192.pdf |  | www.fciconnect.com |  | 10118192-0001LF | www.mouser.com
61 | Four pin crystal (GND on pins 2 and 3), e.g. in SMD package | Crystal_GND23 | Y2 | 32768Hz | Crystal_SMD_ABS25 | 1 | http://www.iqdfrequencyproducts.com/products/pn/LFXTAL003000Reel.pdf |  | www.iqdfrequencyproducts.com | 815-ABS25-32.768KHZT | LFXTAL003000Reel | www.mouser.com
62 | Four pin crystal (GND on pins 2 and 4), e.g. in SMD package | Crystal_GND24 | Y1 | FNETHE025 | Crystal_SMD_7050_4Pads | 1 | https://www.diodes.com/assets/Datasheets/FNETHE025.pdf |  | www.diodes.com | 729-FNETHE025 | FNETHE025 | www.mouser.com
Component Groups: | 62
Component Count: | 194
Fitted Components: | 194
Number of PCBs: | 1
Total components: | 194
Schematic Version: | 1.8
Schematic Date:
BoM Date: | nedjelja, 08. travnja 2018. 21:22:50 CEST
Schematic Source: | /home/davor/src/circuits/fpga/ulx3s/ulx3s.sch
KiCad Version: | Eeschema 4.0.7+dfsg1-1

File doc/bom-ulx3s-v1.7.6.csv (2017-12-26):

FOOTPRINT | QUANTITY | REF | VALUE
Buttons_Switches_SMD:SW_DIP_x4_W8.61mm_Slide_LowProfile | 1 | SW1 | DIPSW |  | 219-4MST
Buttons_Switches_SMD:SW_SPST_PTS645 | 7 | BTN0-6 | PushButton SMD |  | PTS645SL50SMTR92 LFS
Capacitors_SMD:C_0603_HandSoldering | 1 | C14 | 100nF
Capacitors_SMD:C_0603_HandSoldering | 4 | C2 C6 C10 C18 | 470pF
Capacitors_SMD:C_0805_HandSoldering | 11 | C1 C3 C4 C5 C7 C8 C9 C11 C12 C15 C21 | 22uF
Capacitors_SMD:C_0805_HandSoldering | 8 | C13 C16 C17 C19 C20 C22 C23 C24 | 2.2uF
Diodes_SMD:D_SMA_Handsoldering | 4 | D51 D52 D8 D9 | STPS2L30AF
Diodes_SMD:D_SOD-323_Handsoldering | 6 | D10 D13 D14 D16 D17 D23 | 1N4148
Diodes_SMD:D_SOD-323_Handsoldering | 2 | D20 D21 | 3.6V |  | BZT52C3V6S
Diodes_SMD:D_SOD-323_Handsoldering | 2 | D12 D15 | BAT54W
ESP32-footprints-Lib:ESP-32S | 1 | U9 | ESP-WROOM-32 |  | DNI
Housings_DFN_QFN:QFN-28-1EP_5x5mm_Pitch0.5mm | 1 | U8 | MAX11125 |  | MAX11125ATI+
Housings_SOIC:SOIC-8_3.9x4.9mm_Pitch1.27mm | 1 | U10 | IS25LP032D-JNLE-TR SOIC-8 150mil |  | ISSI mouser 870-IS25LP032DJNLETR
Housings_SOIC:SOIC-8_3.9x4.9mm_Pitch1.27mm | 1 | U11 | PCA9306D SOIC-8 150mil |  | NXP mouser 771-PCA9306D-T
Housings_SSOP:SSOP-20_4.4x6.5mm_Pitch0.65mm | 1 | U6 | FT231XS
Keystone_3000_1x12mm-CoinCell:Keystone_3000_1x12mm-CoinCell | 1 | BAT1 | CR1225 |  | Battery holder Keystone Keystone 3000
LEDs:LED_0805 | 10 | D0 D1 D2 D3 D4 D5 D6 D7 D11 D19 | LED RED |  | LTST-C170KRKT RED
LEDs:LED_0805 | 1 | D18 | LED GREEN |  | LTST-C170KGKT GREEN
LEDs:LED_0805 | 1 | D22 | LED BLUE |  | LTST-C170TBKT Blue
Power_Integrations:SO-8 | 1 | U7 | PCF8523 150mil |  | PCF8523T/1
Resistors_SMD:R_0603_HandSoldering | 1 | R38 | 0.47
Resistors_SMD:R_0603_HandSoldering | 4 | R49 R50 R52 R53 | 27
Resistors_SMD:R_0603_HandSoldering | 3 | R17 R21 R60 | 150
Resistors_SMD:R_0603_HandSoldering | 4 | R10 R39 R7 R51 | 150
Resistors_SMD:R_0603_HandSoldering | 3 | R16 R20 R59 | 330
Resistors_SMD:R_0603_HandSoldering | 11 | R36 R37 R41 R42 R43 R44 R45 R46 R47 R48 R62 | 470
Resistors_SMD:R_0603_HandSoldering | 2 | R35 R61 | 470
Resistors_SMD:R_0603_HandSoldering | 3 | R15 R19 R58 | 680
Resistors_SMD:R_0603_HandSoldering | 3 | R6 R8 R29 | 1k
Resistors_SMD:R_0603_HandSoldering | 3 | R14 R18 R57 | 1.2k
Resistors_SMD:R_0603_HandSoldering | 1 | R40 | 1.5k
Resistors_SMD:R_0603_HandSoldering | 2 | R22 R23 | 2.2k
Resistors_SMD:R_0603_HandSoldering | 1 | RB3 | 3.3k | RA, RB 2%
Resistors_SMD:R_0603_HandSoldering | 6 | R3 R4 R25 R26 R30 RB2 | 4.7k | RA, RB 2%
Resistors_SMD:R_0603_HandSoldering | 7 | R11 R12 R27 R28 R31 R32 R33 | 10k
Resistors_SMD:R_0603_HandSoldering | 8 | R1 R9 R13 R34 R55 RA1 RA2 RA3 | 15k | RA, RB 2%
Resistors_SMD:R_0603_HandSoldering | 1 | RB1 | 18k | RA, RB 2%
Resistors_SMD:R_0603_HandSoldering | 1 | R2 | 47k
Resistors_SMD:R_0603_HandSoldering | 1 | R24 | 100k
Resistors_SMD:R_0603_HandSoldering | 1 | R5 | 4.7M
Resistors_SMD:R_0603_HandSoldering | 0 | R54 | 1.5k |  | No not install
Resistors_SMD:R_0603_HandSoldering | 0 | R56 | 0 |  | No not install
Inductors_SMD:L_1210_HandSoldering | 3 | L1 L2 L3 | 2.2uH,3A,80mOhm |  | DFE252012P-2R2M=P2 Isat > 3A Rdc < 80mOhm
Socket_Strips:Socket_Strip_Angled_2x20 | 2 | J1 J2 | CONN_02X20 |  | No not install
Socket_Strips:Socket_Strip_Straight_2x01 | 1 | J3 | WIFI_OFF |  | No not install
Socket_Strips:Socket_Strip_Straight_2x03 | 1 | J4 | CONN_02X03 |  | No not install
TO_SOT_Packages_SMD:SOT-23_Handsoldering | 1 | Q1 | BC857
TO_SOT_Packages_SMD:SOT-23_Handsoldering | 1 | Q2 | 2N7002
TSOP54:TSOP54 | 1 | U2 | MT48LC16M16A2TG |  | MT48LC16M16A2TG-7E
TSOT-25:TSOT-25 | 3 | U3 U4 U5 | TLV62569DBV |  | Texas instruments TLV62569DBV (2A)
abs25:Crystal_SMD_ABS25 | 1 | Y2 | 32768Hz |  | LFXTAL003000Reel
audio-jack:CUI_SJ-43516-SMT | 1 | AUDIO1 | JACK_TRS_6PINS |  | SJ-43516-SMT-TR
hdmi-swm-19:hdmi-swm-19 | 1 | GPDI1 | HDMI connector |  | 10029449-111RLF
lfe5bg381:BGA-381_pitch0.8mm_dia0.4mm | 1 | U1 | LFE5U-45F-6BG381C
micro-sd:MicroSD_TF02D | 1 | SD1 | Micro_SD_Card_Slot |  | SCHD3A0100
oscxo:Crystal_SMD_7050_4Pads | 1 | Y1 | FNETHE025-25MHz oscillator |  | FNETHE025
usb_otg:USB-MICRO-B-FCI-10118192-0001LF | 2 | US1 US2 | USB_micro_b_socket |  | 10118192-0001LF

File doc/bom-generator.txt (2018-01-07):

try this
https://github.com/SchrodingersGat/KiBoM

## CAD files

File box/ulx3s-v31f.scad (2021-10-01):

include <upbox.scad>

/* [STL element to export] */
// Top shell
  TShell        = 1; // [0:No, 1:Yes]
// Bottom shell
  BShell        = 1; // [0:No, 1:Yes]
// Front panel ULX3S text
  FPanel        = 1; // [0:No, 1:Yes]
// Rear panel DB9 opening
  BPanel        = 2; // [0:No, 1:DB-9 2:40-pin]
// Font color: at height 2.7: M600; change filament
// button pins
  Pins          = 1; // button pins
  Pin           = 0; // one pin

// Flat Cable holes
  FlatCable     = 1;

// Front text
  Text          = 2;// [0:No, 1:Extrude, 2:Cut]

// display_type:
// 0:none
// 1:ST7789  240x240 1.3"
// 2:ST7789  240x240 1.54"
// 3:SSD1331  96x64  0.96"
// 4:SSD1351 128x128 1.54"
// 5:SSD1306 128x64  0.96"
display_type = 1;
display_center = [1,0,0]; // XYZ center adjust X +right - left, (v3.1.7 X=1) Y +up -down, Z 0
display_rotation = 0; // display z-rotation  adjust deg +cw -ccw

// multicolor front panel
/*
;BEFORE_LAYER_CHANGE
;2.7
M600 ; Pause print to change filament
*/

/*//////////////////////////////////////////////////////////////////
              -   Heartman/Hearty 2016     -                   
              -   http://heartygfx.blogspot.com    -                  
              -       OpenScad Parametric Box      -                     
              -         CC BY-NC 3.0 License       -                      
////////////////////////////////////////////////////////////////////                                                                                                             
12/02/2016 - Fixed minor bug 
28/02/2016 - Added holes ventilation option                    
09/03/2016 - Added PCB feet support, fixed the shell artefact on export mode. 

*/////////////////////////// - Info - //////////////////////////////

// All coordinates are starting as integrated circuit pins.
// From the top view :

//   CoordD           <---       CoordC
//                                 ^
//                                 ^
//                                 ^
//   CoordA           --->       CoordB


////////////////////////////////////////////////////////////////////


////////// - Box parameters - /////////////

/* [PCB_Feet--TheBoard_Will_NotBeExported) ] */
//All dimensions are from the center foot axis
// - Coin bas gauche - Low left corner X position
PCBPosX         = 0;
// - Coin bas gauche - Low left corner Y position
PCBPosY         = 0;
// - Longueur PCB - PCB Length
PCBLength       = 30*2.54;
// - Largeur PCB - PCB Width
PCBWidth        = 17*2.54;
// Thickness of PCB
PCBThick        = 1.6;
PCBThickTol     = 0.0;
BFclr = 0.7; // bottom feet clearance
// - Heuteur pied - Feet height
FootHeight      = 7;
// - Diamètre pied - Foot diameter
FootDia         = 6;
// - Diamètre trou - Hole diameter
FootHole        = 1.8;
// - 3-foot mode, one foot width-asymmetric, 0 for normal 4-foot mode
Foot3Width = 0*2.54;

// those clearances should be larger than
// the PCB edge to hole centers distances
FootClrX = 11; // foot center to panel clearance 25 for DB-9, 11 for tight
FootClrY = 10-3; // foot center to shell wall clearance
FootmvY = 3; // move foot out of center y direction

// - Wall thickness  
Thick           = 2;//[2:5]  

/* [Box dimensions] */
// - Length  
  Length        = PCBLength+2*(2*Thick+FootClrX);
// - Width add +1.5 for 1.5" display
  Width         = PCBWidth+2*(1*Thick+FootClrY+1.5);
// - Height 25 without flat cable, 28 with flat cable
  Height        = 28.7;

/* [Box options] */
// Pieds PCB - PCB feet (x4) 
  PCBFeet       = 1;// [0:No, 1:Yes]
// - Decorations to ventilation holes
  Vent          = 0;// [0:No, 1:Yes]
// - Decoration-Holes width (in mm)
  Vent_width    = 1.5;   
// - Text you want
  txt           = "ULX3S";
// - Font size  
  TxtSize       = 6;                 
// - Font  
  Police        ="Arial Black"; 
// - Diamètre Coin arrondi - Filet diameter  
  Filet         = 3; //[0.1:12] 
// - lissage de l'arrondi - Filet smoothness  
  Resolution    = 32; //[1:100] 
// - Tolérance - Tolerance (Panel/rails gap)
  m             = 0.9;
  mz            = 1.0; // panels height tolerance
// mounting legs clearance
  MountClearance = 0.1;
  // clearance between Top and Bottom shell
  ShellClearance = 0.0;


// mounting hole diameters
MountOuterHole = 2.0;
MountInnerHole = 1.8;

// fixation leg size
MountLegSize = 0; // 10
// fixation hole z-position from center
MountHolePos = 2.5;
// distance of leg to the edge
MountLegEdge = 0*MountLegSize;

  
/* [Hidden] */
// - Couleur coque - Shell color  
Couleur1        = "Orange";       
// - Couleur panneaux - Panels color    
Couleur2        = "OrangeRed";    
// Thick X 2 - making decorations thicker if it is a vent to make sure they go through shell
Dec_Thick       = Vent ? Thick*2 : Thick; 
// - Depth decoration
Dec_size        = Vent ? Thick*2 : 0.8;

//////////////////// Oversize PCB limitation -Actually disabled - ////////////////////
//PCBL= PCBLength+PCBPosX>Length-(Thick*2+7) ? Length-(Thick*3+20+PCBPosX) : PCBLength;
//PCBW= PCBWidth+PCBPosY>Width-(Thick*2+10) ? Width-(Thick*2+12+PCBPosY) : PCBWidth;
PCBL=PCBLength;
PCBW=PCBWidth;
//echo (" PCBWidth = ",PCBW);

// flat cable connector spacing between centers
flatcable_spacing = 35*2.54;



///////////////////////////////////// - Main - ///////////////////////////////////////

  // mounting hole xy-position
  Footx = 2*Thick+FootClrX;
  Footy = Thick+FootClrY+FootmvY;
  Fh = 16.7; // top feet height

  // foot xy positions
  Fxy = [
  [Footx, Footy, 0],
  [Footx+PCBLength, Footy, 0],
  [Footx, Footy+PCBWidth, 0],
  [Footx+PCBLength, Footy+PCBWidth, 0]
  ];

module connector_cut()
{
  // mounting hole x-position
  //footx = 2*Thick+FootClrX;
  //footy = Thick+FootClrY;
  cy = 60-8;
  translate([Footx,Footy,Height-Fh-9])
  {
      // cut off for WiFi
      translate([24-10,-10,7])
        cube([21,3,3],center=true);
      // cut off for HDMI
      translate([42.3+0.2,cy,11.5])
        cube([22,10,13],center=true);
      // cut off for AUDIO
      translate([21.47-0.3,cy,11.2+0.5])
        rotate([90,0,0])
          cylinder(d=13.5,h=10,$fn=32,center=true);
      // cut off for 2.5/3.3V jumper
      translate([27.07+2.54,cy,11])
        cube([13,10,7],center=true);
      // cut off for USB1
      translate([8.89+0.2,cy,9.7])
        cube([13,10,9],center=true);
      // cut off for USB2
      translate([67.31+0.2,cy,9.7])
        cube([13,10,9],center=true);
  }    
}

// xyz positions of all buttons
// relative to feet
button_pos =
[
  [68.58,34.29,0], // btn0
  [2.54,19.05,0], // btn1
  [13.97,19.05,0], // btn2
  [57.15,8.89,0], // btn3
  [57.15,0,0], // btn4
  [45.72,0,0], // btn5
  [68.58,0,0] // btn6  
];

tube_h=9; // btn tube height
tube_id=7; // button tube inner diameter
tube_od=9; // tube outer diameter

// addition to top shell - button tubes
module top_add()
{
  // mounting hole xy-position
  //footx = 2*Thick+FootClrX;
  //footy = Thick+FootClrY;
  translate([Footx,Footy,Height-tube_h/2])
  {
      // btn hole
    for(i = [0:6])
      translate(button_pos[i])
        cylinder(d=tube_od,h=tube_h,$fn=24,center=true);
  }
  for(i = [0:3])
  {
    upbase=1;
    translate([0,0,Height-Fh/2])
    translate(Fxy[i])
    {
      translate([0,0,-upbase/2])
      cylinder(d1=6,d2=11,h=Fh-upbase,$fn=24,center=true);
      // small in-hole centering cylinders
      if(0)
      translate([0,0,-Fh/2-(PCBThick-PCBThickTol-0.001)])
        cylinder(d=3,h=PCBThick-PCBThickTol,$fn=32);
    }
  }
}

module button_pin()
{
  pin_d1=6; // top dia
  pin_h=14; // total height
  pin_d2=8; // button touch dia
  pin_h2=2.5; // button touch h

      union()
      {
        cylinder(d=pin_d1,h=pin_h,$fn=32);
        cylinder(d=pin_d2,h=pin_h2,$fn=32);
      }
}

module button_pins()
{
  translate([Footx,Footy,Height-12])
  for(i = [0:6])
    translate(button_pos[i])
      button_pin();
}
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

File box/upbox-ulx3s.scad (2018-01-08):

/*//////////////////////////////////////////////////////////////////
              -    FB Aka Heartman/Hearty 2016     -                   
              -   http://heartygfx.blogspot.com    -                  
              -       OpenScad Parametric Box      -                     
              -         CC BY-NC 3.0 License       -                      
////////////////////////////////////////////////////////////////////                                                                                                             
12/02/2016 - Fixed minor bug 
28/02/2016 - Added holes ventilation option                    
09/03/2016 - Added PCB feet support, fixed the shell artefact on export mode. 

*/////////////////////////// - Info - //////////////////////////////

// All coordinates are starting as integrated circuit pins.
// From the top view :

//   CoordD           <---       CoordC
//                                 ^
//                                 ^
//                                 ^
//   CoordA           --->       CoordB


////////////////////////////////////////////////////////////////////


////////// - Paramètres de la boite - Box parameters - /////////////

/* [PCB_Feet--TheBoard_Will_NotBeExported) ] */
//All dimensions are from the center foot axis
// - Coin bas gauche - Low left corner X position
PCBPosX         = 0;
// - Coin bas gauche - Low left corner Y position
PCBPosY         = 0;
// - Longueur PCB - PCB Length
PCBLength       = 30*2.54;
// - Largeur PCB - PCB Width
PCBWidth        = 17*2.54;
// - Heuteur pied - Feet height
FootHeight      = 7;
// - Diamètre pied - Foot diameter
FootDia         = 6;
// - Diamètre trou - Hole diameter
FootHole        = 1.8;
// - 3-foot mode, one foot width-asymmetric, 0 for normal 4-foot mode
Foot3Width = 0*2.54;

// those clearances should be larger than
// the PCB edge to hole centers distances
FootClrX = 6; // foot center to panel clearance
FootClrY = 6; // foot center to shell wall clearance

// - Epaisseur - Wall thickness  
Thick           = 2;//[2:5]  


/* [Box dimensions] */
// - Longueur - Length  
  Length        = PCBLength+2*(2*Thick+FootClrX);
// - Largeur - Width
  Width         = PCBWidth+2*(Thick+FootClrY);
// - Hauteur - Height  
  Height        = 13;
  
/* [Box options] */
// Pieds PCB - PCB feet (x4) 
  PCBFeet       = 1;// [0:No, 1:Yes]
// - Decorations to ventilation holes
  Vent          = 0;// [0:No, 1:Yes]
// - Decoration-Holes width (in mm)
  Vent_width    = 1.5;   
// - Text you want
  txt           = "12*";
// - Font size  
  TxtSize       = 5;                 
// - Font  
  Police        ="Arial Black"; 
// - Diamètre Coin arrondi - Filet diameter  
  Filet         = 2;//[0.1:12] 
// - lissage de l'arrondi - Filet smoothness  
  Resolution    = 20;//[1:100] 
// - Tolérance - Tolerance (Panel/rails gap)
  m             = 1.5;
// mounting legs clearance
  MountClearance = 0.1;
  // clearance between Top and Bottom shell
  ShellClearance = 0.1;


// mounting hole diameters
MountOuterHole = 2.5;
MountInnerHole = 1.8;


/* [STL element to export] */
//Coque haut - Top shell
  TShell        = 0;// [0:No, 1:Yes]
//Coque bas- Bottom shell
  BShell        = 1;// [0:No, 1:Yes]
//Panneau arrière - Back panel  
  BPanel        = 0;// [0:No, 1:Yes]
//Panneau avant - Front panel
  FPanel        = 0;// [0:No, 1:Yes]
//Texte façade - Front text
  Text          = 1;// [0:No, 1:Yes]


  
/* [Hidden] */
// - Couleur coque - Shell color  
Couleur1        = "Orange";       
// - Couleur panneaux - Panels color    
Couleur2        = "OrangeRed";    
// Thick X 2 - making decorations thicker if it is a vent to make sure they go through shell
Dec_Thick       = Vent ? Thick*2 : Thick; 
// - Depth decoration
Dec_size        = Vent ? Thick*2 : 0.8;

//////////////////// Oversize PCB limitation -Actually disabled - ////////////////////
//PCBL= PCBLength+PCBPosX>Length-(Thick*2+7) ? Length-(Thick*3+20+PCBPosX) : PCBLength;
//PCBW= PCBWidth+PCBPosY>Width-(Thick*2+10) ? Width-(Thick*2+12+PCBPosY) : PCBWidth;
PCBL=PCBLength;
PCBW=PCBWidth;
//echo (" PCBWidth = ",PCBW);



/////////// - Boitier générique bord arrondis - Generic Fileted box - //////////

module RoundBox($a=Length, $b=Width, $c=Height){// Cube bords arrondis
                    $fn=Resolution;            
                    translate([0,Filet,Filet]){  
                    minkowski (){                                              
                        cube ([$a-(Length/2),$b-(2*Filet),$c-(2*Filet)], center = false);
                        rotate([0,90,0]){    
                        cylinder(r=Filet,h=Length/2, center = false);
                            } 
                        }
                    }
                }// End of RoundBox Module

      
////////////////////////////////// - Module Coque/Shell - //////////////////////////////////         

module Coque(top=0){//Coque - Shell  
    Thick = Thick*2;  
    difference(){    
        difference(){//sides decoration
            union(){    
                     difference() {//soustraction de la forme centrale - Substraction Fileted box
                      
                        difference(){//soustraction cube median - Median cube slicer
                            union() {//union               
                            difference(){//Coque    
                                RoundBox();
                                translate([Thick/2,Thick/2,Thick/2]){     
                                        RoundBox($a=Length-Thick, $b=Width-Thick, $c=Height-Thick);
                                        }
                                        }//Fin diff Coque                            
                                difference(){//largeur Rails        
                                     translate([Thick+m,Thick/2,Thick/2]){// Rails
                                          RoundBox($a=Length-((2*Thick)+(2*m)), $b=Width-Thick, $c=Height-(Thick*2));
                                                          }//fin Rails
                                     translate([((Thick+m/2)*1.55),Thick/2,Thick/2+0.1]){ // +0.1 added to avoid the artefact
                                          RoundBox($a=Length-((Thick*3)+2*m), $b=Width-Thick, $c=Height-Thick);
                                                    }           
                                                }//Fin largeur Rails
                                    }//Fin union                                   
                               translate([-Thick,-Thick,Height/2]){// Cube à soustraire
                                    cube ([Length+100, Width+100, Height], center=false);
                                            }                                            
                                      }//fin soustraction cube median - End Median cube slicer
                               translate([-Thick/2,Thick,Thick]){// Forme de soustraction centrale 
                                    RoundBox($a=Length+Thick, $b=Width-Thick*2, $c=Height-Thick);       
                                    }                          
                                }                                          

                if(top > 0.5)
                for(i = [0:1])
                difference(){// Fixation box legs
                    union(){
                        translate([i*(Length-6*Thick-10)+3*Thick+5,Thick,Height/2]){
                            rotate([90,0,0]){
                                    $fn=6;
                                    cylinder(d=16,Thick/2);
                                    }   
                            }
                            
                       translate([i*(Length-6*Thick-10)+3*Thick+5,Width-Thick,Height/2]){
                            rotate([-90,0,0]){
                                    $fn=6;
                                    cylinder(d=16,Thick/2);
                                    }   
                            }
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

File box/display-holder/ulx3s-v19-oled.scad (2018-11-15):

body=[27,5,11];
hole_d=2.2; // 2.2 narrow, 2.3 wide
hole_h=2.0;
hole_dist=23.60;

hdmi_width=17;
hdmi_height=14;
audio_width=5;
audio_height=13;
voltage_width=8;
voltage_height=7;

difference()
{
  union()
  {
    cube(body,center=true);
    // screw pins
    for(i=[-1:2:1])
      translate([hole_dist/2*i,0,body[2]/2+hole_h/2])
      cylinder(d=hole_d,h=hole_h+0.1,$fn=6,center=true);
  }
  // cut clearing for ribbon cable
  translate([0,0,body[2]/2])
    cube([hole_dist-5,10,2],center=true);
  // cut bottom stand
  // dip switch 
  // hdmi capacitors
  translate([-hole_dist/2+hdmi_width/2-3,+5,-body[2]/2])
    cube([hdmi_width,10,hdmi_height],center=true);
  // voltage selector
  translate([+hole_dist/2-voltage_width/2+0.01,-6,-body[2]/2])
    cube([voltage_width,10,voltage_height],center=true);
  // audio jack
  translate([hole_dist/2+audio_width/2,0,-body[2]/2])
    cube([audio_width,10,audio_height],center=true);
  // 45 deg transtion
  translate([hole_dist/2+audio_width/2+1,0,-body[2]/2+audio_height-audio_width-1.5])
    rotate([0,45,0])
      cube([audio_width,10,audio_width],center=true);
}

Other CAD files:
box/display-holder/ulx3s-v19f-lcd-st7789-13.scad
box/display-holder/ulx3s-v17-oled.scad
box/display-holder/ulx3s-v19f-lcd-st7789-15.scad
box/screwbox/ulx3s-v17.scad
box/screwbox/ulx3s-v19.scad
box/screwbox/ulx3s-v19f.scad
box/screwbox/ulx3s-v31f.scad
box/screwbox/upbox.scad
box/snapbox/boxhook.scad
box/snapbox/snapbox.scad
box/snapbox/ulx3s.scad
box/snapbox/ulx3s_pcb.scad

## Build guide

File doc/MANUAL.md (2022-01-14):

# ULX3S Manual

# Connectors

    US1    Main micro-USB for power, program and communication.
           All onboard hardware can be programmed or reconfigured
           over US1: FPGA, FLASH, WiFi, RTC.

    US2    Auxiliary micro-USB connected directly to FPGA pins
           for experimenting with user-defined USB cores or to
           connect PS/2 keyboard or mouse using USB-OTG and 
           USB-PS/2 adapters.
           Board provides power to US2.
           Board v1.7 can't be powered from US2 by default.
           Board v2.0 and higher can be powered from US2.
           If you want to power board v1.7 from US2, reverse diode
           D9 near US2 connector or short D9 with a wire.

    GPDI   Plug for cable to digital monitor or TV,
           4 TMDS+- video out differential pairs
           1 HEAC+- pair (future expansion)
           SDA,SCL  I2C (DDS EDID)
           CEC      remote control
           +5V      supply to enable plug-in detection

    AUDIO  3.5 mm jack with 3 channels for earphones
           and digital audio or composite video (analog TV)
           Suitable cables are 3.5mm to 3-RCA (cinch)
           Red-White-Yellow for iPhone/iBook/NOKIA.
           Sony cables are the most popular and look identical
           but are not suitable, they have GND at Ring2!
           Tip:    Left analog audio
           Ring1:  Right analog audio
           Ring2:  Digital audio SPDIF
           Sleeve: GND

    OLED   7-pin 2.54 mm header OLED1 for ST7789/SSD1331/SSD1351/SSD1306
           COLOR/BW LCD/OLED 3.3V
           pinout:   CS DC RES SDA SCL VCC GND

    JTAG   6-pin 2.54 mm header J4 for external JTAG programmer
           pinout:   3V3 GND
                     TCK TDI
                     TDO TMS
    
    GPIO   40-pin 2.54 mm double-row connectors J1 and J2 for GPIO 
           at 3.3V logical level with 56 pins from which are:
           J1 GP,GN 0-7 are single-ended pins.
           J1 GP,GN 8-13 are differential bidirectional pairs.
           J2 GP,GN 14-21 are differential bidirectional pairs.
           J2 GP,GN 22-27 are single-ended pins.
           Differential pairs can be used also as single-ended pins.
           J1 GP,GN 12 is differential primary clock capable.
           J1 GP,GN 0,1 are single-ended primary clock capable.
           J1 GP 13 and J2 GN 17 are general routing (non-primary)
           clock capable.
           J1 pins GP,GN 9-13 are shared with ESP32 WiFi on PCB v1.7.
           J1 pins GP,GN 11-13 are shared with ESP32 WiFi on PCB >v2.0.
           J2 pins GP,GN 14-17 are shared with ADC.
           4 PMOD connectors can be made out of it
           (GND and 3.3V power are on the right place)
           J1-J2 distance is suitable to be plugged into triple
           protoboard using a single row of J1/J2.      
           J2 has also 5V IN/OUT (be careful, GPIO pins are not
           5V tolerant).

    SD     Micro SD card, all signal pins are routed to FPGA and
           shared with ESP32

    ESP32  Placeholder to solder ESP32 module.
           ESP32 can provide standalone web interface for uploading
           bitstream into FPGA and its config FLASH. 

# Constraints (board pinout)

For [PCB v1.7 patched for ESP32 to work](/doc/constraints/ulx3s_v17patch.lpf)

For [PCB v2.x.x and v3.0.x](/doc/constraints/ulx3s_v20.lpf)

# Power

Plug US1 into PC or USB charger and board should power up.

Initial voltage rise at USB 5V line will trigger board powering
up and holding the power.

On PCB v1.7, USB-serial chip FT231X will always be powered from 5V USB.
The board has switching voltage regulators
which can be turned off to reduce power consumption.

On PCB v2.0 and later, USB-serial chip FT231X will be directly
powered only from US1. If board is powered from US2, there is diode
preventing 5V to FT231X power pin, but FT231X will still be weakly
back-powered from its other pins connected with rest of the board 
and it will appear as some load. For most practical cases, we
are lucky that FT231X appears as high-z when not directly powered.
Pin loads from unpowered FT231X may sometimes prevent
JTAG'ing from ESP32 or external JTAG, so for more reliable JTAG
we recommend to keep FT231X powered.

Green LED D18 behaviour is the "Power LED". Green LED ON will keep 
board powered up. By factory default, when USB-serial chip
is enumerated by PC, Green LED will turn ON.
Normally when board is plugged into USB charger Green LED may shortly
blink and stay OFF, but board will keep being powered.

Board PCB v1.7 must be hardware patched to be able to reliably
enter shutdown mode. (It will keep waking up).

Onboard 3V lithium battery CR1225 is only to keep RTC clock running
and hold its configuration for a year or so. 3V battery is too
weak to power up complete ULX3S board.

A regulated clean and stable power supply is required,
like USB port on PC or USB charger. 5V/0.5A should be enough for fully
loaded and constantly active FPGA, SDRAM, LEDS, AUDIO, SD,
ESP32 WiFi and OLED. Maximum tolerant USB voltage is 6V. Exceeding
this limit will instantly damage the board!

If other devices are connected and powered from ULX3S J1/J2 GPIO/PMOD
connectors then more than 0.5A may be required - board can draw 2-3A
when externally loaded.

On J2 connector there are 2 pins for 5V external power input
and output. They are located on top right, near pin labeled 27 
and US2 connector. On PCB v2.0 and later boards, both J2 5V pins are
connected to US2 5V but there are onboard jumpers which can be
carefully cut and schottky diodes soldered on their pads to route the
5V power in and/or out of the board.

Powering only from 3.3V is not possible because switching regulators
need 5V to generate 2.5V and 1.1V.

Switching regulators use ferrite core inductors L1,L2,L3 which can saturate
at magnetic fields above 0.3T. Never approach neodymium magnets
near powered board.

# Low Power Mode

RTC without battery will keep waking up the board as factory default.
3V battery CR1225 and configured RTC chip is required for the board to
enter shutdown mode. There are several ways to wake up the board:

    1) Press BTN0
    2) Re-plug US1 micro-USB cable
    3) RTC ALARM (using MCP7940N or PCF8523 arduino example)
    4) Turn on Green LED D18 (using ftx_prog or libftdi)

Just a short pulse at RTC (ALARM INT1 shortly pull down) or
Green LED shortly going HIGH is enough to wake up the board.

There is SHUTDOWN pin where FPGA can turn OFF the board.
This pin is not correctly routed on PCB v1.7 and needs
hardware upgrade to make it work.

To accept SHUTDOWN D18 (green LED on top side near SD card)
must be OFF and D11 found on back side of the board near J1 pin 22.

D18 is controlled by USB-serial chip and when lit indicates that
USB-serial chip holds board constantly powered up.

D11 is controlled by RTC chip and when dimly lit (visible in the dark),
it indicates that RTC chip has ALARM INT1 pin set as inactive (high-Z, open drain).
Due to its primary function as voltage drop in analog circuit, D11 never gets fully
lit like other LEDs.

RTC must have 3V battery and registers set for current time, alarm
time and alarm logic to trigger RTC ALARM in the future. Then
board is ready to accept SHUTDOWN signal, which is indicated when LED D11
is very dimly lit, visible in the dark.

While D11 is dimly lit, and D18 is OFF, board can be powered down by
setting SHUTDOWN signal to 1 from FPGA logic or by
connecting 1k resistor between SHUTDOWN pin of R13 and 3.3V, carefully and
only for a moment. When RTC ALARM is triggered, RTC ALARM INT1 open-drain
pull down will become active and board should turn ON.

When D11 is OFF, or D18 is ON, it is indicating that board can't enter SHUTDOWN,
probably RTC ALARM flag has to be cleared or other RTC registers configured.

To get D18 OFF, either power board from US2 connector, power it from US1
with charger which doesn't do USB enumeration or power it from PC at US1
but reconfigure USB chip to turn D18 OFF:

    ftx_prog --cbus 3 DRIVE_0

# Precompiled opensource tools for all platforms

Here is daily-fresh binary build of
[OSS ECP5 opensource tools for all platforms](https://github.com/YosysHQ/oss-cad-suite-build/releases/)
with ECP5 compilers, fujprog and openFPGALoader.

Here was nightly-fresh binary build of
[OrangeCrab ECP5 opensource tools for all platforms](https://github.com/open-tool-forge/fpga-toolchain/releases).
Last known successful build for linux and apple
was [2021-10-06](https://github.com/YosysHQ/fpga-toolchain/releases/tag/nightly-20211006)
with ECP5 compilers and openFPGALoader.
It works for ULX3S but is actually made for
[OrangeCrab](https://gregdavill.github.io/OrangeCrab/r0.2/),
interesting miniature ECP5 board, a must-have item.

Unzip it anywhere and set shell command search path:

    Linux              : export PATH=[path-to-bin]:$PATH
    MacOS              : export PATH=[path-to-bin]:$PATH
    Windows Powershell : $ENV:PATH = "[path-to-bin];" + $ENV:PATH
    Windows cmd.exe    : PATH=[path-to-bin];%PATH%

# Precompiled linux opensource tools (KOST)

Not so often updated but almost all you need for
linux, including Verilog and VHDL compilers, USB programmers,
everything except diamond is in
[KOST's ULX3S git releases](https://github.com/alpin3/ulx3s/releases).
Installation is simple:

    dpkg -i ulx3s-toolchain_2020.05.24-2_amd64.deb

Tools contain latest "openocd" with ft231x support.
System's "openocd" should be removed if it was
installed before:

    apt-get remove --purge openocd

# Programming options

To program ULX3S bitstream, there are many programming options:

[fujprog source from GIT](https://github.com/kost/fujprog)

[ujprog source from GIT](https://github.com/f32c/tools)
or [ujprog binary from EMARD](https://github.com/emard/ulx3s-bin/tree/master/usb-jtag)
or [ujprog binary from FER](http://www.nxlab.fer.hr/dl)
Accepts *.bit or *.svf files which all tools can generate.

[OpenFPGA Loader](https://github.com/trabucayre/openFPGALoader)
can do everyting fujprog can, at the same speed or slightly
faster. Accepts *.bit files which all tools can generate.
Supports not only ULX3S but many other boards and is actively developed.

EMARD's fork of Xark's [FleaFPGA-JTAG source](https://github.com/emard/FleaFPGA-JTAG)
or [FleaFPGA-JTAG binary](https://github.com/emard/ulx3s-bin/tree/master/usb-jtag)
Accepts *.vme files which AFAIK can be created only with closed
source tools (diamond) but cannot be created with open source tools
(trellis).

[OpenOCD soruce](https://sourceforge.net/p/openocd/code/ci/master/tree)
or [OpenOCD binaries 2019 or later](https://github.com/gnu-mcu-eclipse/openocd/releases)
(ft232r interface configured for ULX3S FT231X pinout). Accepts *.svf files
which all tools can generate. It is much slower than f/ujprog.

Onboard [ESP32 WiFi FTP](https://github.com/emard/esp32ecp5).
It is much faster than f/ujprog and can also remotely write to
FLASH and SD card. Accepts *.bit files which all tools can generate.

Onboard ESP32 WiFi web interface. Accepts *.svf files which all tools can generate.

External USB-JTAG programmer connected to JTAG header.

Most external JTAGs should work with OpenOCD.
FT2232 or FT4232 JTAGs are recommended as they are
fast, compatible and work with Lattice Diamond native programmer.
Get Lattice original FT2232 JTAG cable or some generic FT2232 JTAG like
[FT2232 breakout board from DangerousPrototypes](http://dangerousprototypes.com/docs/FT2232_breakout_board).

# USB port "US1" factory default

If you have receved your fresh board it will have FT231X already
programmed, so you can skip this ftx_prog section. You can get back
here when want to return board to factory default state.

It is good idea to write on a papaer or save in a file original
USB serial number and description strings of your board if
accidentaly overwritten.

Factory default (empty) onboard FT231X has to be initialized in order
to be autodetected by "ujprog" or "FleaFPGA-JTAG" use ftx_prog.

This needs to be done only once and board will remember it
after power down. Settings enable max USB power consumption of 500mA
set autodetectable product/manufacturer name of FT231X chip, serial
number, set proper USB-serial activity LED and sets CBUS line to
wake up board when FT231X is enumerated by host computer (PC).

    ftx_prog --max-bus-power 500
    ftx_prog --manufacturer "FER-RADIONA-EMARD"
    ftx_prog --product "ULX3S FPGA 12K v3.0.3"
    ftx_prog --new-serial-number 120001
    ftx_prog --cbus 2 TxRxLED
    ftx_prog --cbus 3 SLEEP

Optionally you can change "45K" to "25K" or "12K" in regard with FPGA chip size.
Re-plug the USB and it will appear as new name which can be autodetected
with USB-serial JTAG tool.

# Programming over USB port "US1"

If running linux, some udev rule is practical in order to allow non-root users
(in given example, members of "dialout" group) access to the USB-serial JTAG:

    # file: /etc/udev/rules.d/80-fpga-ulx3s.rules
    # this is for usb-serial tty device
    SUBSYSTEM=="tty", ATTRS{idVendor}=="0403", ATTRS{idProduct}=="6015", \
      MODE="664", GROUP="dialout"
    # this is for ujprog libusb access
    ATTRS{idVendor}=="0403", ATTRS{idProduct}=="6015", \
      GROUP="dialout", MODE="666"

"fujprog" or "ujprog" tool acceps BIT or SVF files for uploading to the FPGA SRAM
or FLASH.

    fujprog bitstream.bit
    fujprog -j flash bitstream.bit
    fujprog bitstream.svf

"openFPGALoader" tool accepts BIT files or gzipped BIT files for uploading
to the FPGA SRAM or
FLASH.

    openFPGALoader --board=ulx3s bitstream.bit
    openFPGALoader -b ulx3s bitstream.bit.gz

    openFPGALoader --board=ulx3s --write-flash bitstream.bit
    openFPGALoader -b ulx3s -f bitstream.bit.gz

Here is a hacky shell script for most common uses of "fujprog"
replaced with "openFPGALoader", assuming 1-argument call is
to program SRAM, 3-argument call is to program FLASH

    chmod +x /usr/local/bin/fujprog
    cat /usr/local/bin/fujprog
    #!/bin/sh -e
    if [ $# -eq 1 ]
    then
      openFPGALoader --board=ulx3s ${1}
    fi
    if [ $# -eq 3 ]
    then
      openFPGALoader --board=ulx3s --write-flash ${3}
    fi

"FleaFPGA-JTAG" tool accepts VME files for uploading to the FPGA SRAM or onboard 
SPI FLASH chip. SRAM VME file is simple to make, but when generating 
FLASH VME file, follow the Lattice 
TN02050 document: 
"Programming External SPI Flash through JTAG for ECP5/ECP5-5G"
section:
"6. Programming the SPI Flash with bitstream file using Diamond Programmer"
and select FLASH chip type:

    Family: SPI Serial Flash
    Vendor: Micron
    Device: SPI-M25F32
    Package. 8-pin VDFPN8
    Verify: No

When it creates VME file, pass it to FleaFPGA-JTAG argument.
Disabled "verify" will make flashing fast, but if enabled, expect to wait
5-15 minutes. You don't need verify because bitstream always checks
its own CRC and it will just not load if FLASHed with errors.

    FleaFPGA-JTAG bitstream-flash.vme

"OpenOCD" tool accepts SVF files and can upload to SRAM or onboard FLASH.
For details see their ft232r driver documentation. In short, this
config file should help to get started, modified to set actual
CHIP_ID and bitstream.svf:

file "ft231x.ocd"

    # file: ft231x.ocd
    interface ft232r
    ft232r_vid_pid 0x0403 0x6015
    # ft232r_serial_desc 123456
    ft232r_tck_num DSR
    ft232r_tms_num DCD
    ft232r_tdi_num RI
    ft232r_tdo_num CTS
    ft232r_trst_num RTS
    ft232r_srst_num DTR
    ft232r_restore_serial 0x15
    adapter_khz 1000

file "ecp5.ocd"

    # file: ecp5.ocd
    telnet_port 4444
    gdb_port 3333

    # JTAG TAPs
    jtag newtap lfe5 tap -expected-id 0x21111043 -irlen 8 -irmask 0xFF -ircapture 0x5

    # -expected-id should match ECP5 CHIP_ID:
    # 12F: 0x21111043
    # 25F: 0x41111043
    # 45F: 0x41112043
    # 85F: 0x41113043

    init
    scan_chain
    svf -tap lfe5.tap -quiet -progress bitstream.svf
    shutdown

commandline

    openocd --file=ft231x.ocd --file=ecp5.ocd

# Programming over USB port "US2"

There is possibility to program ULX3S SPI config FLASH thru
US2 connector and
a [fork of hackaday 2019 badge DFU bootloader](https://github.com/emard/had2019-playground/tree/master/projects/bootloader)
or [fork of tinyfpga bootloader](https://github.com/tinyfpga/TinyFPGA-Bootloader) loaded
to FPGA, either loaded from US1 temporary to FPGA SRAM or permanently 
to SPI config FLASH. Bootloader uses multiboot feature of ECP5 FPGA.

DFU bootloader is very stable, fast, has multiplatform compatible tools
to write flash (dfu-util, openFPGALoader, and others) so it can be
regularly used. It enumerates as OpenMoko DFU device. Examples:

    dfu-util -a0 -D bitstream.bit
    dfu-util -a0 -e

    openFPGALoader --board=ulx3s_dfu bitstream.bit
    openFPGALoader -b ulx3s_dfu bitstream.bit.gz

Tinyfpga bootloader is less stable, sensitive to cable length and
USB port type and its tool should be compiled from C source.
It enumerates as some vendor specific USB-HID USB device
and "tinyfpgasp" application can be used to write or read arbitrary
image to FPGA SPI config FLASH.

ULX3S with fully functional US2 bootloader can be used to program
FPGA config FLASH without use of USB-serial chip FT231X.

For bootloader convenience, it is recommended to solder D28 diode
at empty placeholder located on back side near OLED and JTAG header.
Observe diode polarity, see how other similar diodes are soldered on ULX3S.
Any general purpose or schottky diode in SOD-323 package will fit
like 1N914 1N4148 BAT54W etc. This diode will convert BTN0 function
to unconditionally switch to next multiboot image by pulling down
FPGA PROGRAMN pin. Without diode, option is to replug USB cable end
hold BTN1 to enter bootloader or to assign BTN to PROGRAMN in user's
bitstream.

User bitstream should be uploaded to byte address 0x200000 of SPI config
FLASH at 12/25/45F/85F.

Bootloader in multiboot mode can reside in multiple copies on SPI config
FLASH chip. "primary"
bootloader image is at byte address 0 of SPI config FLASH.
Near the end of FLASH bank are 256 bytes with some special FPGA
lattice boot state machine commands (detailed meaning and format not yet
known, it's like some primitive CPU assembly) that setups and controls
multiboot function.

User should try not to overwrite any of boot related areas with something
else otherwise US1 or JTAG recovery will be required. "esp32ecp5" tools
support write protection of the bootloader at FLASH chip hardware level
to prevent accidental overwrite but remain upgradeable. Some FLASH chips
like Winbond can be set to keep bootloader persistent and not upgradeable.

# Programming over JTAG header

Any openocd compatible JTAG like FT2232 can be connected to JTAG header
and it will program SRAM and FLASH at maximum speed possible.
Even Diamond programmer can use any FT2232 module as a native programmer,
with a little help - it will work after first bitstream is programmed
over FT2232 with openocd. If FT2232 is equipped with EEPROM you can use
original "FT_PROG" for windows or this linux tool to read/write the EEPROM
and confgure it:

    apt-get install ftdi-eeprom
    man ftdi_eeprom

Openocd accepts SVF files, everything applies the same as for VME files

    ddtcmd -oft -svfsingle -revd -if ulx3s_flash.xcf -of bitstream.svf

Connect JTAG cable to ULX3S JTAG header with female-female color wires.
Carefully observe the pinout. It's standard pinout to MPSSE bus A or B
written as TCK/TDO/TDI/TMS either on the JTAG board/cable or in
manual/schematics. The pinout also appears as comments in the
file "ft2232.ocd" listed below.

To be on safe side, do not to connect 3.3V line unless required by JTAG cable manual.
3.3V line is not needed for most cables as they use their own USB supply and
have default 3.3V TTL level. 3.3V power rail from ULX3S is 2A current
capable and can damage the cable if accidentally connected to wrong pin.

For FT2232 generic cable, this openocd config file can be used with above
file "ecp5.ocd" to program "bitstream.svf":

file "ft2232.ocd"

    # file: ft2232.ocd

    interface ftdi
    # ftdi_device_desc "Dual RS232-HS"
    ftdi_vid_pid 0x0403 0x6010
    ftdi_layout_init 0x3088 0x1f8b

    # default is port A if unspecified
    # pinout ADBUS 0-TCK 1-TDI 2-TDO 3-TMS 
    #ftdi_channel 0

    # uncomment this to use port B
    # pinout BDBUS 0-TCK 1-TDI 2-TDO 3-TMS 
    #ftdi_channel 1

    adapter_khz 25000

commandline

    openocd --file=ft2232.ocd --file=ecp5.ocd

External FT2232 JTAG cable can be used by Lattice Diamond native programmer
on linux. Prior to use the FT2232 port A or B which is connected as JTAG,
USB-serial kernel driver must be detached from the FT2232 port. 
To detach detach port B manually:

    ls /sys/bus/usb/drivers/ftdi_sio
    1-6.2:1.0  1-6.2:1.1  bind  module  uevent  unbind
    echo -n "1-6.2:1.1" > /sys/bus/usb/drivers/ftdi_sio/unbind

To detach port B automatically:

    #/bin/bash
    allow_io=`lsusb | sed -n 's/^Bus \([0-9]*\) Device \([0-9]*\): ID 0403:6010 .*/\1\/\2/p'`
    unbind_tty=`ls /sys/bus/usb/drivers/ftdi_sio/ | sed -n 's/\(.*\:1\.1\).*/\1/p'`
    sudo chmod a+rw \/dev\/bus\/usb\/$allow_io
    sudo sh -c "echo $unbind_tty > /sys/bus/usb/drivers/ftdi_sio/unbind"

When USB-serial driver is detached from port A or B, Lattice Diamond programmer
can use this port as native JTAG programmer. See also
[Versa under Linux](https://section5.ch/index.php/2017/01/26/ecp5g-versa-board-under-linux/).

For JTAG sharing with ESP32 port B should be set to high impedance
and the experimentally found solution is to set this port to FIFO or OPTO
using "ftdi_eeprom" tool
source is here
[ftdi_eeprom source](https://www.intra2net.com/en/developer/libftdi/index.php)
there's also
[ftdi_eeprom readme](http://developer.intra2net.com/git/?p=libftdi;a=blob;f=README.build)
and the binary is already in linux distro:

    apt-get install ftdi_eeprom

make "ftdi_eeprom.conf" config file, set manufacturer/product strings
to your liking but important line for high impedance for port B is
to set it as FIFO or OPTO:

    chb_type=FIFO

write config to eeprom:

    ftdi_eeprom --flash-eeprom ftdi_eeprom.conf

re-plug USB to reload new eeprom content.

# Preparing WiFi (passthru)

Passthru bitstream should be written to FPGA config flash
in order to program ESP32 FLASH and efuse by US1 usb-serial port.
Get binary passthru suitable for ULX3S board version and
FPGA chip 12/25/45/85 from 
[ulx3s-bin passhtru](https://github.com/emard/ulx3s-bin/tree/master/fpga/passthru)
or compile it from [ULX3S passthru source](https://github.com/emard/ulx3s-passthru)

    fujprog -j flash passthru.bit

"Passthru" bitstream configures FPGA to route lines from USB-serial to ESP32.

# Preparing WiFi (ESP32 efuse)

Skip this section if unsure.

ESP32 has one-time programmable efuses that need to be
properly set for using ESP32 with SD card.
SD card needs pull-up on all of its pins.
ESP32 with unprogrammed efuse needs pin GPIO12 pull-down in
order to boot from its FLASH and as GPIO12 is shared with
SD we have conflicting situation which can be resolved by
programming efuse.

efuse should be programmed by ULX3S manufacturer during test and setup phase.
A wrong efuse setting will make ESP32 module unbootable and only
fix is to replace it with new ESP32.

Remove SD card and burn efuse to ignore GPIO12 by fixing internal
module's FLASH voltage to 3.3V. This is in assumption that inside of
ESP32 is FLASH that works at 3.3V and it is currently true for all known
ESP32 WROOM modules mounted on ULX3S. If you have WROVER module, efuse
setting is different for 1.8V FLASH or it may work with SD card without
this efuse setting so don't do it. Here are archived
[ESP32 serial tools](https://github.com/emard/ulx3s-bin/tree/master/esp32/serial-uploader)
which are known to work or you can use latest from ESP.

    # WROVER only - don't apply to WROOM
    python serial-uploader/espefuse.py --port /dev/ttyUSB0 set_flash_voltage 3.3V

After this there is no way back. ESP32 should boot again and accept SD cards.

# Programming over WiFi (ESP32 micropython)

[Micropython ESP32 ECP5 programmer](https://github.com/emard/esp32ecp5)
can be used from WiFi remote shell prompt or
FTP or pull data from remote WEB server.
Faster than (f)ujprog, ESP32 keeps it all in micropython source
for easy user-customizeation and other applications.
Easy programming, rapid development.

# Programming over WiFi (ESP32 firmware)

ESP32 firmware provides standalone JTAG SVF player over web HTTP and TCP interface for
programming and flashing in convenient and OS independent way. Web interface
requires no client software installed but web browser. It is much faster than
FT231X but still not as fast as FT2232. It accepts SVF files but you need to limit
SVF command size to max 8 kilobits "-maxdata 8", effectively it will split
upload into many shorter SVF commands because ESP32 doesn't have enough
memory to buffer entire bitstream delivered in a long single SVF command.

    ddtcmd -oft -svfsingle -revd -maxdata 8 -if ulx3s_flash.xcf -of bitstream.svf

Write "passthru" to FPGA config flash as described above in section "Preparing WiFi
(passthru)".
Install Arduino and its ESP32 support, and
install Emard's library [LibXSVF-ESP](https://github.com/emard/LibXSVF-ESP),
required library dependencies and 
[ESP32 SPIFFS uploader](https://github.com/me-no-dev/arduino-esp32fs-plugin/releases/tag/v0.1)
Version "ESP32FS-v0.1.zip" worked for me.

In Arduino boards manager select this ESP32 board:

    DOIT ESP32 DEVKIT V1

Select "Examples->LibXSVF->websvf" and optionally change
its default ssid/password. Compile and upload the code by
clicking "Sketch->Upload", check reports on lower terminal
window, successfull upload will finish with this:

    Hash of data verified.
    Leaving...
    Hard resetting...

Then upload the web page content to ESP32 FLASH filesystem,
at websvf window click "Tools->ESP32 Sketch Data Upload".
successful upload will finish with same as above.

ESP32 will try to connect to your local WiFi as client with

default ssid=websvf password=12345678
Insert SD card with file "ulx3s-wifi.conf" in SD root directory:

    {
       "host_name": "ulx3s",
       "ssid": "ulx3s",
       "password": "testpass",
       "http_username": "user",
       "http_password": "pass"
    }

By editing this file you can set
ssid and password for connection
to your local WiFi access point.

If client connection is unsuccessful ESP32 it will become
access point with the same ssid and password, but so far many people
reported unsuccessful connection attempts from PC to ESP32 in AP mode.
If you want to try, AP mode ESP32 web address is "http://192.168.4.1"
and internet should not to work in this case :).

If ESP32 connected as a client, IP address will vary depending
on local network. Discover it by using WiFi access
point web interface, ARP, NMAP, or by sniffing it.
On the ESP32 page something like this will appear:

      Select SVF File or use minimal or svfupload.py
      [File] File not selected
      [Upload]
      [0%              ]

Navigate file selector to bitstream.svf file, it will show
its size in KB. Then click "Upload", progress bar will run
from 0% to 100% in few seconds (if it's SRAM upload) and
bitstream will be started. FLASH can also be written from
web iterface it takes 2-3 minutes. Also on the web interface
there's available for download a small python commandline 
upload tool.

Note that FPGA can enable or disable ESP32 module. If ESP32
is disabled by newly uploaded bistream, some alert window will
pop-up after otherwise successful upload because ESP32 cannot
close HTTP session properly.
To make it go smooth, in the bitstream make FPGA pin "wifi_en"
as input (HIGH-impedance, pull up).

Technically, ESP32 can be loaded with such a code that
permanently holds JTAG lines while FPGA can at the same time
have in FLASH a bitstream that permanenly enables ESP32.
Such combination will preventing JTAG from working so
ULX3S board may become "Bricked". There is jumper J3 to disable
ESP32, its left of SD card slot. Note boards PCB v1.7 need
upgrade for this jumper to work correctly.

Precompiled ESP32 firmware from
[ESP32 LibXSVF-ESP source](https://github.com/emard/LibXSVF-ESP):

# Programming ESP32

ESP32 WiFi module soldered on ULX3S is usually shipped
to end-users with WiFi Web-JTAG application loaded in ESP32.
User can overwrite ESP32 with any other sketch  like "blink"
and then ESP32 Web-JTAG interface will temporarily disappear.

Web-JTAG ESP32 application can be restored back to factory
default state using binaries and linux scripts
from [ulx3s-bin](https://github.com/emard/ulx3s-bin) or
by recompiling from [LibXSVF-ESP Source](https://github.com/emard/LibXSVF-ESP).

Load "passthru" bitstream to FPGA config flash, install
Arduino and its ESP32 support. In "tools" pull down menu, under ESP32 
select board "WEMOS LOLIN32" and normally program ULX3S onboard ESP32
from Arduino by clicking right arrow round button (->) to upload sketch.
Examples->Digital->Blink_without_delay any you should see blue LED D22
blinking.

This automagically works because "passthru" bitstream will
redirect USB-serial ESP32 programming traffic from PC thru FPGA to ESP32.

There might be strange issues on getting this to work on windows.
On linux usually only USB-serial port access permission is required.

Note boards PCB v3.1.x: if esptool.py can't program when passthru
bitstream is loaded, connect TMS and GND at JTAG header and try
programming then.

To avoid programming difficulties, ESP32 firmware should not
drive PIN 5 (wifi_gpio5, blue LED D22, TMS) as output first few
seconds after ESP32 boot. If PIN 5 is driven immediately at
boot, esptool.py can't program. Solution is to force PIN 5 low
at JTAG header by connecting TMS and GND (blue LED will turn ON)
and holding it at least until ESP32 programming starts.
It can be released when flash starts writing from 0x00010000.
Or simply when red LED D19 TX/RX blinks for few seconds.

# LCD/OLED Display

Solder 7-pin 2.54mm female header on ULX3S and obtain some
pin compatible display:

    1.3" 7-pin 240x240 Color ST7789 SPI LCD.
    (Best buy, cheap, very fast, good brightness).
    
    1.54" 8-pin 240x240 Color ST7789 SPI LCD.
    (Same as 1.3" but larger and costs more.
    Pin 8 (backlight) is default ON when not connected).
    
    0.95" 7-pin 96x64 Color SSD1331 SPI OLED.
    (Supported by "websvf". Expensive, very fast, full-featured, good brightness).

    1.54" 7-pin 128x128 Color SSD1351 SPI OLED.
    (Expensive, fast, low brightness).

    0.95" 7-pin 128x64 BW SSD1306 SPI OLED.
    (Expensive, no color).

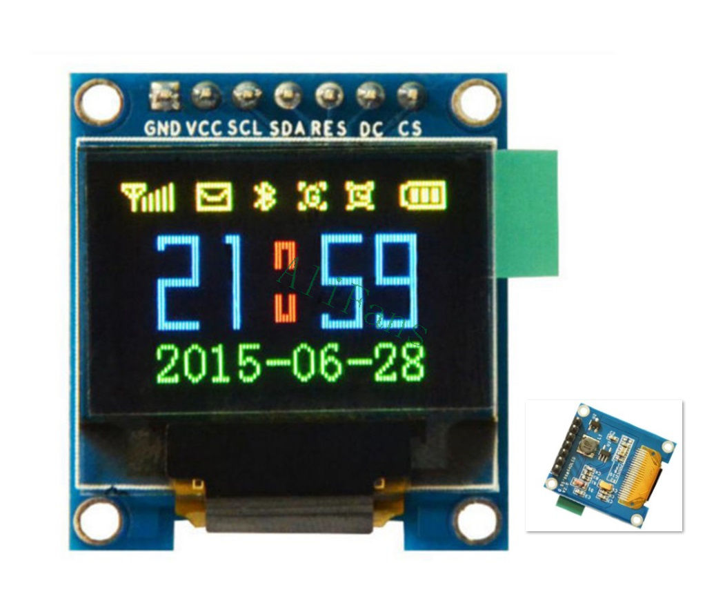
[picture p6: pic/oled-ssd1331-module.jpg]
OLED COLOR DISPLAY SSD1331


Pin names on OLED module should match those written on ULX3S silkscreen.
Cheapest from ebay or aliexpress are all good and work.
Display glass may be glued a bit off-angle from module to module,
that's kinda "normal" for 7$. It can display nice and readable high
contrast color picture :)

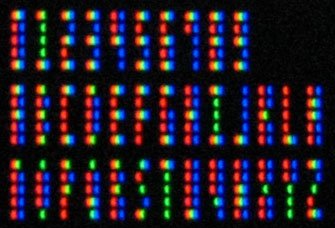
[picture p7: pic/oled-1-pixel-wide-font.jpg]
OLED 1-PIXEL FONT


# e-ink/e-paper Display

Those displays may keep picture without any power applied
and are ideal for ULX3S in low-power sleep and wake-on-RTC.

Currently e-ink/e-paper displays are availabe on ebay and others
with pinout that can be directly plugged to J1/J2 connector.
For OLED connector, read pinout carefully, VCC and GND should be
swapped!

e-ink 1.54" v2 BW 200x200 SPI with IL3829 driver chip:

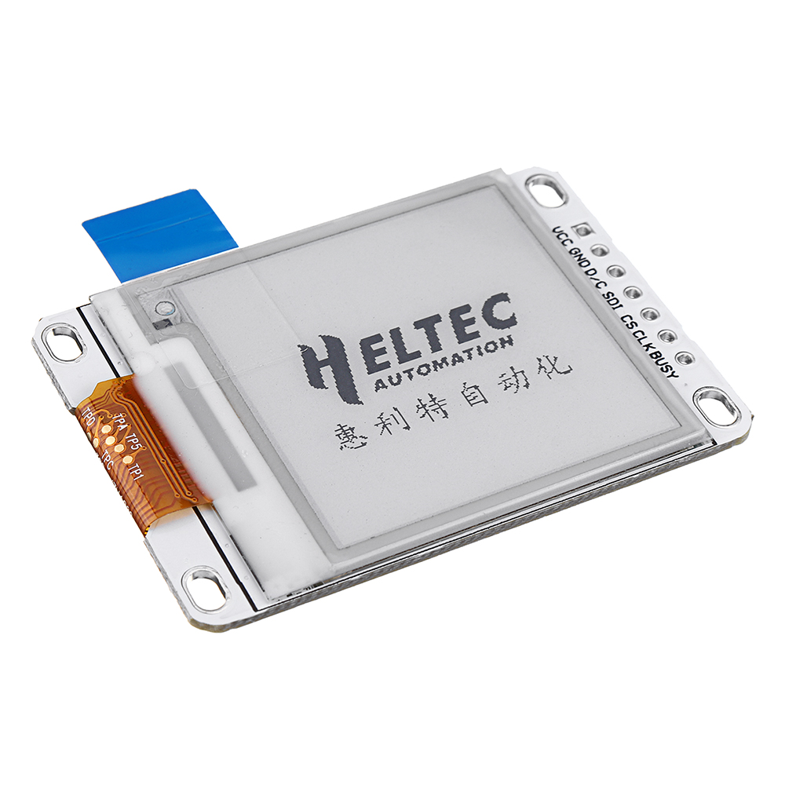
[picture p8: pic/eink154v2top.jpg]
eink154v2top

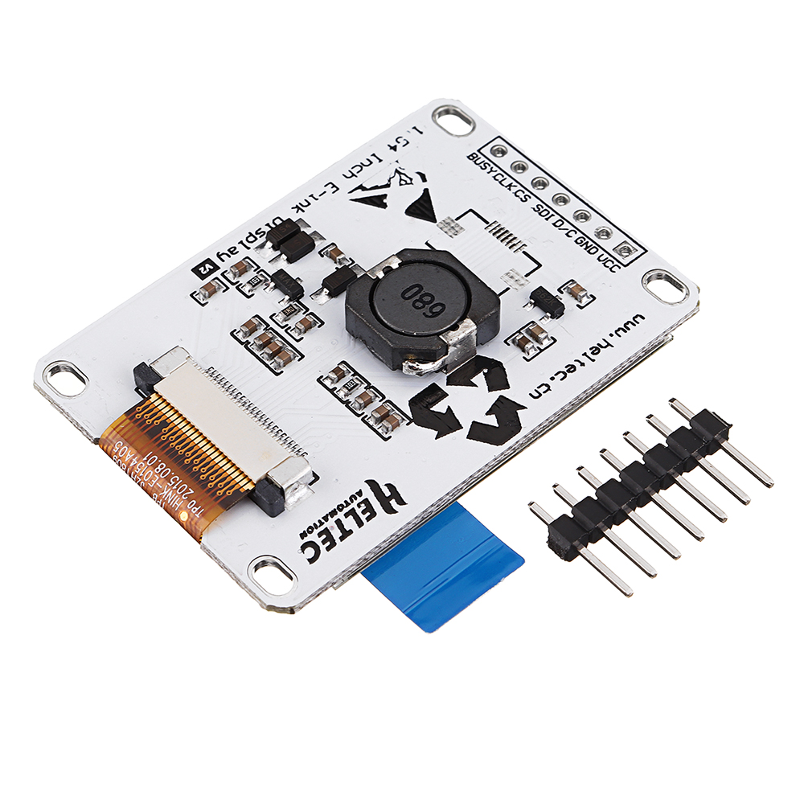
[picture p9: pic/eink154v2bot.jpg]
eink154v2bot


# US2 connector as OTG, PS/2 or sniffer

Here is list of some useful cables and adapters for US2 connector

For US2 to various things:

[micro-USB-male to USB-female aka OTG adapter](https://www.ebay.com/itm/Micro-USB-2-0-A-Female-to-B-Male-Converter-OTG-Adapter-Cable-for-Samsung-HTC-LG/311201513107)

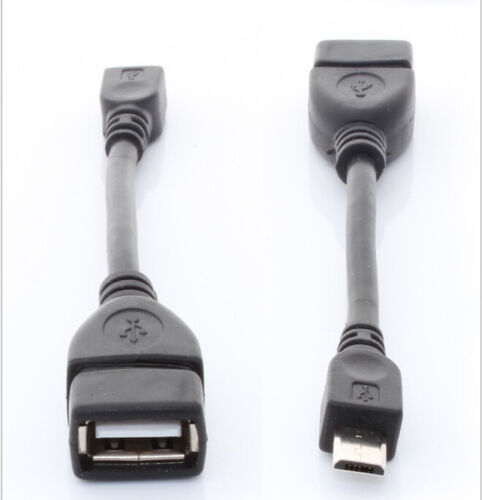
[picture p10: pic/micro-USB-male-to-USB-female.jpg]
micro-USB-male to USB-female


For PS/2 keyboard or mouse:

[USB-male to PS/2-female](https://www.ebay.com/itm/PS-2-Adapter-Female-To-USB-Male-Converter-Keyboard-Mouse-Adaptor-Connector-Mini-/303015055836)

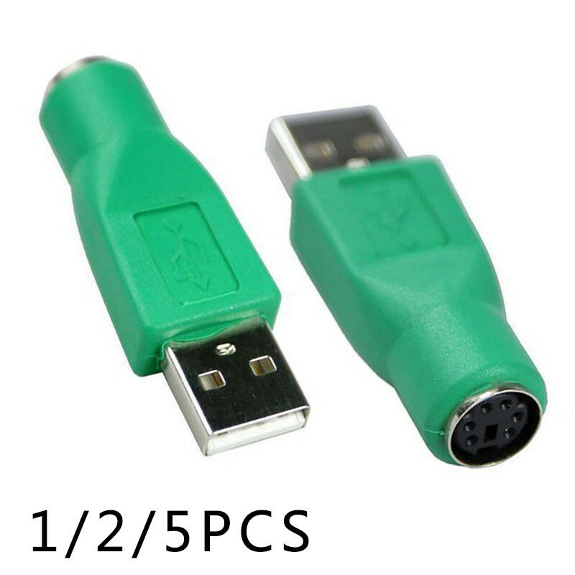
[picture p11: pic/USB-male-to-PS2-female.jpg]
USB-male to PS/2-female


For PS/2 keyboard, combo USB-PS/2 keyboard is recommended, some older
Logitech are known to work. Recently reported working is
[CiT KB2106C USB/PS2 Combo Keyboard](https://www.cclonline.com/product/76320/KB-2106C/Keyboards/CiT-KB-2106C-USB/PS2-Combo-Keyboard/KBD0426/)

For electrical USB sniffer you need this:

[USB-male to USB-male](https://www.ebay.com/itm/351868263369)

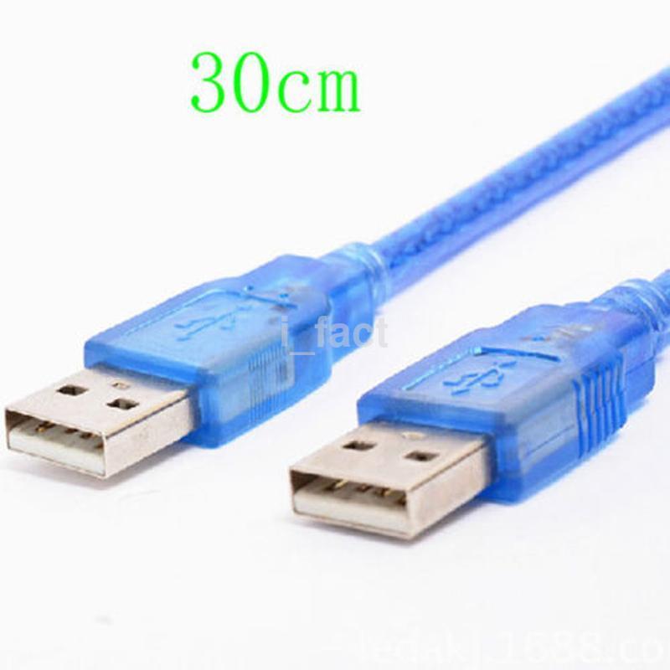
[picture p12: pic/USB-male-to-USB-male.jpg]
USB-male to USB-male


[1-RJ45-male to 3-RJ45-female](https://www.ebay.com/itm/RJ45-1-To-3-Ethernet-LAN-Network-Cable-Splitter-Extender-Adapter-Connector-KY/113393365472)

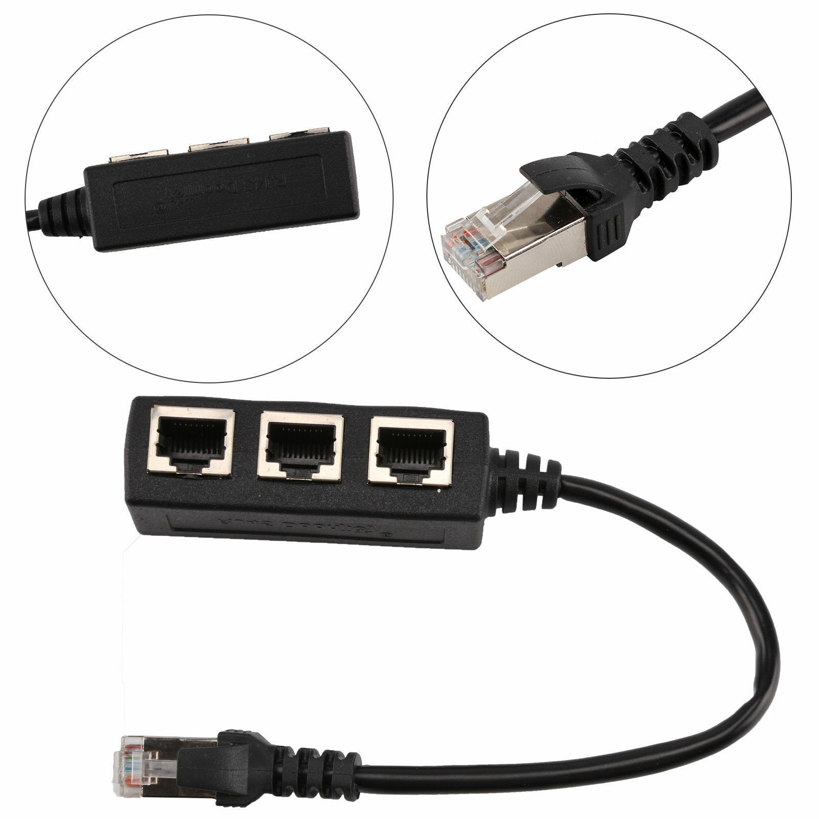
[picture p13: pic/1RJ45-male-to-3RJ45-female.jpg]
1-RJ45-male to 3-RJ45-female


[RJ45-male to USB-female](https://www.ebay.com/itm/2Pcs-Ethernet-RJ45-Male-to-USB-Female-Connector-Converter-Adapter-LAN-Network/391958541369)
you need 3 but it's double-packed, so buy 2, you get 4

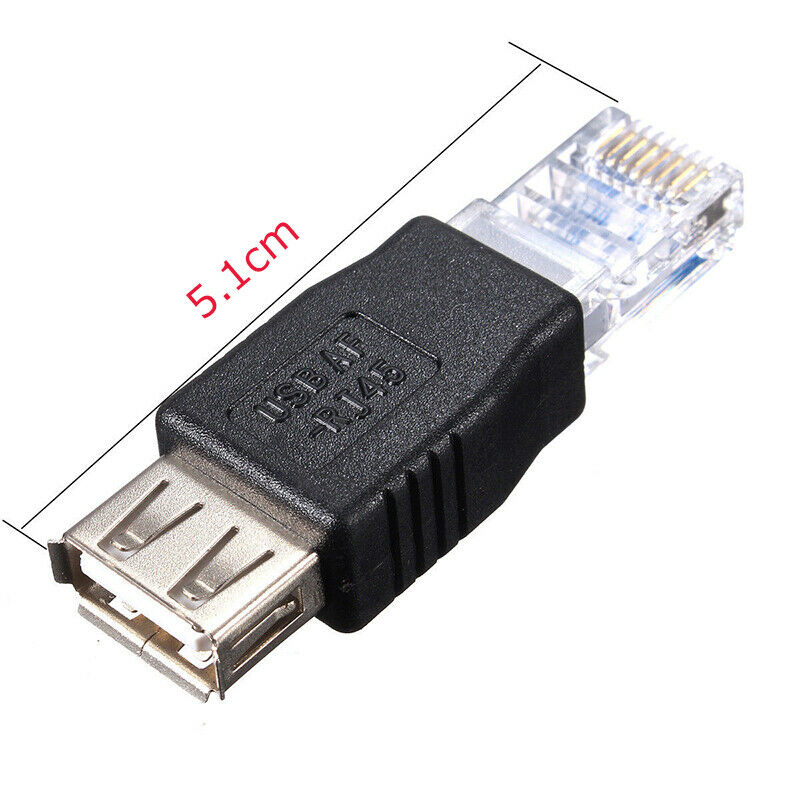
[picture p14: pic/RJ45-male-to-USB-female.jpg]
RJ45-male to USB-female


# ETHERNET RJ45

ULX3S doesn't have onboard RJ45 ethernet but on ebay
there are cheap 100-Mbit RMII-standard pin compatible ethernet modules
which can be directly plugged into ULX3S (pins GP,GN 9-13 VCC=3.3V).
Warning: LAN8720 module will be permanently damaged if powered at 5V instead of 3.3V.

[LAN8720 RMII RJ45 Ethernet
module](https://www.ebay.com/itm/163847001207?hash=item26260ad477:g:oX8AAOSwM0Rdb23Z)

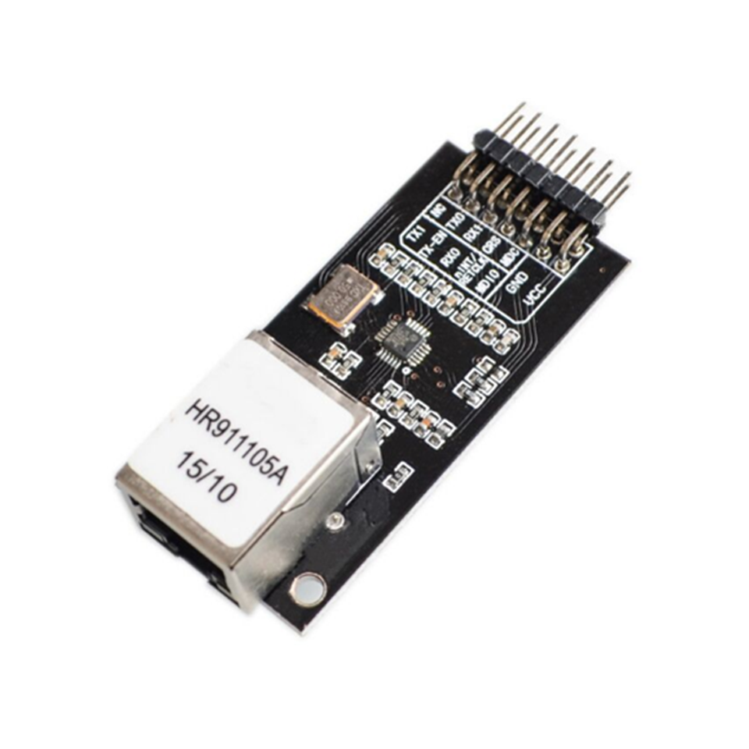
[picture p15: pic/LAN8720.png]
LAN8720 RMII RJ45 Ethernet module


# AUDIO Jack to Cinch Cable

ULX3S 3.5 mm audio jack is compatible with stereo earphones/headphones.
Output is loud enough, amplifier is not needed. It has 3-channel 4-bit
DAC with 75 ohm output impedance and 0-3.3V DC swing.

To use 3rd channel for SPDIF audio or compositie video together with
2-channel analog audio, use Apple/Nokia compatible 3-cinch cable.
It can be easily found on ebay, search for
"3.5mm 4 Pole Male Plug To 3 RCA (Red/Yellow/White) Female Jack Cable".

Compatible cable wiring is "OMTP" as descrbed in the
[TRRS standards](https://en.wikipedia.org/wiki/Phone_connector_(audio)#TRRS_standards)

WARNING: Sony compatible 3-cinch cables are NOT SUITABLE for ULX3S!
Sony cables are the most often found in consumer audio/video shops.
Visually they look identical, but the pinout is different.
Check the unknown cable pinout with instrument.

Correct pinout is this:

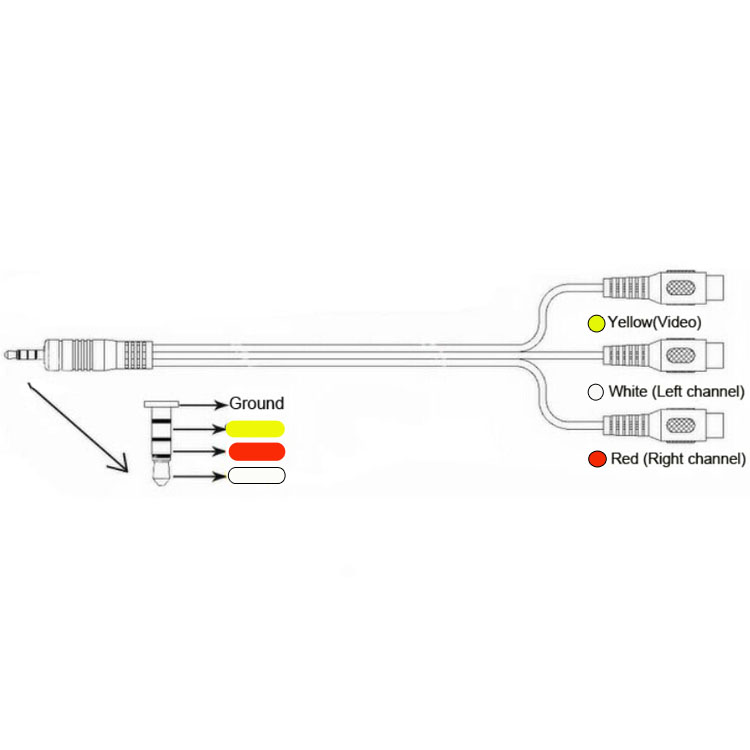
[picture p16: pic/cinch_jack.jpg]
AUDIO JACK TO CINCH


# i2s-Quality Audio Module

Onboard audio jack has cheap and educative 4-bit DAC
which is good for audible tones but may be noisy.
Better audio quality can be obtained from external
I2S module PCM5102 for clean stereo PCM 192kHz 16-bit sound.
Module also has amplifiers for headphones, it is loud enough.

On ebay it is sold for about 4$.

[PCM5102 I2S Interface DAC Decoder GY-PCM5102 I2S Player Module for Raspberry Pi](https://www.ebay.com/sch/i.html?_from=R40&_trksid=p2047675.m570.l1313&_nkw=PCM5102&_sacat=0)

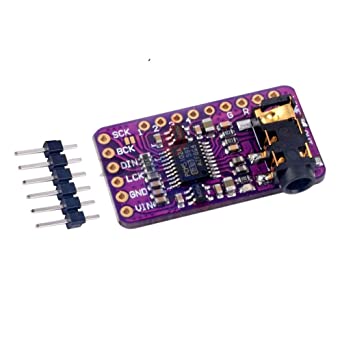
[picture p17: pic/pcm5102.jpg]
I2S AUDIO MODULE


# Fast ADC/DAC

Onboard ADC allows total bandwith of 1 MSa/s, shared for all channels used.
For faster ADC/DAC there are options to connect external boards:

Module AN108 32 MSa/s 8-bit input AD9280 and 125 MSa/s 8-bit output AD9708.
It is not directly pluggable, but
[gojimmypi made adapter](https://github.com/gojimmypi/ulx3s-adda/),
which can be ordered from oshpark:
[ULX3S FPGA to AD/DA Converter Adapter
Board](https://oshpark.com/profiles/gojimmypi).

Module AN926 12-bit 2-ch 50 MSa/s AD9226 is "almost" directly pluggable,
user has to re-crimp or modify few lines of a 40-pin flat cable and it
should fit.

AN108 8-bit AD/DA 32 MSa/s IN, 125 Msa/s OUT
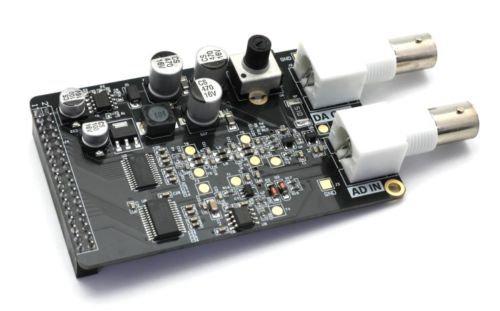
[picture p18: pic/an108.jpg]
AN108 8-bit AD/DA 32 MSa/s IN, 125 Msa/s OUT


AN926 12-bit 2-ch AD 50 MSa/s IN
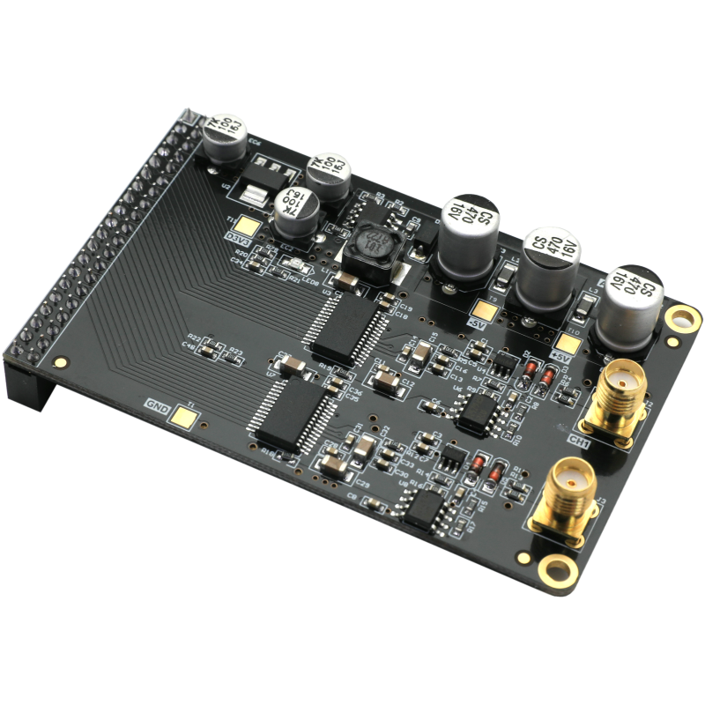
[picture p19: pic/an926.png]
AN926 12-bit 2-ch 50 MSA/s


# Plastic Box

In the [box](/box) directory is 3D model for the
box enclosure (recommended is [snapbox](/box/snapbox))
and display holders. Models are parametric and 3D printable,
written in [OpenSCAD](https://openscad.org/).
Enable one part (up/bottom/pin), render (press F6),
export as .stl file, slice one or more .stl files to
.gcode and print.

# Board differences

v1.7 prototype

The first prototype made. Has 45F and 32MB SDRAM.
To get ESP32 working it has to be manually wire patched.
Flash is connected as 1-bit SPI, US2 connector doesn't have
all lines needed to be both host and device. This board
doesn't have series C to GPDI connector which makes it
very sensitive to static discharge or bad GND connection.

Main reason for redesign was to get ESP32 working properly.
BTN UP, BTN RIGHT and some other pins have changed routes to
FPGA pins in later versions.

v2.0.x and v3.0.x

Very successful and widely produced boards. There are no
important differences between v2.0.x, v2.1.x and v3.0.x to the user.

Most differences are in thermal management for soldering and
reducing number of faulty produced boards. Significant problems
were at version v2.0.5 and earlier with BGA soldering and "tombstoning"
effect when resistors rise up due to unequal local temperature between
pads.

FLASH is connected as 4-bit QSPI, supports 1-bit SPI but user
must take care to hold unused lines at '1' (logic high level)
otherwise some ISSI FLASH chips will not work because of crosstalk.

BTNs are slightly different routed.

US2 connector now has 6 routes to FPGA, supports both device and host mode,
differential and single-ended connections, low-speed 1.5 Mbps
and high-speed 12Mbps.

GPDI has 220nF series capacitors for coupling.

Around v3.0.5 some unused FTDI LED line was connected to unused
pin of FPGA in schematics with idea to create fully connected secondary
openocd JTAG channel from FTDI to debug FPGA softcore RISC5 CPUs with linux
on litex and saxonsoc. Such FTDI JTAG is fully functional but very slow
and linux needs big data thruput so in practice external JTAG is used
there anyway.

Main reason for redesign was to allow placement of
ESP32-WROVER-E modules 4MB RAM/16MB FLASH.
Micropython is now used on ESP32 to control 
ULX3S boards. It is user-friendly but RAM hungry.

Second reason was some RF interference with ESP32.
When video signal 800x600 or 1024x768 is generated
and monitor connected to GPDI port, then ESP32 almost
completely looses WiFi signal. When GPDI is unplugged,
connection is restored.

SD card slot need footprint for compatibility
alternative with slide-in/out reliable but inxepensive
SD card slot which is on-stock available from common suppliers.

RTC clock runs 30 ppm too fast.

GPDI hotplug HPD doesn't work because of C coupling.

No SERDES.

v3.1.4

New prototype, currently tested.

Board accepts ESP32-WROOM and ESP32-WROVER, ESP32 JTAG glitch was
fixed by connecting JTAG to different ESP32 pins. ESP32 wiring
now should provide ESP32-RMII connectivity from WiFi to FPGA.

GPDI series C lowered from 220nF to 22nF to reduce interference. 
GPDI hotplug line now has R coupling and protection Zener
diode which should make hotplug line work.

Board accepts old and new SD card slots. Old non-hinged SD slots
with landing contacts were cheapest and I liked them most, but are
no longer available from western suppliers. They may be still available
directly from china with longer ordering times. Hinged SD card slots
are available from western suppliers, have landing contacts too and make
good connectivity but hinge is fragile and makes insertion procedure longer.
Now board supports quick slide-in/out SD card slots with wiping contacts,
similar as RPI, on-stock available from western suppliers. Contact is good
but as those are wiping contacts, friction forces will
slowly wear out contacts at each insertion. Luckily all SD
operations can be done remotely by ESP32 so number of insertions
is negligible.

7-pin OLED/LCD header is extended to 8-pin and shared with
3 SERDES input differential pairs (1xRXCLK, 2xRXDATA) coupled with
series C=22nF. Additional 2 SERDES pairs (1xRXDATA, 1xTXDATA)
are routed only to C=22nF for possible manual wire patching.

RTC load capacitors are increased from 3.3pF to 4.7pF in attempt
to reduce clock error below 20ppm.

Generally all should work as before except ESP32 pinout is now
different. wifi_gpio16 and wifi_gpio17 are gone because WROVER
needs them for internal RAM, but here are many new available, so
wifi_gpio26 and wifi_gpio27 can be used instead for example.

v3.1.6

New prototype, currently tested.

Small change in ESP32 routing, 
GPIO0 routed to FPGA clock capable pin,
EN and GPIO22 changed.

Board has minor problem ESP32 will not boot standalone,
bitstream must pull up or output high to GPIO0 and then
pulse EN for ESP32 to boot. "Official" patch is to solder
15k 0603 resistor at GPIO0 pin which is 3rd soldered pin,
near letter "R" of R33 label. With thin wire 0.1mm connect
other end of 15k resistor to 3.3V at other end of R33.

v3.1.7

Adds R56 resistor which should make ESP32 boot standalone,
without help of FPGA bitstream.

# Board Versions

This project is open source, freely downloadable so there can be
as many versions as here are git commits.

v3.0.3 is sold at
[skriptarnica](http://skriptarnica.hr/vijest.aspx?newsID=1466).

v3.0.8 has been sold at
[Mouser](https://hr.mouser.com/Search/Refine?Keyword=ulx3s)
before 2022

v3.1.7 will be sold at
[Mouser](https://hr.mouser.com/Search/Refine?Keyword=ulx3s)
from 2022

Other versions are either prototypes or independently produced.

Up to our knowledge those versions are currently circulating around.
All listed versions should work if all parts (notably BGA) are properly
soldered.

    PCB       assembly       quantity                constraints
    version   facility       produced   date         compatibility   note       SDRAM                 FLASH
    -------   ------------   --------   ----------   -------------   --------   ----------------      ------------
    v1.7      PCBWay         8          dec 2017     v17patch        prototype
    v1.7      lemilica.com   1          jan 2018     v17patch        handwork
    v1.8      PCBWay         10         may 2018     v18             prototype
    v2.0.3    q3k            1          aug 2018     v20             handwork   MT48LC16M16A2TG-6A    IS25LP128F-JBLE
    v2.1.2    INEM-KONČAR    35         sep 2018     v20             prototype  MT48LC16M16A2TG-6A    IS25LP128F-JBLE
    v3.0.3    INEM-KONČAR    220        oct 2018     v20             for sale   MT48LC16M16A2TG-6A    IS25LP032D-JNLE-TR
    v2.0.5    Marvin         1          nov 2018     v20             handwork   MT48LC16M16A2TG-6A    S25FL064L-ABMF
    v2.0.5    Markus         1          dec 2018     v20             handwork   MT48LC16M16A2TG-6A    S25FL064L-ABMF
    v3.0.3    INEM-KONČAR    35         jan 2019     v20             for sale   MT48LC16M16A2TG-6A    IS25LP128F-JBLE
    v2.0.5    Zvone          2          mar 2019     v20             handwork   MT48LC16M16A2TG-6A    S25FL064L-ABMF
    v3.0.6    Sam Littlewood 2          mar 2019     v20             handwork
    v3.0.7    Kalle          1          jul 2019     v20             handwork
    v3.0.7    Watterott      8          aug 2019     v20             for sale   AS4C32M16SB-7TCN      W25Q128JVSIQ
    v3.0.3    Anil Gurses    1          aug 2019     v20             handwork
    v3.0.8    Fork Sand      5          oct 2019     v20             prototype  MT48LC16M16A2TG-6A    IS25LP128F-JBLE
    v3.0.8    Lolsborn       1          oct 2019     v20             handwork
    v3.0.3    INEM-KONČAR    220        oct 2019     v20             for sale   M12L2561616A-6TG2T    W25Q128JVSIQ
    v3.0.7    Watterott      88         nov 2019     v20             for sale   AS4C32M16SB-7TCN      W25Q128JVSIQ
    v3.0.8    INEM-KONČAR    1000       jul 2020     v20             for sale   IS42S16160G-7TL       W25Q128JVSIQ
    v3.1.4    INTERGALAKTIK  1          nov 2020     v314            prototype  MT48LC16M16A2TG-6A    W25Q128JVSIQ
    v3.1.6    e-RADIONICA    16         may 2021     v316            prototype  IS42S16160G-7TL       W25Q128JVSIQ
    v3.1.7    e-RADIONICA    64         sep 2021     v316            prototype  IS42S16160G-7TL       IS25LP128F-BL3
    v3.1.7    D&M            8          dec 2021     v316            for sale   IS42S16160G-7TL       W25Q128JVSIQ
    v3.1.7    D&M            168        jan 2022     v316            for sale   IS42S16160G-7TL       W25Q128JVSIQ

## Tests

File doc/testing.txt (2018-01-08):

[x] i2c hdmi
[x] i2c RTC (first disable CLKOUT - it will enable INT1 wakeup)
    by default RTC does CLKOUT and constantly wakes up the board
[x] Shutdown in enumerated state
[x] Shutdown in non-enumerated state
[x] RTC wakeup
[x] USB wakeup
[x] power button wakeup
[x] config flash
[x] sdram memory test
[x] ADC
[x] OLED
[x] SDCARD behaviour with wifi
[ ] GPIO normal mode
[ ] GPIO differential mode
[x] AUDIO jack
[ ] USB2 with soft-usb core

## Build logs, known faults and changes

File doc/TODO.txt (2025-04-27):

# TODO

Here is checklist what was done or should be done in the next PCB release.

    [x] Silkscreen Double outline for BGA chip
    [x] Silkscreen do not write over the solder pads
    [x] Silkscreen JTAG signal names on 6-pin 2.54 mm header
    [x] Silkscreen remove OLED outline
    [x] Solder stop mask must go inbetween all SMD chip pads
    [x] External differential clock input at J1_33 +/-
    [x] physically sprinkle VCC blocator capacitors under BGA
    [x] Dedicated antenna pin
    [x] onboard 433 antenna
    [x] 433 remove GND and silkscreen test point
    [x] Resistors for LEDs
    [x] Move USB LEDs from bottom to top side
    [x] Improve SDRAM routing - use VIAs for closest pins
    [x] Increase thickness of power lines (5V, 3.3V, 2.5V)
    [x] Compile a f32c bitstream using the schematics
    [x] Compile differential GPDI output
    [x] Connect more lines from ESP-32 to FPGA
    [x] Connect FPGA USB D+/D- with 1.5k pullup in USB 1.1 (full speed) mode
    [x] FPGA USB add 27 ohm + 3.6 V zener
    [x] Symmetrically place USB connectors left-right 
    [x] External JTAG header
    [x] Move JTAG 2 mm left
    [x] Move WiFi Disable jumper closer to the BTN1 (angled header)
    [x] Sprinkle 2.2uF capacitors on power lines
    [x] Spice simulation of power-up/shutdown network
    [x] 27ohm D+/D- to FT231XS
    [x] DIP switch (4 switches)
    [x] MAX11123 ADC SPI
    [x] I2C for RTC
    [x] main usb connector on top side 
    [x] space screw to other parts
    [x] move battery away from screw hole
    [x] top layer GND fill
    [x] R25 move away from oled screw hole
    [x] DIP switch to the right near RAM
    [x] Move GPDI a bit closer to OLED
    [x] 32768Hz oscillator footprint
    [x] SD card footprint SCHD3A0100
    [x] center the SD footprint for T&R
    [x] SD connect GND (thin pins)
    [x] move USB 0.5-1mm more out
    [x] DIP SW footprint correct
    [x] AUDIO jack footprint fits
    [x] AUDIO jack pin 4 (ring2) connected to 4-bit DAC
    [x] BTN footprint too small
    [x] SMPS jumpers default OFF for prototype testing
    [x] FPGA DONE to ESP-32
    [x] Diodes manual soldering
    [x] R56: FT231X rev A,B,C TXDEN to GND
        workaround from TN140_FT231X Errata
    [x] PCB for LFE5UM ready (some GND will change to
        VCC for Serdes power supply, see LFE5U->LFE5UM
        migration docs)
    [x] Check GND/VCC for 45 and 85 packages,
        for example pin T11 is NC on 25U, GND on 85U and VCC ond 85UM
    [x] Reconnect WIFI_OFF so that jumper has priority
    [x] 25MHz oscillator: needs clearance from LEDs, move under USB1
    [x] connect SHUTDOWN to FPGA
    [x] ESP-32: won't boot when SD connected. Don't solder it at PCB v1.7
        It is routed differently in newer release
        Arduino->Examples->ESP32->SD_MMC_Test
        https://github.com/espressif/esp-idf/blob/master/examples/storage/sd_card/README.md
        moved blue LED from GPIO2 to GPIO5
    [x] I2C resistors increased 470->2.2k
    [x] GPDI AC-coupling 100nF to each differential line.
    [x] reliable shutdown (D11=RED LED, R4=4.7k)
    [x] SDRAM raster back to 0.8 mm
    [x] connect SPI Flash Quad Mode (QSPI)
    [x] allow powering the board without powering FTDI chip
    [x] micro USB extended pads for Handsoldering (already were extended)
    [x] move 25MHz oscillator away from USB connector for handsoldering
    [x] schematics gpio J..+- pins renamed to gp/gn for easier readability
    [ ] route 16-channel ADC
    [x] move 8 LEDs a bit down and right
    [x] let SD_CLK go to FPGA clock capable pin: swap SD_CLK and SD_D2 pins 
    [x] additional 2 differential lines for US2
    [x] additional US2 pins for pullup 1.5k
    [x] additional US2 pins for pull up-down 15k
    [x] unified US2 pullup/down: resistor-diode nework for pullup 1.5k and pulldown 15k
    [x] clear silkscreen mess with Cx under FPGA
    [x] power decoupling capacitors for ESP32 and OLED
    [x] Connect switching power supply jumpers
    [x] every 1-2 seconds there are clicks at analog audio output, fixed in v2.1.2
    [x] 3.6V zener diodes must be on FPGA side
    [x] can esp32 second tx/rx port make serial communication with FPGA
    [x] Jumper to switch 2.5V/3.3V for left IO banks
    [x] move usb pull from gpio bank0 to gpdi bank1
    [x] isolate each PMOD group to each io bank
    [ ] move GP7,GP8 from gpio bank0 to gpio bank7
    [x] route selected voltage to VCCio0/7
    [x] route selected voltage to J1 PMOD instead of 3.3V fixed
    [x] more bank0,1,7 decoupling capacitors
    [x] Move Jumper 2.5V/3.3V deeper inside PCB (angled header)
    [x] 0R resistor placeholders to hardwire 2.5V/3.3V instead of the jumper
    [x] Selected 2.5/3.3V to J1 header (instead fixed 3.3V)
    [x] RTC battery capacitor
    [x] battery + pad clearance
    [x] PCB v1.8.1 redesigned to fit digital video 649-10029449-111RLF (the cheapest)
    [x] use cheaper diodes 1N914
    [x] fix copper layer after using non-handsoldering resistor footprints
    [x] DIP switch must be pulled up at 2.5/3.3V or 2.5V line, not 3.3V
    [x] RTC time loss at power down fixed with 1k+22uF - see page 54 of datasheet
    [x] Rotate SD card 180° for easier front loading
    [x] Move C1, C21, C50 away from J1, J2 connectors (make space for IDC header)
    [x] Smaller USB pads
    [x] Smaller pads (not for handsoldering)
    [x] Revert USB to datasheet default
    [x] ADC text smaller font, move above ADC chip
    [x] ULX3S/version left of ADC chip   
    [x] (inem) KONCAR logo on bottom side
    [x] BTN font size like TCK
    [x] Combo pads for flash 150/208 mil
    [x] SDRAM text smaller font size
    [x] SW1 increase size, to more visible place
    [x] GPIO numbering on bottom side, all pins in smaller font
    [x] enlarge FER logo
    [x] Descriptive audio jack schematic symbol
    [x] USB ID pin to RTC WAKEUPn
    [x] Move 25MHz clock down closer to LEDs
    [x] i2c chip U11 VCC1=2.5V EN=3.3V for low power sleep
    [x] Noise filter for ADC (LC)
    [x] Non-GND yellow layer clearance from board's edge
    [x] VIAs thru-GND
    [x] no paste on SW1 pads 
    [x] diode for BTN0 to PROGRAMN
    [x] capacitor for BTN0 debounce
    [x] BGA pad=0.4mm mask=0.5mm paste=0.35mm
    [x] VIA align to 0.4mm raster
    [x] min VIA enlarge 0.4 mm -> 0.419 mm
    [x] USB: copper fill keepout
    [x] ADC: footprint according to MAX1112x land pattern 90-0023
    [x] fix tombstoning see https://www.tempoautomation.com/blog/surface-mount-tombstone-experiment/
    [x] Avoid VIAs on the PADs
    [x] aligment marks for BGA footprint using exposed gold plated copper
    [ ] Order ADCs in reel (not bulk, not tube).
    [x] check increased distance of 2 pad rows of SDRAM
    [x] check decreased distance of 2 pad rows of FT231X
    [x] route FTDI_nRXLED to FPGA
    [ ] resistor in series with + battery
    [ ] GPDI clock to clock capable pins, swap with USB pullup
    [x] GPDI eth->hpd/cec with resistors
    [ ] more routing to true differential pins (avoid bank 0 and 1)
    [ ] FT2232H port B MPSSE JTAG, powered from 3.3V onboard.
        SOT-23-6 SPI EEPROM like 24CW1280T-I/OT placeholder
        by default SPI also routed to FPGA for emulation
    [ ] Pull-up <10k for clk_oe
    [x] 8-pin LCD header
    [x] prototype test: connect blue LED+R on TMS line (ESP32-FPGA-FT231x)
    [x] ESP32 enlarge solder paste openings in all 3 directions
        openings should extent longer than copper area for sufficient
        solder to be pulled under the pad
    [x] ESP32 wifi_gpio26,27,35 directly to FPGA
    [ ] ESP32 wifi_gpio25 3.3V io connected 3.3V/2.5V, OK?
    [ ] ESP32 LED standalone?
    [ ] ESP32 avoid sharing with true differential lines
    [x] GPDI capacitors sorted
    [x] BGA J2 weak GND
    [x] SD new footprints
    [ ] why i2c pullup to 2.5V instead of 3.3V?
    [x] FT231 too close to LCD holes
    [x] OLED 3.3V/GND internal copper fill standoff (be able to cut for serdes)
    [x] return of PCB logos
    [x] stencil opening with briges and island for THT holes of GPDI
    [ ] ESP32 wroom vias, remove from area where not connected pads are
    [ ] U11 silkscreen move bottom right, write C11 there
    [x] swap WIFI_EN with WIFI_GPIO22, for GPIO22 to connect to clock capable pin
    [x] WIFI_GPIO0 to FPGA clock capable pin, swap WIFI_GPIO22 with WIFI_GPIO0

Digi-Key Part Number 	WM12834TR-ND 	
Manufacturer 	Molex 	
Manufacturer Part Number 	5031821852 	
Description 	MICRO SD NORMAL ULTRALOWPRO8CKTE 	
Manufacturer Standard Lead Time 	12 Weeks 	
Detailed Description 	10 (8 + 2) Position Card Connector microSD™ Surface Mount, Right Angle Gold 

Digi-Key Part Number 	WM9750TR-ND 	
Manufacturer 	Molex 	
Manufacturer Part Number 	5031821853 	
Description 	CONN MICRO SD CARD PUSH-PUSH R/A 	
Detailed Description 	10 (8 + 2) Position Card Connector Secure Digital - microSD™ Surface Mount, Right Angle Gold 

Digi-Key Part Number 	2073-MEM2075-00-140-01-ACT-ND 	
Manufacturer 	GCT 	
Manufacturer Part Number 	MEM2075-00-140-01-A 	
Description 	MICRO SD PUSH-PUSH, SMT, 1.40MM 	
Manufacturer Standard Lead Time 	6 Weeks 	
Detailed Description 	9 (8 + 1) Position Card Connector microSD™ Surface Mount, Right Angle Gold 

ESP32S3

    [ ] reconnect esp32 for s3
        connection for ESP32 classic (old)
        GPIO4    SD_D1
        GPIO12   SD_D2
        GPIO14   SD_CLK
        GPIO21   WIFI_GPIO21
        GPIO22   WIFI_GPIO22

        connections for ESP32S3 (new)
        ESP32    ESP32S3
        GPIO0    GPIO0  - PWRBTn (D28 anode)
        GPIO12   GPIO19 - US1 D- (USB esp32s3, was esp32 SD_D2)
        GPIO14   GPIO20 - US1 D+ (USB esp32s3, was esp32 SD_CLK)
        GPIO21   GPIO42 - SD_CLK (was esp32 WIFI_GPIO21)
        GPIO22   GPIO2  - SD_D2  (was esp32 WIFI_GPIO22)
        GPIO19   GPIO40 - SD_D1  (was esp32 SD_D1)
        GPIO4    GPIO35 - NC (cutoff, Octal PSRAM caution)

        ESP32S3 bottom pins: 
        connect to RS232 signaling and FPGA
        GPIO 3,9-14,21,47,48

        drawbacks after this reconnection when ESP32 classic
        is mounted
    [ ] SDMMC mode unavailable on classic ESP32
    [ ] RMII unavailable on classic ESP32
    [ ] ESP32S3 doesn't have bluetooth classic, only BLE
    [ ] multiboot esp32 switching between micropython and esp32s3-jtag

pinout for esp32s3-jtag (arduino sketch)

#define PIN_TCK  39
#define PIN_TMS  38
#define PIN_TDI  1
#define PIN_TDO  6
#define PIN_SRST 41

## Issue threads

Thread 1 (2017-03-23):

Maybe placeholders for two cameras if we have spare pins?

goran-mahovlic, 2017-03-23:
For experiments with computer vision ...
http://www.voti.nl/docs/OV7670.pdf
http://www.electrodragon.com/w/OV7670_Module

emard, 2017-03-23:
Pin count will be tight as this BGA-381 has many pins used as GND and VCC
So some pins might be shared with something else

Let's list some more wishes for placeholders
IR camera
SPI OLED display
LORA module
RTC

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

emard, 2017-11-13:
SPI OLED display, RTC and ESP-32 made it.
IR camera and LORA haven't.
Useful pin count is low, though there are still some free pins
in the inner circle of BGA but most of them are unrouteable
using 5/5 mil process. Going to 4/4 mils PCB will be too expensive.

Closed 2017-11-13.

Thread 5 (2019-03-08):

Some questions about using an external oscillator and pins on the ULX3S

nsajko, 2019-03-08:
Greetings,

I was introduced to ulx3s (I have the ECP5  LFE5U-25F-6BG381C FPGA and ULX3S v3.0.3) as part of the FER "Digital Logic" course (where we used it with VHDL) and now I am approaching it again as a hobbyist with the aim of making a High Speed USB (over US2) microphone array. Please bear with my ignorance as this is my first electronics project.

While preparing for this project I realized that it would maybe be necessary to have a more stable and precise oscillator than the 25 MHz one included on ulx3s, so I have some related questions:

* This 250 MHz LVDS oscillator [0] looks OK to me as a clock source. Is there perhaps a reason that trying to use it with ULX3S and my ECP5 instead of the 25 MHz oscillator on the ULX3S would be a bad idea?

* Is there a reason besides cost-cutting that ULX3S does not come with a better oscillator?

* I do not know how LVDS works, but that does not matter as the FPGA takes care of LVDS after I connect it with the "test" circuit suggested in the oscillator datasheets, only presenting digital clock signals to VHDL code? At least that is how I would prefer the situation to be!

* Am I correct in thinking that to use the LVDS oscillator with the ECP5, it is needed to connect its OUT pad/pin terminal to the J1 GP12 connection (marked with "+" on the ULX3S PCB), which would be accessible through VHDL with the gp(12) signal, assuming I use your LPF? Does the same hold for OUT- on the oscillator and J1 GN12 on the ULX3S PCB and gn(12) in VHDL, and is gn(12) supposed to always be the logical compement of gp(12) in such a case?

* Do I set the IO_TYPE for the gp[12] and gn[12] to **LVDS25** in the IOBUF PORT command/statement in the LPF file?

* Can somebody perhaps explain the purpose of the "N/C" pin terminal on the linked oscillator? I think it is supposed to always be left unconnected electrically??

* Can the Ground pin terminal be connected to something on the ULX3S? Likewise, how to draw power from the ULX3S to power the oscillator and other electronics necessary for my project? (I will probably use some kind of linear voltage regulator or voltage reference to get a more stable voltage source than the switching regulators on ULX3S can provide.) I would very much appreciate a photo of the v3.0.3 PCB with the necessary pins circled.

* Related to the previous question, I think the square-looking connections (there are 6 pairs of them on the ULX3S PCB) are ground, can I connect the oscillator ground to one of them? Are they all equivalent? On another note, what are the 4 wide circular connections with big holes through them on the ULX3S PCB?

* I am not sure how exactly to set up the LVDS resistors in the FPGA, or whether I need them.

* Did anybody ever need a heatsink for the ECP5 in their projects? Maybe I will need one ...

[0] https://www.arrow.com/en/products/dsc1103ai5-250.0000/microchip-technology

emard, 2019-03-08:
HI

Too many questions at once, I'll try to summarize and provide initial "mixed"
answer and then.

If you need to connect external differential clock source, currently
only option is GP,N 12 at external pins for PCB v3.0.3.
This is the only true Differential Clock INPUT capable pin pair.
For clock output, you can use several other pin pairs though therefore
you can route output the clock to other boards if you need to synchronize them.

You can power this LVDS oscillator directly from ULX3S it has 1A available
for powering external circuits.

Usually 3.3V powered bank can also accept 2.5V differential levels as input.
ULX3S also has jumper to completely switch GP,N 0-13 pins to 2.5V level if
you really need so. In this case LEDs will also become dimmer.

you don't need to worry much about setting of internal differential
resistor terminations,
usually any settings will work, but there are also Lattice Techincal
Notes describing
setting it in detail if you really want to be 100% electrical compliant

Squared PCB pin pads are GND, they are also labeled with "T" shaped
symbol, you have
multiple choices at each header, any will work. Headers have also 3.3V
pads "+" marked
(or they can become 2.5V, selected by the jumper between audio jack
and video connector)

at least 1A  is available to draw from the board at "+" or VCC marked pads
near GND pads. Near GP,N 27 is also +5V source directly from USB connector.

Switching regulators are noisy but for LVDS oscillator it should be no problem
as it probably has its own independent internal source.  Of course you are free
to add linear regulator if you need it but I don't think you will get
clock stability
from this.

For most stable clock source I would recommend atom clock or GPS disciplined
frequency source.

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

emard, 2019-03-08:
VCC +3.3V and GND are all equivalent and wired together.

ECP5 is relatively low power FPGA it would heat to about 50°C
when max loaded, so heatsink is not needed, save it for Artix-7

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

Closed 2019-07-15.

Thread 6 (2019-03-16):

constraint file pin numbering comments for gp[]

gojimmypi, 2019-03-16:
Regarding the comments for the gp pins:

I'm wondering if perhaps there's a mistake in the numbering in the comments, for example, [in the constraint file](https://github.com/emard/ulx3s/blob/master/doc/constraints/ulx3s_v20.lpf#L389):

```
LOCATE COMP "gp[14]" SITE "U18"; # J2_5+  GP14 DIFF ADC1
LOCATE COMP "gn[14]" SITE "U17"; # J2_5-  GN14 DIFF ADC0
```

specifically, I would have thought that  `J2_5+` and `J2_5-` should instead be labeled `J2_14+` and `J2_14-` (the differential numbering in the middle of the connector; J2_5 appears to be the J2 connector pin number for GN14 = U17)

or perhaps the comments should be `J2_5+` and `J2_6-` if using connector pin numbers (then what does the `14` in the middle represent?)

from the schematic:
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

If not, then what exactly does the `5` mean in  `J2_5+` and `J2_5-` ?

emard, 2019-03-16:
HI

this was remains of my pin numbering required for kicad
to "understand" differential so my "logic" was to use odd
connector pins like j1_5 for the pair j1_5+ j1_5-

problem is with kicad, it would not "understand" that
j1_5+ j1_6- belong to the same differential pair because
in kicad, differential pins must be named the same except
being different by trailing - or +, then kicad autodetects this
as "pair".

But anyway, just ignore this J1_x+ pinning, use GP,N which is more logical

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

gojimmypi, 2019-03-16:
hm. yes, I see. I think I'll add some notes for clarification. PR coming soon.

but on this topic, I'm wondering if perhaps the `- +` label on the PCB for J2 might be reversed?

Note from the pic above, that differential pair 14 is near the end of the connector closest to Pin 1. As the 14 is near the bottom of J2, I assume this means the physical board numbering is reverse of that on the schematic, right? (this would make sense, since it is rotated 180 degrees as compared to J1.

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

However, if indeed Pin 1 of J2 is at the bottom of the PC board near the `3.3+`,  that would make pin one, and all the odd numbers of J2, the negative side of the differential, right?

Note the tiny `- +` printed on the board between the `14` and `15` of J2.

For clarity, here's J2 schematic upside down, but oriented the same as viewing the PC board with the USB and DVI connectors at the top:

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

The negative side of the differentials should be to the right, correct? (odd J2 pin numbers on the bottom of the connector as view in the pic)

emard, 2019-03-17:
Pin 1 side left/right will be switched depending if connector
soldered is MALE or FEMALE board accepts both so some user
can solder MALE and find pinout OK, some user can solder FEMALE
and found pinout mirrored, or vice versa.

silkscreen markings on PCB should be self explainatory.
Outside pin row is differential +, inside pin row is differential -

Schematics symbol doesn't exactly map to physical appearance
of actual connector pins. I should have them mirrored/rotated probably
:)

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

gojimmypi, 2019-03-17:
yes, I did find that the _silkscreen on the board **is** correct_ - but the schematic is not? It does appear all of the _**even**_ numbers are G**N**xx; (as indicated by the `- +` on the J2 silkscreen) and the **_odd_** pin numbers, closest to the edge of the board are G**P**xx (of `J2`, I did not check `J1`).

For me, this became most evident when my AD/DA was not doing any conversions. I found the CLK on pin 29 of my board, needed to be connected to [GN14 on pin 6](https://github.com/gojimmypi/ulx3s-adda/blob/development/ulx3s_v20.lpf#L492), even though pin 6 (on the inverted J2 image, above) is labeled as G**P**14.

It is certainly good news that the silkscreen is correct. Unfortunately I was working from the schematic for quite some time before I realized that.

I've certainly had my share of _where is pin 1_ issues over the years... ;)  however that was usually with the cable. Regardless of male or female connector, pin one on the PC board remains the same, no? I do believe all the P/N notations on the schematic are reversed - and it would be really great to also invert the connector on the schematic to reflect the inverted orientation on the PC board, do you agree?

As further evidence, check out this view of the KiCad, J2 from above - viewing front of board:

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

And here it is rotated 180 degrees:

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

Note this view is from the top of the board. The only way that pin 1 would be on the left when looking from above, is if in fact the connector was on the back of the board. Do you agree? (see also [this pic](https://en.wikipedia.org/wiki/Pin_header#/media/File:Stiftwanne2x13v2.jpg) on wikipedia)

Also: Perhaps on the next version of silkscreen, you could add something to make pin 1 abundantly obvious?

If you agree with all this, I'd be happy to implement and submit a PR :)

emard, 2019-03-18:
It is possible that I made a male/female mismatch of schematic
symbol for header and the footprint of the header.
Kicad allows to mix everything and supposes the user knows what to do.

My personal preference is that pin numbering is for the straight male pins.
Then pin 1 of the cable (suppose you use IDE/CDROM 40pin cable) will
match pin 1 at the board markings

WHen using 90° female angled connectors, then usually nobody has cable
with male pins that can plug in female headers. It is
supposed to plug PMOD male connectors which have completely
unexpected pin numbering you don't want to know...

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

emard, 2019-03-18:
I'm looking again at the schematics -> I'd say pins on both
schematics and pcb footprint are consistenly numbered for
female 90° angled connectors.

If you soldered straight male pin header, even and odd numbering
will swap sides.

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

gojimmypi, 2019-03-18:
Well, I don't mean to be so persistent that I am annoying - but respectfully, I disagree. :) I'm also certainly willing to be wrong.

For one, I do not believe that changing between male and female headers changes the numbering scheme on the board. I think the reversal you are thinking of, is looking at the cable connector, or the device connector.

First, do we agree the "Front" of the ULX3S is as labeled in KiCad - the side with the display and connectors?

Let's take a look at another example, the J8 header mounted on the front of the board for the Raspbettery Pi. See the [Schematic](https://github.com/raspberrypi/documentation/blob/master/hardware/raspberrypi/schematics/rpi_SCH_3bplus_1p0_reduced.pdf):

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

Pin 1 is in the same position on the physical board of the RPi, (to the left when looking down at the connector on the front of the board) regardless of male or female connector that may be soldered on, as well as regardless of straight or angled. Agreed?

And [here's](https://github.com/raspberrypi/documentation/blob/master/usage/gpio/README.md) where they document Pin 1 as the 3v3 for the header, which would be Pin 1 for a male or female connector when the header is mounted on top of the board:

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

For reference, [here's a Molex angled connector from Mouser](https://www.mouser.com/datasheet/2/276/0877604016_PCB_HEADERS-176440.pdf):

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
emard, 2019-03-18:
this is my "conversion scheme" for J+-
J2_5-  -> J2_5
J2_5+ -> J2_6

The silkcreen markings +/- should be consistent with digital
differential +/- for FPGA, but are OPPOSITE for differential mode
of ADC

if you use ADC in differential mode, it is of course connected
shared on pins GP/N14-17. What is + for digital FPGA pins is -
for ADC in differential mode and vice versa

However (I now not sure but I _think_ that) binary numbers obtained
from ADC are also reversed. Connecting + voltage to ADC+ and - voltage
to ADC- will obtain lower hex values, and reverse the higher values.
So now wonder have I reversed reversed - + and got correct HEX? :)?

You know what's difference between good and bad scientist?
Good scientist makes wrong sign even number of times :)

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

gojimmypi, 2019-03-18:
Well, I certainly appreciate your patience here... Clearly I've not been very effective in communicating the issue. ;)

First: Ironically, despite the GP/N14 differential pins in question being _ADC pins_, I am not actually _using_ them for that. My AD/DA converter is _external_, connected to the ULX3S as shown [here](https://github.com/gojimmypi/ulx3s-adda/blob/development/doc/ribbon-cable-ADDA-bottom.PNG) and in operation [here](https://twitter.com/gojimmypi/status/1107054057125040128) - having nothing to do with the fact that those ULX3S pins are also differential A/D pins (I was referring to the general topic of differential P/N for all naming of the pins).

The issue I am trying to convey is the schematic has Pin 1 reversed, shown on the left, and the PC Board has Pin 1 on the right:

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

So for instance when looking at the schematic for GN14, I connected my wire here:

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

Which I thought was this position on the header, Pin 5:

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

But the PC Board (Female connector as you noted) has that numbered as Pin 6 for both J1:

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

and J2:

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

Pin 6 is actually G**P**14, correctly noted on schematic, but illustrated on the opposite side when actually viewing the connector.

emard, 2019-03-18:
Your image snapshots are referring to old schematics

New schematics have mirrored/rotated the connectors
that in my kicad and PDF now look the same,
are numbered the same and are rotated to visually
match the same appearance as physical pins when
viewed from above of the PCB (buttons side up).

I hope now this is easier to read. Tell me if you still can
find any difference of mis-leading facts?

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

gojimmypi, 2019-03-18:
old? _OLD_!? LOL. You mean "old" as in the [version prior](https://github.com/emard/ulx3s/commit/2dba7d3caa8b1b38d21afe40399291c0e050c252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) to the one you [edited just yesterday](https://github.com/emard/ulx3s/commit/a639b5e2f4d1e8efecb6504374c8083047c69553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)?? ;)

well then: yes! that's great! :) Just like that. (and yes, I feel rather silly for ranting on above, but in the end, it appears you agreed with me that the _old_ schematic was misleading).

I did see your changes yesterday regarding default page orientation and text searching - both excellent updates - but I had not noticed the connector changes!

This is great, much more helpful:

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

Thank you for making those changes. :)

emard, 2019-03-18:
Yes it's OLD there were few updates today :)
Pin numbering remains but it's now rotated and mirrored
for a more intuitive reference to the PCB.

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

gojimmypi, 2019-03-18:
yes, indeed. :)

Regarding this comment, from above:
> this was remains of my pin numbering required for kicad to "understand" differential so my "logic" was to use odd connector pins like j1_5 for the pair j1_5+ j1_5- problem is with kicad, it would not "understand" that j1_5+ j1_6- belong to the same differential pair because in kicad, differential pins must be named the same except being different by trailing - or +, then kicad autodetects this as "pair". But anyway, just ignore this J1_x+ pinning, use GP,N which is more logical

I wonder if perhaps since this was _your "logic"_ - perhaps the notation should be removed from the constraint file?  (using the rationale that if it was confusing to me, it may be to others as well?) Or clarified: `J1_5_6+` and `J1_5_6-` - particularly now that the note had been added to the schematic about the change in numbering based on a male or female header.

I do agree `GP,N` is more logical.

btw - you may with to add some text to the schematic that states _why_ the default as shown is a female connector, specifically to accommodate  PMOD connectors without an adapter.

emard, 2019-03-19:
HI

I prefer to keep Jm_n+- notation for now, in the constraints
file before GP/N I have added comments with examples
that describe how to convert J1_5+ to J1_5 or J1_6, depeding
on connector type.

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

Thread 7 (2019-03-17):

schematics pdf is not searchable

dpavlin, 2019-03-17:
It seems that schematics pdf is not searchable, which is shame, since finding components is much easier using search. Just re-creating schematics from current version of KiCad wil fix it. Tested with KiCad 5.0.2+dfsg1-1 on Debian sid.

This will also create color pdf with correct orientation, so win, win :-)

emard, 2019-03-17:
J1/J2 mirrored to look the same as on PCB.
Schematics exported from "Plot" menu is now searchable.

Before I was exported it from "Print" menu and that was
the main reason of unsearchability.

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

gojimmypi, 2019-03-18:
this is a great change! and thanks for orienting the schematic to be readable in landscape mode, too :)

Closed 2019-03-19.

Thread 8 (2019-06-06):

ESP32 to SSD1331 HWSPI using correct default pin numbers?

gojimmypi, 2019-06-06:
I am unable to get the SSD-1331 display working in HWSPI (fast) mode. I'm wondering if the SPI pins are connected the same as the default ESP-Dev-Module (WROOM-32). I'm thinking perhaps not.

I was able to get the ESP32 to use the SSD-1331 display in SWSPI (slow) mode. using these pin definitions and the passthru code loaded on the FPGA:

```
// ULX3S names in physical connector order:
#define oled_csn  17 // aka cs
#define oled_dc   16 // aka ds
#define oled_resn 25 // aka rst
#define oled_mosi 15 // aka mosi
#define oled_clk  14 // aka sclk
```

For the SWSPI, the `option 1` in the [Adafruit LCDGFXDemo example](https://github.com/adafruit/Adafruit-SSD1331-OLED-Driver-Library-for-Arduino/blob/master/examples/LCDGFXDemo/LCDGFXDemo.ino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), the display is instantiated like this:

```
// Option 1: use any pins but a little slower
#pragma message "Using SWSPI"
Adafruit_SSD1331 display = Adafruit_SSD1331(oled_csn, oled_dc, oled_mosi, oled_clk, oled_resn);
```

For HWSPI, the display is instead instantiated like [this](https://github.com/adafruit/Adafruit-SSD1331-OLED-Driver-Library-for-Arduino/blob/master/examples/LCDGFXDemo/LCDGFXDemo.ino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):
```
#pragma message "Using HWSPI"
Adafruit_SSD1331 display = Adafruit_SSD1331(&SPI, oled_csn, oled_dc, oled_resn);
```

I have some addition notes in my [SSD1331 Branch of Examples](https://github.com/gojimmypi/ulx3s-examples/tree/SSD1331/VisualMicro-SSD1331-Display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)  and duplicated here:

## Arduino Implmentation Notes

This an Arduino-style solution, suitable for use with either the [Ardunio IDE](https://www.arduino.cc/en/Main/Software),
or [Visual Micro](https://www.visualmicro.com/). The display can be initialized either with this software SPI, which is
perhaps more flexible but a little slower:

```
Adafruit_SSD1331 display = Adafruit_SSD1331(cs, dc, mosi, sclk, rst);
```

... or the alternative is this hardware SPI instantiation (untested / not working at this time):
```
Adafruit_SSD1331 display = Adafruit_SSD1331(&SPI, cs, dc, rst);
```
Note the [comments in the Adafruit code](https://github.com/adafruit/Adafruit-SSD1331-OLED-Driver-Library-for-Arduino/blob/master/examples/LCDGFXDemo/LCDGFXDemo.ino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):

> hwspi hardcodes those pins, no need to redefine them.

 **As the ULX3S appears to use different pins, is HWSPI even possible?** The `cs`, `dc`, `rst` pins do not seem to be otherwise defined without the macros.

The `&SPI` is defined in `%USERPROFILE%\Documents\Arduino\hardware\espressif\esp32\libraries\SPI\src\SPI.cpp` of interest, is this initialization code:

```
    if(sck == -1 && miso == -1 && mosi == -1 && ss == -1) {
        _sck = (_spi_num == VSPI) ? SCK : 14;
        _miso = (_spi_num == VSPI) ? MISO : 12;
        _mosi = (_spi_num == VSPI) ? MOSI : 13;
        _ss = (_spi_num == VSPI) ? SS : 15;
    } else {
        _sck = sck;
        _miso = miso;
        _mosi = mosi;
        _ss = ss;
    }
```
We're looking for the defaults not explicitly stated in the declaration `Adafruit_SSD1331(&SPI, oled_csn, oled_dc, oled_resn);` specifically (`MOSI` and `SCLK`) - however here it appears `MISO` is pin 12 and `SCK` is 15 (we are expecting `MOSI`=15 and `SCK`=14) when `_spi_num != VSPI`.

TODO: where is `_spi_num` defined?

The last line of file `SPI.cpp`
```
SPIClass SPI(VSPI);
```

Note in `MAIN_ESP32_HAL_SPI_H_` (.\Arduino\hardware\espressif\esp32\cores\esp32\esp32-hal-spi.h)
```
#define VSPI  3 //SPI bus normally attached to pins 5, 18, 19 and 23, but can be matrixed to any pins
```

emard, 2019-06-06:
Hardware SPI to OLED display is of course possible.

ESP32 shares SD card pins with FPGA. In my esp32 web-jtag
firmware, so I use hardware SPI to both SD and OLED
with a small help of FPGA logic that routes it thru.

Only 1 additional esp32 gpio pin is used for chip select OLED.
So when you want to talk to OLED instead of SD card,
de-select SD_CSn=1, select OLED_CSn=0 and SPI traffic
will be received by OLED, SD will ignore it.

All you need is to control SPI chip select of
SD card to be in 3-state mode and

SD card uses
hardware SPI. Therefore, what I do is just use another
wifi

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

gojimmypi, 2019-06-06:
hello @emard and thank you for your prompt response.

yes, I saw your [ESP32 web-JTAG](https://github.com/emard/LibXSVF-ESP) project (looks very interesting, btw) ... but that's _only_ the ESP32 part and not the _small help of FPGA logic_ which I think may be the issue in my case. Does your standard [passthru](https://github.com/emard/ulx3s-examples/tree/master/passthru) include the right pins for the HWSPI OLED display? If not - what specific small help of FGPA is needed? :)

Specifically, here's what (I believe) the passthru does:
```
N2 to N3 for oled_csn /CS  to wifi_gpio17 (GPIO17)
P1 to L1 for oled_dc /DC   to wifi_gpio16 (GPIO16)
P2 to E3 for oled_resn/RES to wifi_gpio25 (GPIO25)
P3 to J1 for oled_mosi/SDA to sd_cmd      (GPIO15)
P4 to H2 for oled_clk /SCL to sd_clk      (GPIO14)
```
I have more documentation on that in my WIP example [here](https://github.com/gojimmypi/ulx3s-examples/blob/SSD1331/VisualMicro-SSD1331-Display/README.md)

Unfortunately, I've not been able to get your LibXSVF-ESP to compile. After chasing all the dependencies, I have this error on the [tft.nop()](https://github.com/emard/LibXSVF-ESP/blob/master/examples/websvf_sd/keyboard.cpp#L13):

```
'class SSD_13XX' has no member named 'nop'
```

Are you using this one: https://github.com/sumotoy/SSD_13XX ?

Is [this](https://github.com/emard/LibXSVF-ESP/blob/master/examples/websvf_sd/disp.cpp#L5) the line where you instantiate HWSPI for the display?

```
SSD_13XX tft = SSD_13XX(__CS_TFT, __DC_TFT);
```
it was my understanding that the ESP32 WROOM-32 device _can_ use both the SD and OLED at the same time. The [Adafruit code](https://github.com/adafruit/Adafruit-SSD1331-OLED-Driver-Library-for-Arduino/blob/master/examples/LCDGFXDemo/LCDGFXDemo.ino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) even has this comment:

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

but let's see if I can simply get the HWSPI OLED working solo first.

thanks a lot for your help. :)

emard, 2019-06-06:
HI

I have emard's SSD_13XX on my github
the firmware is still somehow difficult to compile

yes, in passthru bitstream is already everything
needed for OLED to work over hardware SPI

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

gojimmypi, 2019-06-06:
ah yes, [your version of SSD_13XX](https://github.com/emard/SSD_13XX). Indeed a bit difficult but I now have your [websvf_sd](https://github.com/emard/LibXSVF-ESP/tree/master/examples/websvf_sd) compiled and working.  Well, more specifically I see output on the serial port. The display is blank.

I instead then tried using your [pre-compiled websf_sd](https://github.com/emard/ulx3s-bin/blob/master/esp32/upload-executable.sh) - and in this case the display _does_ seem to work - well, at least it is not blank: an IP address is shown. The question then: was the [source](https://github.com/emard/LibXSVF-ESP/tree/master/examples/websvf_sd) for `websvf_sd/websvf_sd.ino.partitions.bin` using HWSPI? Clearly something is different between the working pre-compiled version and the source code.

If the pre-compiled version _is_ using HWSPI, then I would assume that shows the FPGA properly configured, agreed?

For the _version I compiled_ (non-working display), here are the pins being used:

```
__CS_SD =13
__MOSI_TFT =15
__MISO_TFT =2
__SCL_TFT =14
__DC_TFT =16
__CS_TFT =17
__RES_TFT =25
```

There's a note in the [README](https://github.com/emard/LibXSVF-ESP/blob/master/README.md)

> In ESP32 arduino support directory, edit file "SD.cpp"

```
// spi.begin(int8_t sck, int8_t miso, int8_t mosi, int8_t ss)
spi.begin(14, 12, 13, -1); // v1.7
spi.begin(14, 2, 15, -1); // v1.8 and higher
```

however my `SD.cpp` has only one instance of `spi.begin()` with no parameters.

```
bool SDFS::begin(uint8_t ssPin, SPIClass &spi, uint32_t frequency, const char * mountpoint)
{
    if(_pdrv != 0xFF) {
        return true;
    }

    spi.begin();

    _pdrv = sdcard_init(ssPin, &spi, frequency);
    if(_pdrv == 0xFF) {
        return false;
    }

    if(!sdcard_mount(_pdrv, mountpoint)){
        sdcard_unmount(_pdrv);
        sdcard_uninit(_pdrv);
        _pdrv = 0xFF;
        return false;
    }

    _impl->mountpoint(mountpoint);
    return true;
}
```
I've made no edits to my `SD.cpp` at this time.

emard, 2019-06-06:
Yea, you have to somehow modify/fix  sources in the
SPI driver to use port of ESP32 with pins that are shared
with SD card

it works if it is showing IP address

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

gojimmypi, 2019-06-07:
It appears the HWSPI is using these values in `SPIClass::begin` found in the ESP32 `SPI.cpp` file:
```
// SPIClass _sck=18
// SPIClass _miso=19
// SPIClass _mosi=23
```
From the schematic, there's a note for `VSPI` using those same pins (is VSPI considered HWSPI?)
```
ESP32 VSPI pins
GPIO5: SS
GPIO18: SCK
GPIO19: MISO
GPIO23: MOSI
```

Those pins do not appear to be in the FPGA passthru, so I modified the [passthru.v](https://github.com/emard/ulx3s-examples/blob/master/passthru/DiamondVerilog/passthru.v) to include these lines in the module declaration:

```
	// HWSPI
	inout  wire wifi_gpio5, // GPIO5
	input  wire jtag_tck,   // GPIO18
	inout  wire jtag_tdo,   // GPIO19
	inout  wire jtag_tdi,   // GPIO23
```

and these assignment edits for `clk` and `mosi`:

```
	assign S_oled_csn = wifi_gpio5; // was wifi_gpio17;
	assign oled_csn = S_oled_csn;
	assign oled_clk = jtag_tck; // GPIO18 was // sd_clk WiFi_GPIO14
	assign oled_mosi = jtag_tdi; // GPIO23;  was //  WiFi GPIO15
```

I didn't know what to do with `GPIO19` (`JTAG_TDO`) for `MISO` as there's only a `MOSI` connector on the display.

I left the other assignment the same:

```
#define oled_csn  5 // aka cs was 17
#define oled_dc   16 // aka ds
#define oled_resn 25 // aka rst
#define oled_mosi 23 // aka mosi was 15
#define oled_clk  18 // aka sclk was 14
```

And still, the HWSPI display does not work. With the non-modified passthru, I can get the slower SWSPI working. Any other tips for HWSPI? Thanks

emard, 2019-06-07:
well It was a long time I was doing it for the firmware
so I can help you from the memory.

It is absolutely possible to get hardware SPI working with OLED
using default passthru.

Maybe you got confused with old v1.7 notes on schematics, that's
now obsolete. Follow only the wires and where they lead to. I updated
schematics cleaning up from v1.7

Pins that are now going to FPGA JTAG cannot be
used for anything else but JTAG so passthru bitstream won't pass them thru.

Only pins that are verified in practice that work are those shared with SD
and 1-2 years agoi I had to to modify esp32arduino's SPI sources to change
default pinout, I don't know if recent sources have more clean way of setting
the pinout or again editing the source...

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
gojimmypi, 2019-06-09:
I forgot to add that regarding changing esp32arduino's SPI sources - that's not very practical. The only option for the end user would be to add conditional board type... the ULX3S? It's not really - as it is actually the ESP32 board.

I'm also curious about the _FPGA JTAG cannot be used for anything else but JTAG_ comment. Can you provide more details?

emard, 2019-06-09:
In the question is also the answer - they list DEFAULT pinout for
xSPI and default can be changed to something custom.

It is ESP32 firware to work on not passthru bitstream.

It is not possible to force ECP5 fpga to use it's JTAG pins
as GPIO, therefore you got this
"WARNING - Specified location site name "T5" is not valid for..."

OTOH It is possible to let ESP32 change its pins for xSPI interfaces.

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

emard, 2019-07-15:
As hardware SPI from ESP32 works to SD card and OLED in my firmware
I will close this issue. ULX3S is wired correctly to allow hardware SPI with ESP32
and to discuss firmware issues it is more fruitful to refer to ESP32 related gits and forums

Closed 2019-07-15.

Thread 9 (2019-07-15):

Future 10 MHz ADC

hdl4fpga, 2019-07-15:
Is it possible to add a 10 MHz ADC in future versions ?
I think it would be very useful, as DVB-T and ISDB-T both are digital broadcasting system that are  10MHz-bandwidth OFDM signal making the ULX3S a very professional low cost DSP lab.
DVB-T is the European standard while ISDB-T is the open standard that is used in Japan and South America. Covering a huge demand.

emard, 2019-07-15:
Most easily it would be to add it external, connected to one side of
2.54 ports which will for example be such 10 MHz ADC from ebay
maybe 20-50$ cost

on ULX3S we are running out of free pins...
PCB must support all chips from 12F to 85F and therefore it uses
only those pins that are common to all 12,25,45 and 85F BGA-381 packages.

There is only about 10 such free pins left and they are mostly in the center
of BGA, this area is nearly inaccessible with the low cost 4-layer PCB.

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

hdl4fpga, 2019-07-15:
Ohhh ... I got it

thanks

gojimmypi, 2019-07-23:
@hdl4fpga I've hooked up the ULX3S to an external AD/DA board; see [blog](https://gojimmypi.blogspot.com/2018/06/ad9280-ad9708-ad-da-module-for-ax.html) and some brief [notes](https://gojimmypi.blogspot.com/2019/03/ulx3s-sdr-with-alinx-adda.html). I also have a custom OshPark board to connect them.

See also: https://github.com/gojimmypi/ulx3s-adda  ([development branch](https://github.com/gojimmypi/ulx3s-adda/tree/development) has [PCB Adpater Board](https://github.com/gojimmypi/ulx3s-adda/tree/development/adapter_board))

All not as polished as I might like, but perhaps you'll find something useful.

hdl4fpga, 2019-07-23:
It looks nice!

<https://www.avast.com/sig-email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>
Virus-free.
www.avast.com
<https://www.avast.com/sig-email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>
<#DAB4FAD8-2DD7-40BB-A1B8-4E2AA1F9FDF2>

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

gojimmypi, 2019-07-23:
@hdl4fpga  - if you go down that road and buy one of those AD/DA boards, I can probably send you one of the adapter boards, if you want.

hdl4fpga, 2019-07-23:
Thanks

I have one old NU Horizons' SPARTAN 3A DSP  board with a LT Dual 14-Bit,
125Msps 500Mhz. When I proposed to change the ADC, I was thinking on
replacing the ones that are already on the ULX3S board. I haven't had
enough time to see it in details yet

Regards

<https://www.avast.com/sig-email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>
Virus-free.
www.avast.com
<https://www.avast.com/sig-email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>
<#DAB4FAD8-2DD7-40BB-A1B8-4E2AA1F9FDF2>

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

Closed 2019-07-15.

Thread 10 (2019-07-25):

Kitspace Digikey/Mouser links still an issue?

kasbah, 2019-07-25:
Hey, I was just re-reading the readme. I noticed this section:

> Parts can be ordered from Detailed BOM or from ULX3S at Kitspace, which automatically submits Simplified 1-click BOM by clicking on "Digikey" or "Mouser" button. On each click, Digikey and Mouser will keep accumulating the BOM in the shopping cart. Number of unique parts on Digikey and Mouser should be equal but Digikey scripts have bugs. First time click on "Digikey" will upload a partial BOM, then the shopping cart must be reset and next click on "Digikey" will upload complete BOM. To reset shopping cart, click "New Cart" or "New Basket". Kitspace may be updated with about 1 day delay after this project update.

Can you confirm that Digikey links still have this issue?

emard, 2019-07-25:
No, I updated readme.

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

kasbah, 2019-07-25:
Thanks!

Closed 2019-07-25.

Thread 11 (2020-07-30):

Git Tags for Board Versions

bluesceada, 2020-07-30:
Is it possible to get git tags for respective board versions? We have earlier versions of the board, and it is not so easy to find the correct documentation.

emard, 2020-07-30:
That's true, I should train myself to tag releases
(It will be my first-time use of git options :)

Let me know what board you have, I think it only differs in some
LED control lines of usb-serial chip, very unimportant for average use.

Online PDF schematics its still for v3.0.x boards on my git which
are currently circulating everywhere.
kicad project online is for v3.1.1 - ready for prototyping.

v3.1.1 is because of issues with ESP32, currently workarounded in
software while clean solution is rewiring pins.
ESP32 is rewired to allow use of its RMII ETH interface and to
get rid of SPI-JTAG glitches that happen to esp32ecp5.
Clean esp32ecp5 script ready for v3.1.1 is here:
https://github.com/emard/esp32ecp5/blob/master/new/ecp5.py

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

emard, 2020-07-31:
Releases tagged.

bluesceada, 2020-08-12:
I don't see the tags, did you push them?

emard, 2020-08-12:
UPS!

I tagged on my development computer and obviously forgot to push
this week I'm away that computer so I can push earliest next week.

If you have some board and need to know which commit it belongs
to I can help

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

bluesceada, 2020-08-12:
We have v3.0.3 boards and it would be nice to have the right schematics for it. The whole git commit history and/or file hierarchy is hard to understand for me regarding what belongs to which version.

emard, 2020-08-12:
For v3.0.3 version you can use v3.0.8 PDF schematics
https://github.com/emard/ulx3s/blob/master/doc/schematics_v308.pdf
which is online in the current git. Your board has exception that
FTDI_nRXLED is not connected to FPGA on your board and
this is noted "NC <v3.0.5" on the page 6 of PDF at upper right corner,
quadrant A1

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

bluesceada, 2020-08-12:
Thanks, that helps (me at least). Your tags will hopefully make it easier to find for others later.

emard, 2020-08-12:
I think I did git tag and push but as tags were
done backwards in time maybe github didnt accept
or I missed some option, I will see and push them somehow

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

bluesceada, 2020-08-13:
As far as I know pushing tags can be a bit complicated with git. Especially if they are not annotated tags (tags with an additional descriptive message). So you might need to push them separately. To push all tags you have, you could use `git push --tags`. It is not recommended (since it could be a lot), but I guess it will do the job.

emard, 2020-08-13:
Yes tags I made were not annotated tags
I did simple "git push" and thought it would do the job

I should have cloned the respository in other directory
and check did the tags made it there but that I didnt do
next week I get to the PC which tagged them and will
retry

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

emard, 2020-08-17:
Last time I did just "git push" and tags were not sent.
Now I did "git push --tags" and it seems to work,
I cloned to /tmp directory and tags are still there!

Not all releases were tagged, only those that I know
have been produced and maybe few others what
could/should have been produced.

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

Closed 2020-07-31.

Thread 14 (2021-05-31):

Sample code for using LAN8720

developandplay, 2021-05-31:
Hi @emard,
thank you for creating such a good ulx3s guide.
I did get the LAN8720 module to try out ethernet on the ulx3s.

First of all is there anything I need to bear in mind regarding the pyhsical connection to the ulx3s?
Right now I just plugged it in from 9 to 13 like you mentioned in the README.

Second do you have any example code for using the module?
I tried using it in Litex but I assume I wired somthing up improperly as the my code doesn't work as expected.

emard, 2021-06-01:
HI

saxonsoc binary linux from lawrie at github should use LAN8720 out of the box.
It will autodetect eth at boot it and you can start ssh and ping
around.

LAN8720 is directly pluggable to ULX3S. You can either
solder FEMALE 90° connector on top side on ULX3S and plug module
or solder MALE 0° (straight pins) on bottom side of ULX3S and use
old CDROM/IDE 40-pin flat cable (female both sides) to connect to LAN8270 module

LAN8270 is only for 3.3V power GP 9-13. If you connect it to 5V side, it
must goto trash.

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

emard, 2021-06-01:
Here is also elementary verilog example which will
do some elementary packeting on the module and leds
blinking but don't expect full TCPIP

https://github.com/emard/ulx3s-misc/tree/master/examples/eth/rmii/proj

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

gojimmypi, 2021-06-07:
@emard this is a very cool example... thanks for sharing! I can confirm [it works](https://gojimmypi.github.io/gridster-jekyll-theme/ulx3s-fpga-ethernet/)! :)

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

emard, 2021-06-07:
eheheeee, great testing, thanx!!
I was also happy when LAN8720 started working,
thanks to proper readme I could do it too, after almost a year :)

I had some hacks with init sequence for ST7789
to make it more reliable with some displays with
green tab stickers (probably some very early chip
releases).

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

emard, 2021-06-07:
Actually you have green tab too :)

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

developandplay, 2021-06-08:
I got to try the sample today and it works nicely.
One thing that I noticed is as you mentioned in the project readme it's crucial to first connect VCC and GND.
This can be achieved by plugging it in slightly angled.
Powering on the FPGA with the LAN8720 already plugged in doesn't work for me.

Thanks for providing the sample now I will try to get it running in Litex and report back.

emard, 2021-06-09:
HI

Modules LAN8720 from ebay are slightly different there exist at least
2 visually different (bottom side is easier to make difference).

The problem is that module needs some "normal" power up default which means
pullups and pulldowns if when plugged to ULX3S at early boot time must keep the
same states as modules hardware default, which is not always possible because
FPGA takes time to boot from SPI flash so correct pullups are enabled
but too late, module already booted in wrong mode (usually 10Mbit or wrong clock
direction)

module has its own MDIO control interface,.that's similar to SPI and I
think all registers
can be set later. Probably a small verilog ROM initializer to just
write registers to
"normal" default should be good enough but my code doesn't have it yet.

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

emard, 2022-04-22:
yes yes its pure chance that clock capable pin matches lan8270 module (I
didnt know about this
module when I was routing PCB :). Because of confusing docs there are some
other misroutings
but practicaly everything turned out to work well so the board was followed
with luck :)

On Thu, Apr 21, 2022 at 5:17 PM Oliver Keller ***@***.***>
wrote:

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

ozel, 2022-04-22:
thanks a lot for your quick response! This means the PCLK pins are mostly needed for using the fancy DDR blocks, I guess.

I really enjoy how well thought out this board is, it doesn't look just like lucky coincidences to me. :-) It's probably the most sophisticated dev board I had in my hands. I'll be looking into high bandwidth transfers between ESP32 and ECP5. SDIO and RMII seem nice candidates.

emard, 2022-04-23:
Thanx you like the board! It has been designed to have
some interesting parts with onboard routing not available on market.

ESP32 is practical tool but not too fast, on my ftp and wifi usually has
100-300 KB/s (1-3 Mbit/s) transfer to SD card or ECP5 from micropython.
New boards v3.1.7 routing supports ESP32 to RMII to external LAN8270
module (I tested that) or RMII ECP5 (linux or similar) should also work
but I have yet no demo example, however speed is still 100-300 KB/s
transfer rate on ESP32 RMII (tested with micropython and SD card)

It is very practical as connectivity feature.
Theoretically it can be faster maybe there's some optimizations
compile binary instead of micropython, router settings etc.

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

HAZ247, 2025-06-25:
Hi I tried to make transmitter on VHDL using the same logic but it is not working can some one help!
Code
{
library IEEE;
use IEEE.STD_LOGIC_1164.ALL;
use IEEE.NUMERIC_STD.ALL;

entity arp_reply_fixed is
    Port (
        clk_25mhz  : in  std_logic;
        btn        : in  std_logic_vector(6 downto 0);
        gp11       : in  std_logic;
        gn11       : in  std_logic;
        gp12       : in  std_logic;
        gn12       : in  std_logic;       -- PHY 50 MHz clock
        gn9        : out std_logic;       -- RMII TXD1
        gp10       : out std_logic;       -- RMII TXD0
        gn10       : out std_logic;       -- RMII TX_EN
        gp13       : out std_logic;       -- MDC (held low)
        gn13       : out std_logic      -- MDIO (tri-stated)
    );
end arp_reply_fixed;

architecture rtl of arp_reply_fixed is
    signal rmii_clk     : std_logic := '0';          -- Clock from PHY (50 MHz)
    constant REPLY_LEN    : integer := 82;
    -- Total RMII cycles = REPLY_LEN bytes × 4 (2 bits/cycle)
    constant TOTAL_CYCLES : unsigned(12 downto 0) := to_unsigned(REPLY_LEN * 4, 13);

    type packet_array_t   is array (0 to REPLY_LEN-1) of std_logic_vector(7 downto 0);
    signal arp_packet     : packet_array_t;

    signal txindx         : unsigned(12 downto 0) := (others => '0');
    signal tx_shift       : std_logic_vector(7 downto 0) := (others => '0');
    signal tx_en          : std_logic := '0';
    signal rmii_mdc       : std_logic := '0';
begin
    ----------------------------------------------------------------------------
    -- Concurrent assignments
    ----------------------------------------------------------------------------
    -- Use PHY REFCLK directly for RMII clock
    -- (you could also rename rmii_clk to gn12 and use it in processes)
    -- Hold MDC low (we’re not using MDIO management)
    rmii_clk  <= gn12;          -- 50 MHz from PHY
    gp13 <= rmii_mdc;

    ----------------------------------------------------------------------------
    -- Packet initialization (runs once at elaboration)
    ----------------------------------------------------------------------------
    arp_init : process
    begin
        arp_packet <= (
        x"00", x"00", x"00", x"00", x"00", x"00", x"00", x"00",  -- Preamble (first 8 bytes often discarded)
        x"55", x"55", x"55", x"55", x"55", x"55", x"55", x"d5",  -- Ethernet preamble + Start Frame Delimiter (SFD)

        -- Ethernet Header
        x"ff", x"ff", x"ff", x"ff", x"ff", x"ff",                -- Destination MAC: FF:FF:FF:FF:FF:FF (broadcast)
        x"00", x"40", x"00", x"01", x"02", x"03",                -- Source MAC: 00:40:00:01:02:03
        x"08", x"06",                                           -- EtherType: 0x0806 = ARP

        -- ARP Payload
        x"00", x"01",                                           -- Hardware type: Ethernet (1)
        x"08", x"00",                                           -- Protocol type: IPv4 (0x0800)
        x"06",                                                  -- Hardware size: 6 (MAC address length)
        x"04",                                                  -- Protocol size: 4 (IPv4 address length)
        x"00", x"02",                                           -- Opcode: 2 (ARP Reply)
        x"00", x"40", x"00", x"01", x"02", x"03",               -- Sender MAC address: 00:40:00:01:02:03
        x"c0", x"a8", x"12", x"80",                             -- Sender IP address: 192.168.18.128
        x"ff", x"ff", x"ff", x"ff", x"ff", x"ff",               -- Target MAC address: FF:FF:FF:FF:FF:FF
        x"c0", x"a8", x"12", x"80",                             -- Target IP address: 192.168.18.128

        -- Padding / Ethernet minimum frame size enforcement
        x"00", x"00", x"00", x"00", x"00", x"00",               -- Padding (6 bytes)
        x"00", x"00", x"00", x"00", x"00", x"00",               -- Padding (6 bytes)
        x"00", x"00", x"00", x"00", x"00", x"00", x"00",x"00",              -- Padding (6 bytes)

        -- CRC / Trailer (may or may not be used in simulation)
        x"6d", x"2a", x"fe", x"d9"                              -- Frame Check Sequence (CRC32)

        );
        wait;  -- suspend forever
    end process arp_init;

    ----------------------------------------------------------------------------
    -- Transmit process (serializes 8-bit words to RMII 2-bit output)
    ----------------------------------------------------------------------------
    tx_proc : process(rmii_clk)
    begin
        if rising_edge(rmii_clk) then
            if txindx /= to_unsigned(REPLY_LEN * 4, txindx'length) then -- fix expression
                if txindx(1 downto 0) = "00" then
                    tx_shift <= arp_packet(to_integer(txindx(12 downto 2)));
                else
                    tx_shift <= "00" & tx_shift(7 downto 2);  -- Right shift by 2 bits
                end if;
                tx_en <= '1';
                txindx <= txindx + 1;
            else
                if btn(1) = '1' then
                    txindx <= (others => '0');
                else
                    tx_en <= '0';
                end if;
            end if;
        end if;
    end process;

    ----------------------------------------------------------------------------
    -- RMII outputs
    ----------------------------------------------------------------------------
    gn10 <= tx_en;          -- TX_EN
    gp10 <= tx_shift(0);    -- TXD0
    gn9  <= tx_shift(1);    -- TXD1

    ----------------------------------------------------------------------------
    -- MDIO tri-state (unused)
    ----------------------------------------------------------------------------
    gn13 <= 'Z';

end rtl;

}

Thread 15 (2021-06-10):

SD card detect pin

developandplay, 2021-06-10:
Does the ulx3s feature an SD card detect pin?
I looked at the pinout but couldn't find  it under that name...

emard, 2021-06-10:
No - even new PCB v3.1.7 design doesn't have CD signal connected.
PCB is very crowded, hardly no free routable pins.
with some nontrivial work and redesign it should be possible to
connect CD to FPGA, I think there's 1 free pin around SD but
difficult to route

SD card driver can query card and quickly know is card inserted
without need for CD pin.
Do you have some practical situation when CD is really good for?

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

developandplay, 2021-06-10:
In Litex we have support for the CD pin.
This is then passed on to the Linux driver.
See this issue for reference:
https://github.com/litex-hub/linux-on-litex-vexriscv/issues/171#issuecomment-763728692

When using the ulx3s currently the same [problem](https://github.com/litex-hub/linux-on-litex-vexriscv/issues/203#issue-816841348) occurs.

Therefore I just wanted to ask if the ulx3s has a CD pin as it would be the easiest solution.
Considering that it doesn't exist I'll think of some work around along the lines of your suggestion.

emard, 2021-06-11:
OK I understand, having CD switch would be of a practical use
with litex. There's currently no hardware switch at sockets on
v3.0.x boards

For v3.1.x board, I will check what can be done at design
but given the total market unavailability of most of chips
for ulx3s, new boards won't be there until next year anyway
so better workaround for now

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

Closed 2021-06-15.

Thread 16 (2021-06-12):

Example code of using SD card in SDIO mode

developandplay, 2021-06-12:
I got SPI mode to work in Litex but had no luck with SDIO mode.
Is that supported?
If yes do you have some sample code for it?

emard, 2021-06-12:
If you want to use 4-bit mode then all sd_d[3:0] lines
need to have pullups enabled from SD card side.

If you are using 1-bit (SPI) mode probably the best
is to explicitely drive 1 unused bits sd_d[2:1] = 2'b11

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

emard, 2021-06-13:
additional explaination

If you want to use 4-bit mode then all sd_d[3:0] lines
need to have pullups enabled from FPGA constraints.

For pullups to be active, all sd_d lines must be used in the
design (connected to some logic).

If any sd_d line is not connected anywhere the pullup
will be also removed by router/optimizer.

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

emard, 2021-06-13:
Similar holds for FLASH. If it is used in 1-bit mode,
unused lines must be driven 1

pullup is not enough for flash, unused lines must be driven
1. If unused lines are left floating. line crosstalk will happen
and some FLASH chips will work, but some will be confused by
crosstalk noise and will not work making FLASH boot not work
for all users and boards.

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
>>> I got SPI mode to work in Litex but had no luck with SDIO mode.
>>> Is that supported?
>>> If yes do you have some sample code for it?
>>>
>>> --
>>> You are receiving this because you are subscribed to this thread.
>>> Reply to this email directly or view it on GitHub:
>>> https://github.com/emard/ulx3s/issues/16
>>
>

developandplay, 2021-06-15:
What does this comment mean?
> IOBUF  PORT "sd_d[2]" PULLMODE=NONE IO_TYPE=LVCMOS33 DRIVE=4; # WiFi GPIO12 pulldown bootstrapping without 3.3V efuse

emard, 2021-06-15:
SD card is shared (connected together) with FPGA and ESP32.

sd_d[2] goes to esp32 wifi_gpio12

SD default is normally all pins pull up, but factory default
ESP32 has internal pull down to wifi_gpio12 to boot properly,
that's why FPGA sets pull to none to let esp32 boot. wifi_gpio12
controls the voltage (1.8V or 3.3V) esp32 will apply to its internal flash.

ESP32 efuse can be programmed to apply 3.3V and
ignore wifi_gpio12 - that's described in the manual.
efuse is one-time-programmable, setting can't be undone
so users must be careful not to brick esp32

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

developandplay, 2021-06-15:
Just to make sure I understand correctly:
So my ulx3s is currently still in factory default mode.
If I just want to use the SD card with the FPGA I don't need to set the efuse right?

goran-mahovlic, 2021-06-15:
If you have board from CrowdSupply - then fuse is already set (burned) to 3.3V

developandplay, 2021-06-16:
I got mine on Mouser and the ESP32-WROOM-32 is used if that makes a difference...

emard, 2021-06-16:
You can see if 3.3V efuse is already set when esptool.py programs the esp32
it will show "VRef calibration in efuse",

Features: WiFi, BT, Dual Core, 240MHz, VRef calibration in efuse,
Coding Scheme None

that means that gpio12 is free to be used regardless of its powern on
pull up/down state.

Usualy problem is that some SD cards do internal pull ups and prevent
esp32 from booting or programming when SD is inserted.

to prevent user's problems intergalaktik burns efuse to
correct state before shipment

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

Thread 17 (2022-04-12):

Wrong SDRAM part number in schematic for version 3.17

mahesh-electronut, 2022-04-12:
As per `schematics_v317.pdf`, SDRAM part number is **MT48LC16M16A2TG**. But the part populated on the v317 board is **IS42S16160G-7TL**. Please update the schematic PDF.

mahesh-electronut, 2022-04-12:
Thanks for the quick reply @goran-mahovlic . That sounds fine.

Just one more clarification I needed:

IS42S16160G shows pins DQ0 to DQ07 whereas MT48LC16M16A2TG has D0 to D15. I found an SDRAM controller for MT48LC16M16A2TG , but I am wondering if it work for IS42S16160G because of this difference. Thanks for any input on this.

Closed 2022-04-12.

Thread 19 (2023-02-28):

Getting the board version number

szoshi, 2023-02-28:
I have purchased a new board but am unable to locate a revision number on it. It says "skriptarnica.hr" on the back where the ESP32 chip can be soldered. The documentation says that the boards sold through this website are v3.0.3. Does that apply to my board too? I cannot find any schematics for the above version. Is there any alternative version of the schematics that I can refer to?

goran-mahovlic, 2023-02-28:
Hi,

3.0.3 is quite old, could you send picture of the board?
I think @emard can find datasheet and point to lpf if you really have 3.0.3

Do you have a link from that store?

emard, 2023-02-28:
Turn board on back side "landscape"
then look approx in the middle of the board
then slightly left or right, it should be written
v3.0.8 or v3.1.7 those are most popular versions
sold. If you bought recently from mouser
should be v3.1.7

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

szoshi, 2023-02-28:
Hello,

mine says 3.0.3. I was unable to spot it initially. Where can I find documentation for this version?

Thanks,

goran-mahovlic, 2023-02-28:
Oh I fond one more 3.0.3 board on ebay - it is probably some student from Croatia.

Anyway I think schematics is this one as 3.0.3 and 3.0.8 d not have big difference.

https://github.com/emard/ulx3s/blob/master/doc/schematics_v308.pdf

I do not know if lpf is same as on this repository, but FER has 3.0.8 here: http://www.nxlab.fer.hr/dl/ulx3s.lpf

emard, 2023-02-28:
for most projects you can use v3.0.8 schematics for v3.0.3
https://github.com/emard/ulx3s/blob/master/doc/schematics_v308.pdf
and practically all v2.1.x and v3.0.x binaries are interchangeable

there are small differences around connecting gpio signals and
from usb-serial to fpga and esp32-gpio sharing, rarely any project
we know really needs them, if you get stuck around there as us
and we can help

you can pull git and "reset hard" to release v3.0.3 to get back
to exact state when v3.0.3 was produced

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

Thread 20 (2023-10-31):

Schematics for 3.1.8 from Mouser?

fsctl, 2023-10-31:
Hi emard,

I ❤️ the ULX3S, but one I [bought from Mouser last week](https://www.mouser.com/ProductDetail/392-CS-ULX3S-03) is giving me trouble and I cannot find schematics for it.

The board has silkscreen on the back that says `3.1.8`.  But the latest Kicad file in this repo is only `3.1.7`.  Where can I get the schematics for board `3.1.8`?

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

The specific problem I'm trying to debug is that the ESP32 is not recognized by `esptool.py` or any other tool, and I suspect that's because the ESP32-WROVER-E's `EN` pin is only at 1.7V.  The board has been a bit flaky in other ways too.  Would be much easier to debug with the schematic.

By the way, output of `ftx_prog` in factory configuration shows board at version `3.0.8`.  I assume I should change this to `3.1.8`?

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

Thank you!

goran-mahovlic, 2023-10-31:
Hi,
v3.1.8 is on my repository. Nothing special is changed just number of layers and logos.
So schematics from v3.1.7 is still ok for checking.

You can contact me at goran.mahovlic@gmail.com or on discord it will be easyer to trace a problem

https://discord.com/invite/8pgjZqG9Ur

Goran

emard, 2023-10-31:
If you like, you can rename the board to 3.1.8
in the manual it is described how to do it using
opensource ftx_prog on linux and name it back
if needed. I'm not shure how many reflashings
of this are allowed, but for few changes it should
be fine

fujprog needs to be recompiled to accept
new version, that's why we are reluctant to
give the board latest versions. openFPGAloader
and others doesn't care about version.

On Tue, Oct 31, 2023 at 8:23 AM Goran Mahovlic ***@***.***>
wrote:

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

fsctl, 2023-10-31:
Thanks, @goran-mahovlic.  I think I was using the `*_v20_*` version of the constraints file when I flashed (since `ftx_prog` was originally reporting it as a v3.0.8 board and I assumed it was; didn't see the silkscreen until later), and maybe that was pulling ESP32's `EN` low by competing with the hardwired pull up on that pin.  I'll investigate it more this weekend and reach out on email or discord if I'm still having problems.  Closing this issue now as you have answered my question -- thanks!

goran-mahovlic, 2023-10-31:
> Thanks, @goran-mahovlic. I think I was using the `*_v20_*` version of the constraints file when I flashed (since `ftx_prog` was originally reporting it as a v3.0.8 board and I assumed it was; didn't see the silkscreen until later), and maybe that was pulling ESP32's `EN` low by competing with the hardwired pull up on that pin. I'll investigate it more this weekend and reach out on email or discord if I'm still having problems. Closing this issue now as you have answered my question -- thanks!

Thank you! And remember for accesing esp32 over serial you always need to have passthrue or create your own.

I think latest source for pass is here

https://github.com/emard/ulx3s-misc/tree/master/examples/esp32_passthru/proj

And bitstream here: https://github.com/emard/ulx3s-bin/tree/master/fpga/dfu/85f-v317

Closed 2023-10-31.

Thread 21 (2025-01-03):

New Year's Wishlist

emard, 2025-01-03:
Deer Santa 🎅

❄ Support placing ESP32-S3 with PSRAM and FLASH.
  Allow US1 to be routed to ESP32-S3 USB pins instead of FT231X
  (When ESP32-S3 is placed, FT231X should not be placed.)

❄ Route 3 prog indicator LEDs (BLUE, GREEN, RED)
  To pins of ESP32-S3. Turning ON GREEN LED wakes up ULX3S from RTC sleep.

❄ Route 5V that powers FT231X (maybe unmounted) to 5V input of ESP32-S3. Need some
  jumper or 0-ohm resistor to remove 5V from old ESP32 which accepts
  only 3.3V

❄ Route all avialbble GPIO of ESP-32 (TX/RX serial etc) to FPGA.

❄ try to Keep some compatibility with FT231X and old ESP32-WROVER

❄ allow placing ESP32-32E instead of ESP32-WROOM, for this
  we should add top row of pins

❄ Discard support for old ESP32-WROOM. It can be still placed but will
probably not boot when top row pins are connected.

❄ BTN0 as ESP32S3 "BOOT" button
  ULX3S BTN0 - diode - GPIO0 ESP32-S3
  Holding BTN0 and powering ULX3S should allow ESP32-S3
  to enter mode that accepts firmware upload over USB
  One additional diode has to be used for this.

             1N914
    PWRBTn  --|<-- GPIO0

❄ Micro USB -> USB-C
USB-C are much better connecters, 180 deg symmetrical
Thru-hole GND shield for more mechanical strength,
micro-usb are easy to break

emard, 2025-01-03:
GPIO0 is already routed to FPGA now it can be used
to read BTN0, it is possible remove old FPGA input for BTN0 - PWRBTn
or see if we should keep it for backwards compatibility

gojimmypi, 2025-01-04:
If it is going to be a _wish_ list, perhaps you'll consider replacing the classic ESP32 with the `-C` series instead. Those are the RISC-V chips, and moving forward [Espressif is all-in on RISC-V](https://x.com/EspressifSystem/status/1517751876128673792).

emard, 2025-01-04:
You can obviously predict things and read mind remotely :)
yes from beginning we wanted esp32 with usb integrated
to skip ftdi chip, first attempt was esp32-s2 but we didn't know
how to initialize usb-jtag and available S2 modules had no
PSRAM. Now here's esp32-s3 filled with much PSRAM
and I guess with some hacking S3 can provide all we need
to say ft231x goodbye :)

Idealy would be if I find out how to configure/compile
micropython for ESP32-S3 so that its USB exposes
usb-serial with 2 additional endpoints used for JTAG.
It's HWCDC with JTAG all in S3 hardware just it need
to comehow enabled at compile time. I can compile
such setup from arduino, now Im just looking how to
compile micropython  to expose HWCDC. Currently
out of the box it exposes only usb-serial

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

emard, 2025-01-04:
This is what I asked at micropython github issues maybe
someone can help
https://github.com/micropython/micropython/issues/16511

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

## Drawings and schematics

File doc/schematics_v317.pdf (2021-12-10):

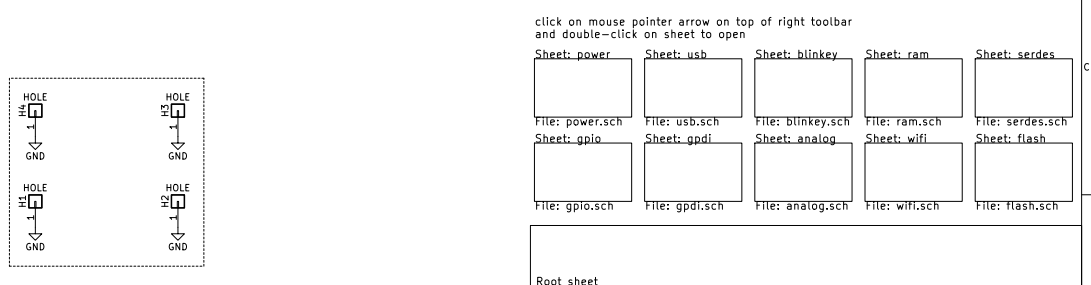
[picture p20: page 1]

click on mouse pointer arrow on top of right toolbar
and double-click on sheet to open
Root sheet Sheet: power

Sheet: usb File: usb.sch

Sheet: serdes File: serdes.sch Sheet: flash File: flash.sch Sheet: analog

1 H4 HOLE GND GND GND GND

File: ram.sch Sheet: wifi File: wifi.sch Sheet: gpdi

File: ulx3s.sch Sheet: / EMARD

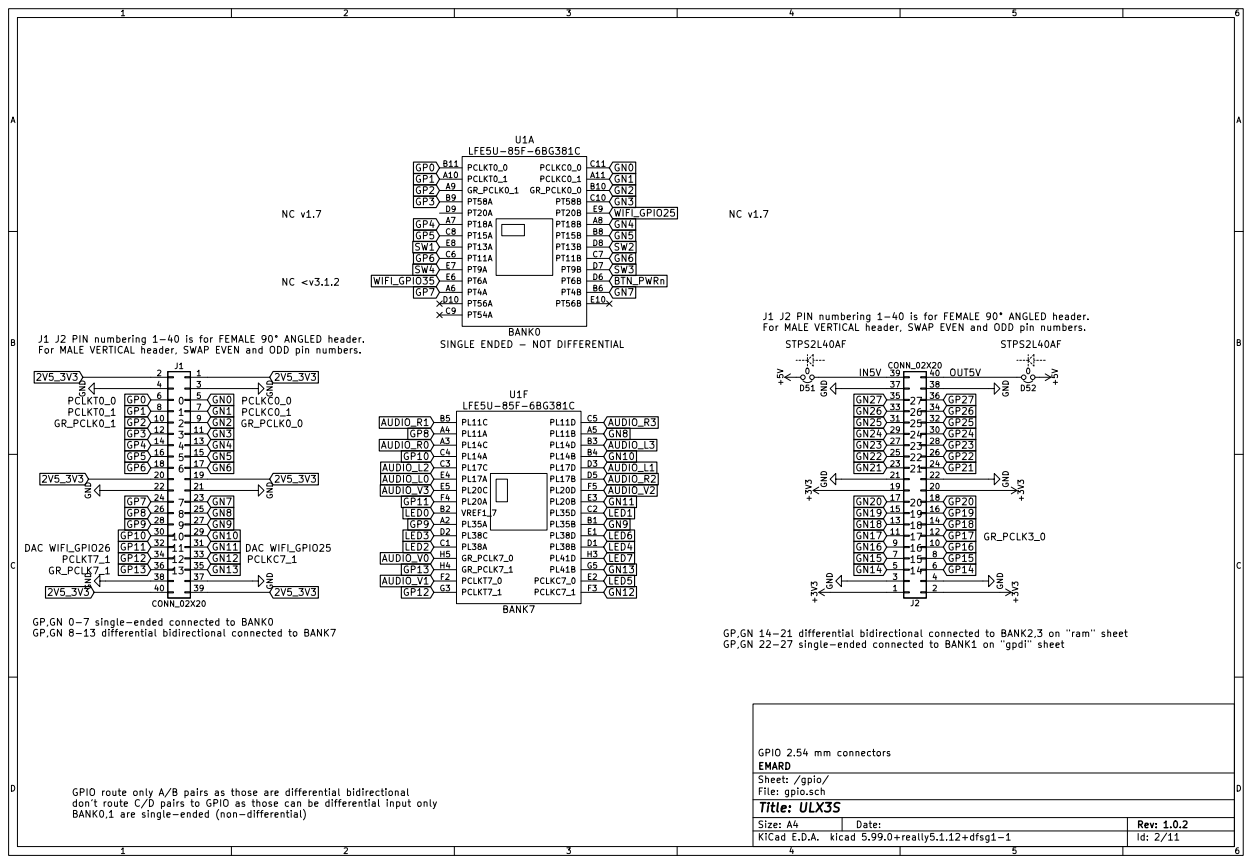
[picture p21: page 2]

J1 J2 PIN numbering 1-40 is for FEMALE 90° ANGLED header.
For MALE VERTICAL header, SWAP EVEN and ODD pin numbers.
STPS2L40AF

SINGLE ENDED - NOT DIFFERENTIAL

GP,GN 0-7 single-ended connected to BANK0
GP,GN 8-13 differential bidirectional connected to BANK7

GP,GN 22-27 single-ended connected to BANK1 on "gpdi" sheet

GPIO route only A/B pairs as those are differential bidirectional
don't route C/D pairs to GPIO as those can be differential input only

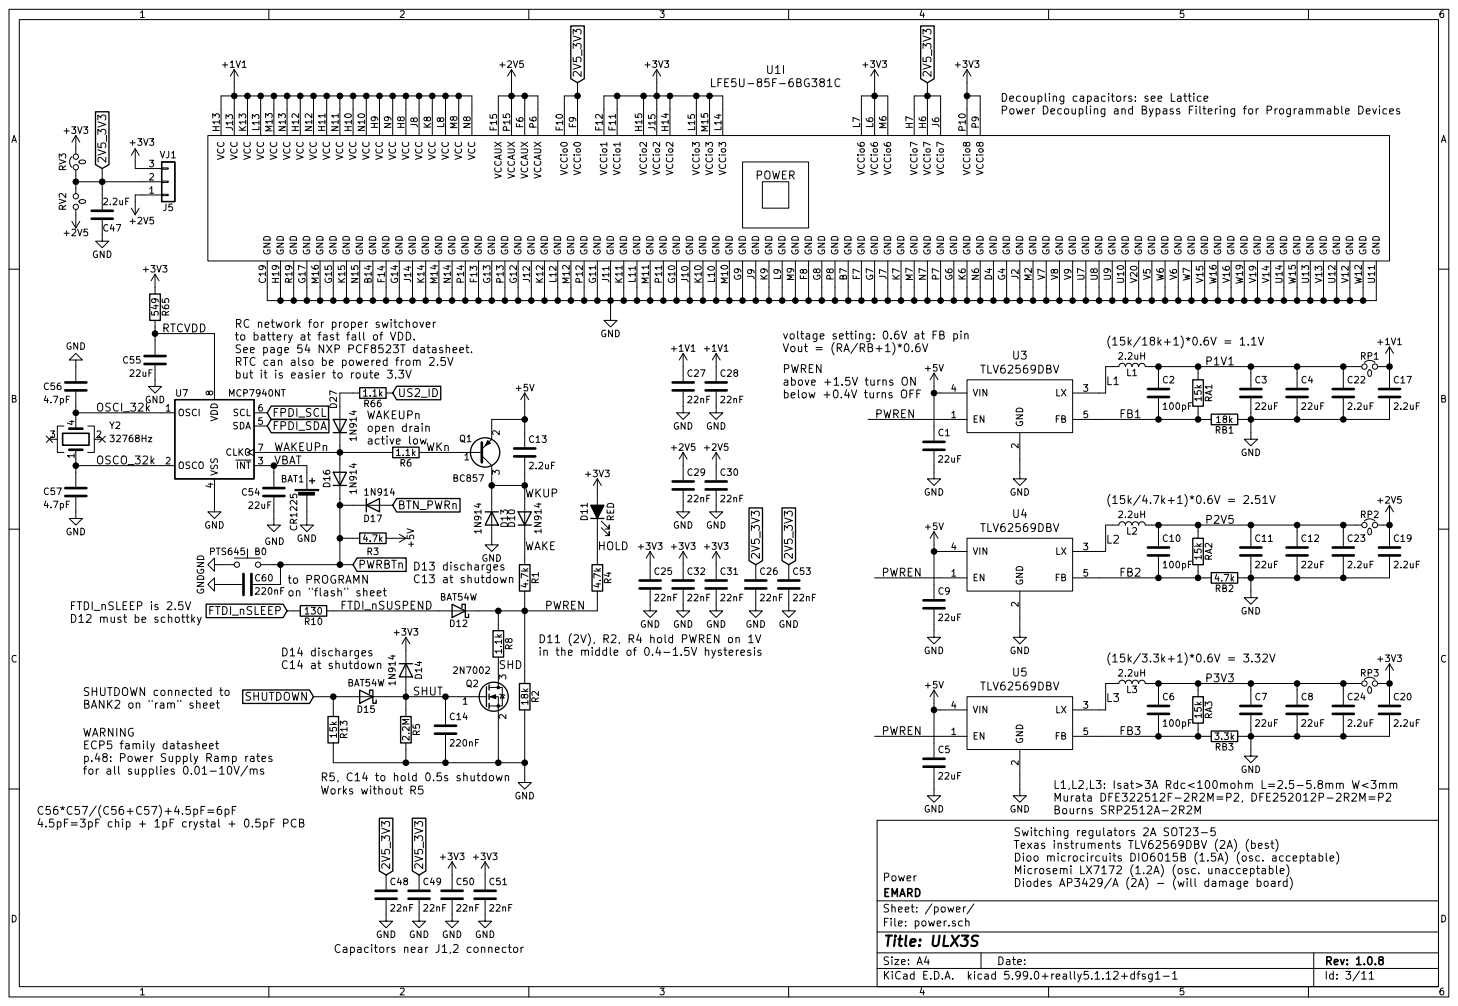
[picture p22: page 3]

RC network for proper switchover
to battery at fast fall of VDD.
See page 54 NXP PCF8523T datasheet.
RTC can also be powered from 2.5V

voltage setting: 0.6V at FB pin
Vout = (RA/RB+1)*0.6V
PWREN
above +1.5V turns ON
below +0.4V turns OFF

4 SDA 5 SCL 6 CLKO 7 VDD
18k BAT1CR1225 GND

open drain active low

D11 (2V), R2, R4 hold PWREN on 1V
in the middle of 0.4-1.5V hysteresis

WARNING
ECP5 family datasheet
p.48: Power Supply Ramp rates
for all supplies 0.01-10V/ms

Switching regulators 2A SOT23-5
Texas instruments TLV62569DBV (2A) (best)
Dioo microcircuits DIO6015B (1.5A) (osc. acceptable)
Microsemi LX7172 (1.2A) (osc. unacceptable)
Diodes AP3429/A (2A) - (will damage board)

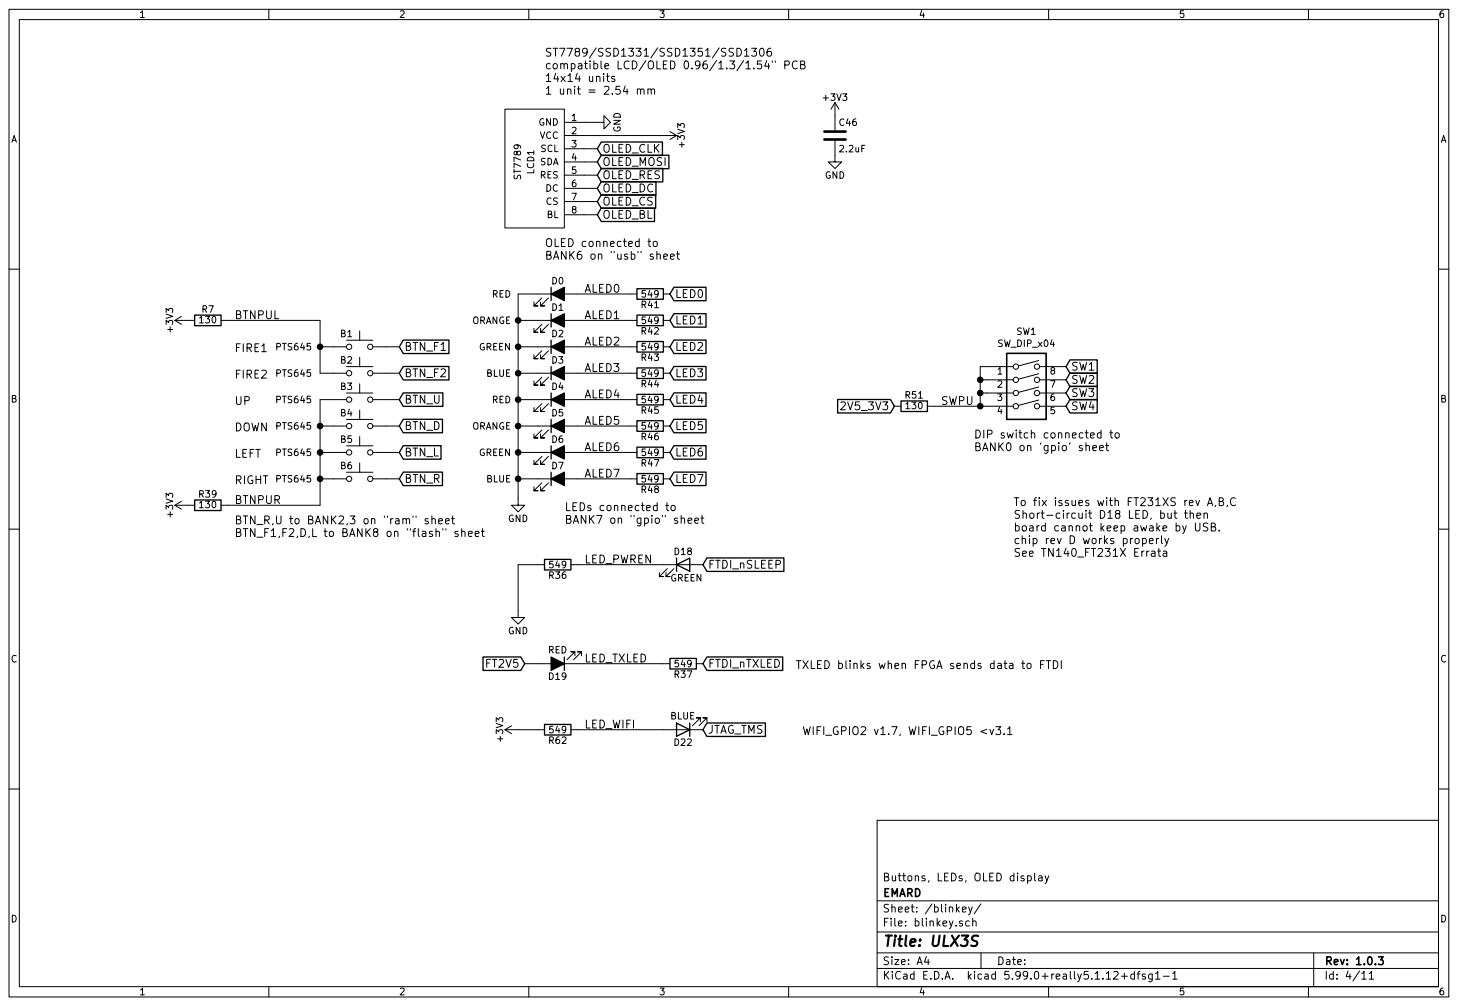
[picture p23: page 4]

ST7789/SSD1331/SSD1351/SSD1306
compatible LCD/OLED 0.96/1.3/1.54" PCB 14x14 units 1 unit = 2.54 mm
D2 GREEN
549 D6 GREEN

OLED connected to BANK6 on "usb" sheet BTN_R,U to BANK2,3 on "ram" sheet

BTN_F1,F2,D,L to BANK8 on "flash" sheet LEFT

LEDs connected to BANK7 on "gpio" sheet

To fix issues with FT231XS rev A,B,C
Short-circuit D18 LED, but then
board cannot keep awake by USB.
chip rev D works properly
See TN140_FT231X Errata

TXLED blinks when FPGA sends data to FTDI

Buttons, LEDs, OLED display
Sheet: /blinkey/ EMARD

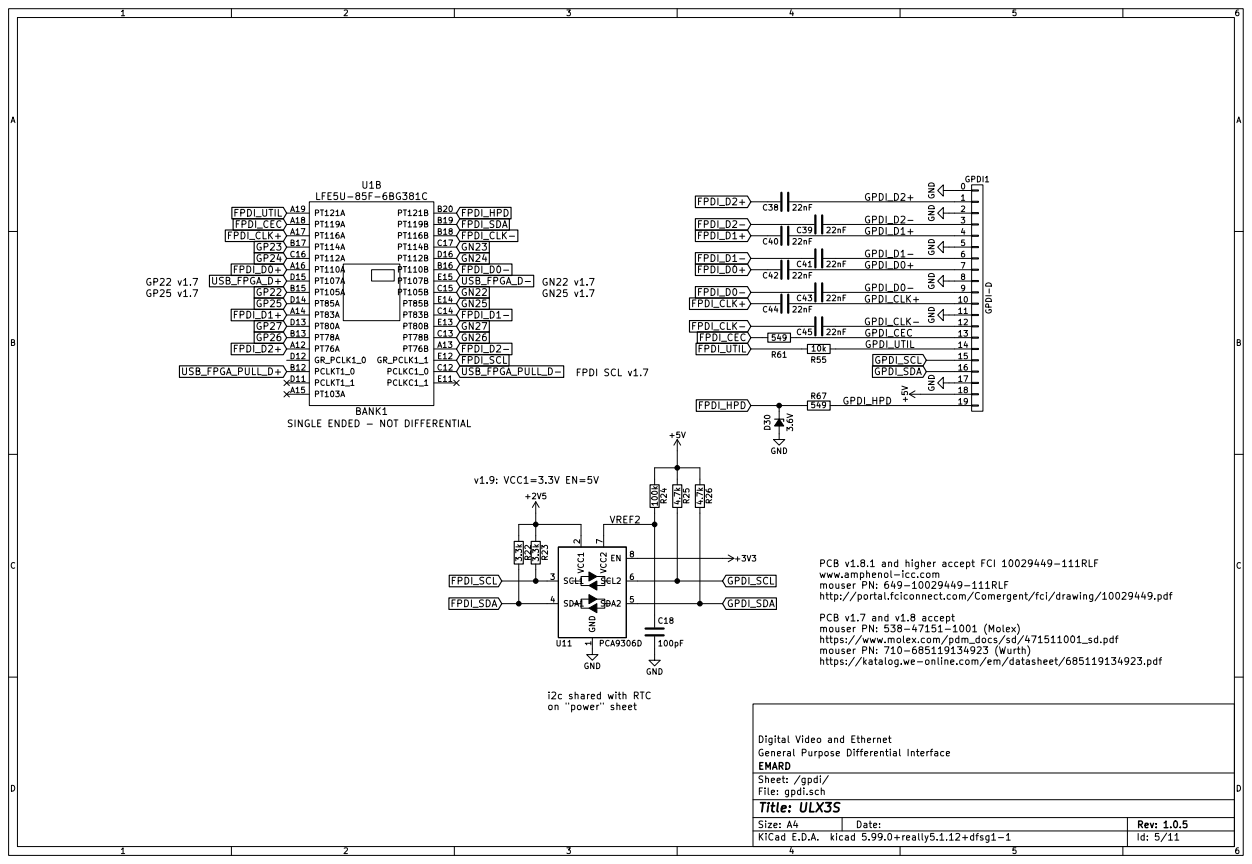
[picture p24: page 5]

FPDI_HPD
Digital Video and Ethernet R61

GPDI_D1+ | 4

GPDI_D0+ | 7

GPDI_CLK+ | 10

13
14

SINGLE ENDED - NOT DIFFERENTIAL

PCB v1.8.1 and higher accept FCI 10029449-111RLF
www.amphenol-icc.com
mouser PN: 649-10029449-111RLF
http://portal.fciconnect.com/Comergent/fci/drawing/10029449.pdf

PCB v1.7 and v1.8 accept
mouser PN: 538-47151-1001 (Molex)
https://www.molex.com/pdm_docs/sd/471511001_sd.pdf
mouser PN: 710-685119134923 (Wurth)
https://katalog.we-online.com/em/datasheet/685119134923.pdf

Sheet: /gpdi/ EMARD General Purpose Differential Interface

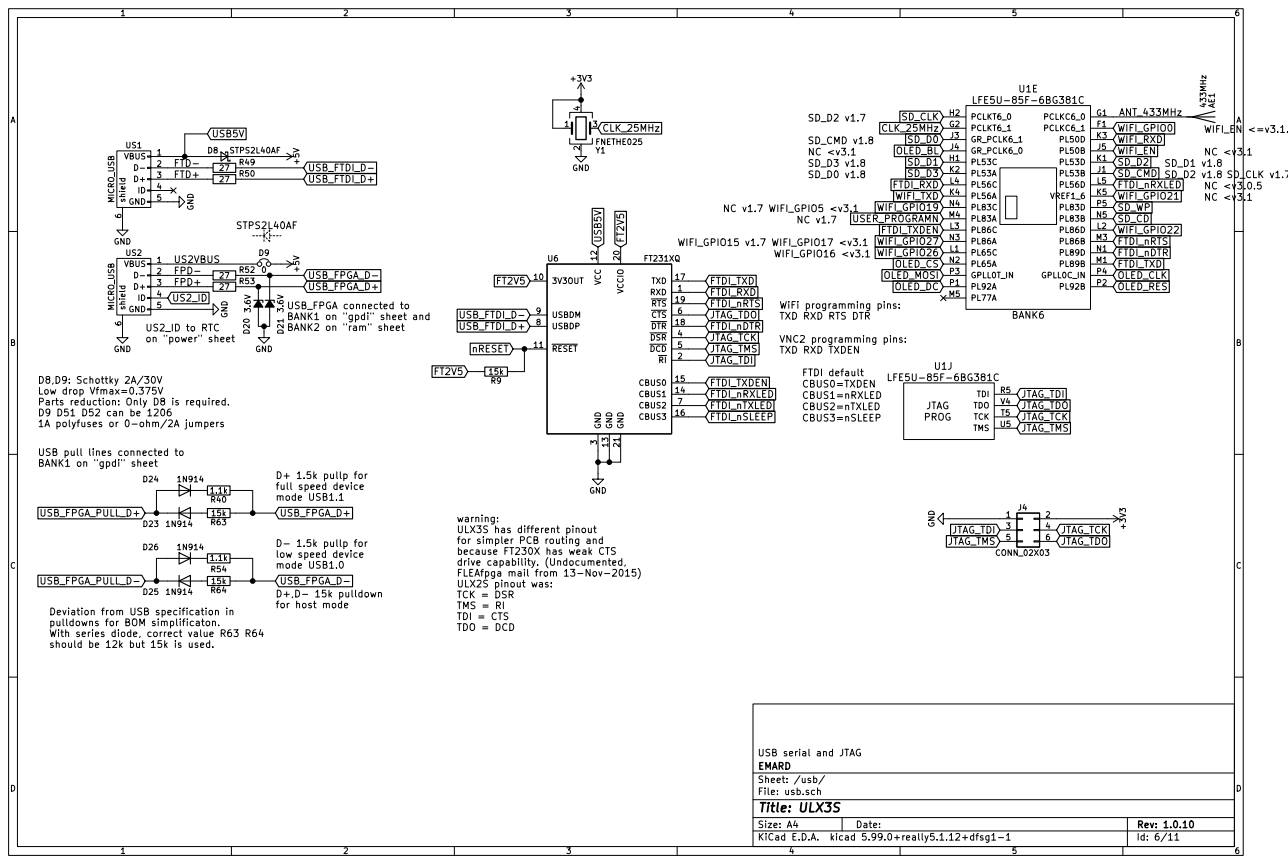
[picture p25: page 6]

3 DSR 4 DCD 5 CTS 6 CBUS2 7 USBDP 8 USBDM 9

WiFi programming pins:
TXD RXD RTS DTR

VNC2 programming pins: TXD RXD TXDEN

D8,D9: Schottky 2A/30V
Low drop Vfmax=0.375V
Parts reduction: Only D8 is required. D9 D51 D52 can be 1206

1A polyfuses or 0-ohm/2A jumpers

USB pull lines connected to
BANK1 on "gpdi" sheet

warning:
ULX3S has different pinout
for simpler PCB routing and
because FT230X has weak CTS
drive capability. (Undocumented,
FLEAfpga mail from 13-Nov-2015)
ULX2S pinout was:
TCK = DSR
TMS = RI
TDI = CTS
TDO = DCD

Deviation from USB specification in
pulldowns for BOM simplificaton.
With series diode, correct value R63 R64 should be 12k but 15k is used.

File: usb.sch Sheet: /usb/ EMARD

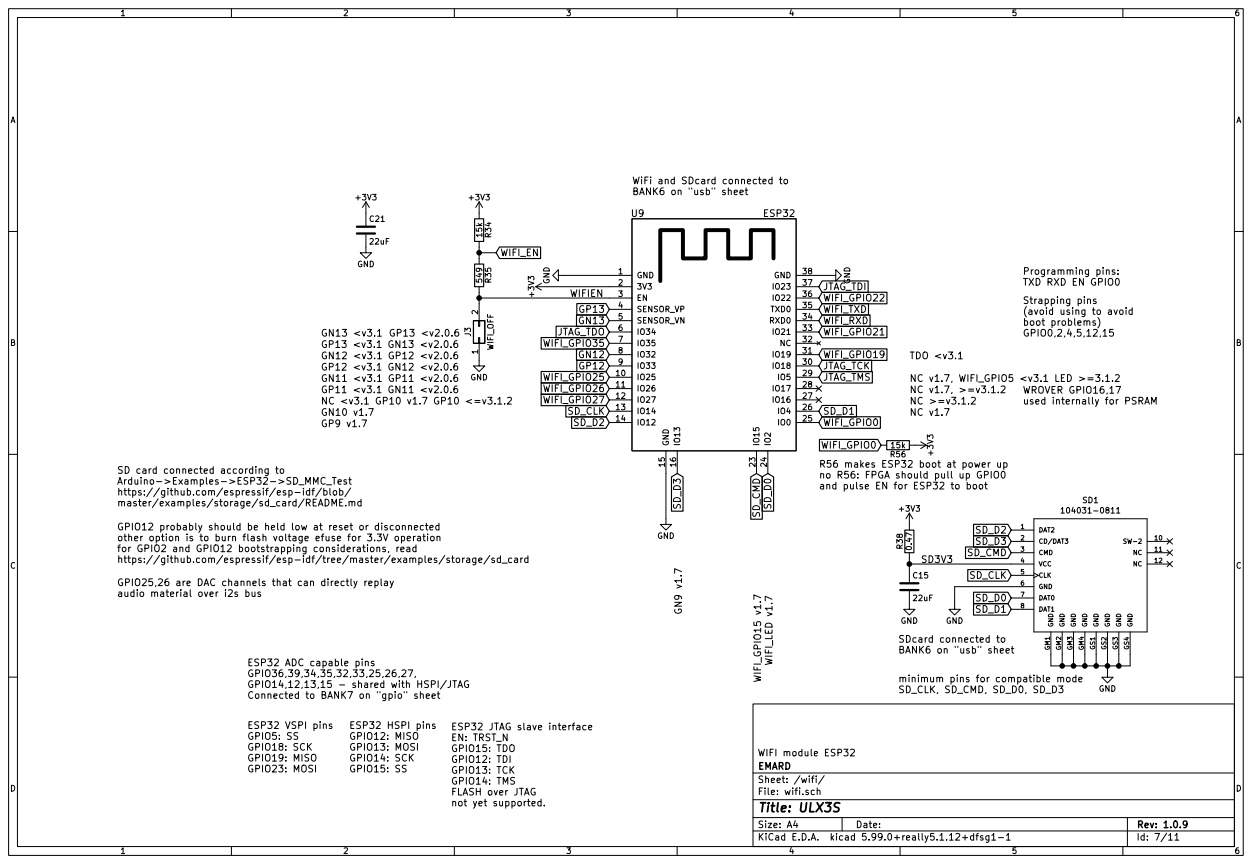
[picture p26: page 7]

TXD RXD EN GPIO0
Strapping pins
(avoid using to avoid
boot problems)
GPIO0,2,4,5,12,15

used internally for PSRAM

WIFI_GPIO0
R56 makes ESP32 boot at power up
no R56: FPGA should pull up GPIO0
and pulse EN for ESP32 to boot

SD card connected according to
Arduino->Examples->ESP32->SD_MMC_Test
https://github.com/espressif/esp-idf/blob/
master/examples/storage/sd_card/README.md

SDcard connected to BANK6 on "usb" sheet GPIO12 probably should be held low at reset or disconnected
other option is to burn flash voltage efuse for 3.3V operation
for GPIO2 and GPIO12 bootstrapping considerations, read
https://github.com/espressif/esp-idf/tree/master/examples/storage/sd_card

ESP32 ADC capable pins
GPIO36,39,34,35,32,33,25,26,27,
GPIO14,12,13,15 - shared with HSPI/JTAG
Connected to BANK7 on "gpio" sheet

minimum pins for compatible mode
SD_CLK, SD_CMD, SD_D0, SD_D3

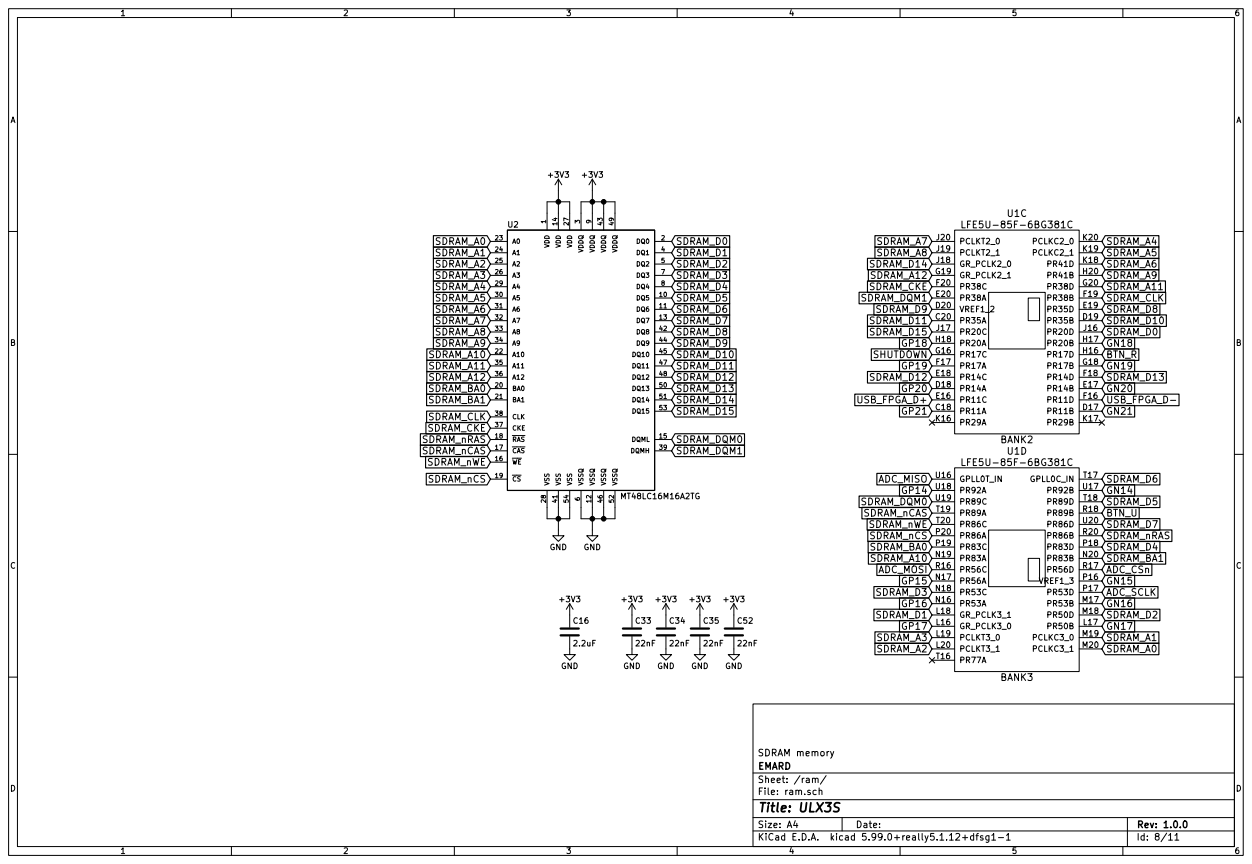
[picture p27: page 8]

File: ram.sch Sheet: /ram/ EMARD

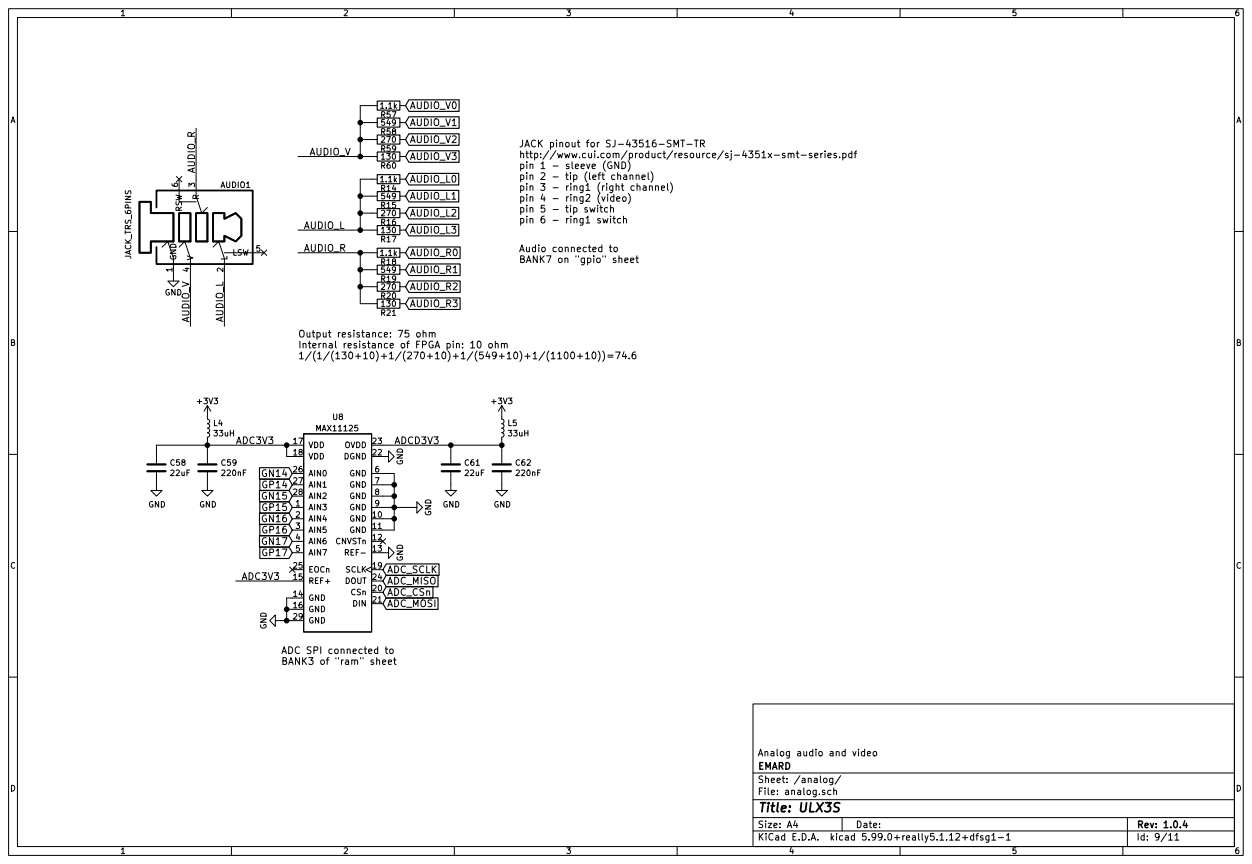
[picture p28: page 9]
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

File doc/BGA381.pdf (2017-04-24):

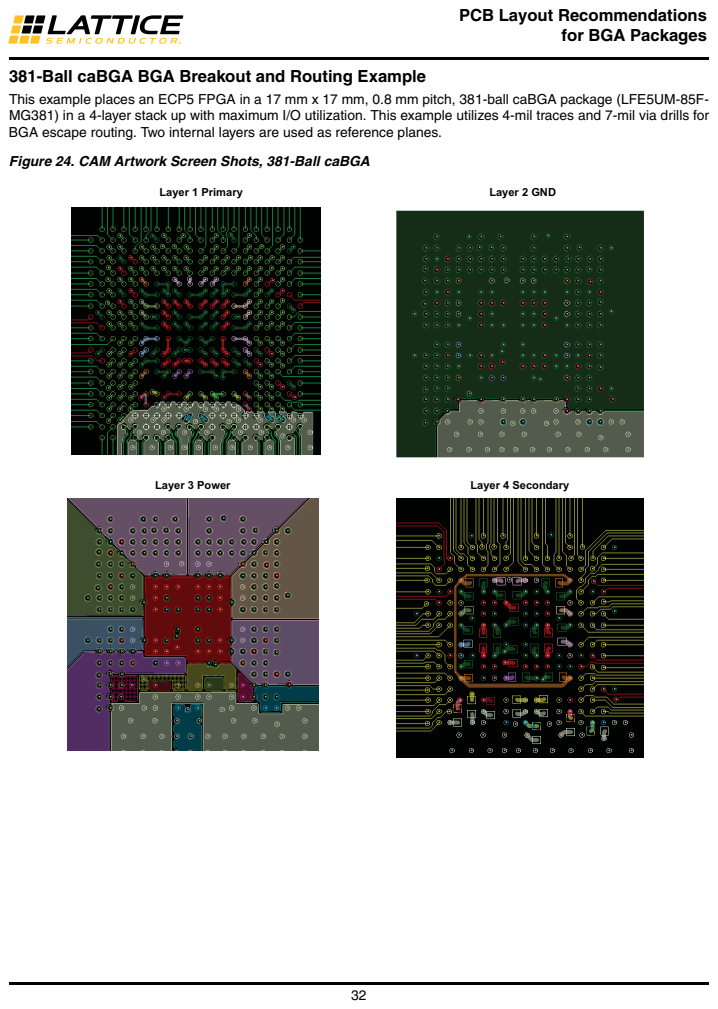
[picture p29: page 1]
Layer 1 Primary; Layer 2 GND; Layer 3 Power; Layer 4 Secondary

PCB Layout Recommendations

for BGA Packages

381-Ball caBGA BGA Breakout and Routing Example

This example places an ECP5 FPGA in a 17 mm x 17 mm, 0.8 mm pitch, 381-ball caBGA package (LFE5UM-85F-
MG381) in a 4-layer stack up with maximum I/O utilization. This example utilizes 4-mil traces and 7-mil via drills for
BGA escape routing. Two internal layers are used as reference planes.

Figure 24. CAM Artwork Screen Shots, 381-Ball caBGA

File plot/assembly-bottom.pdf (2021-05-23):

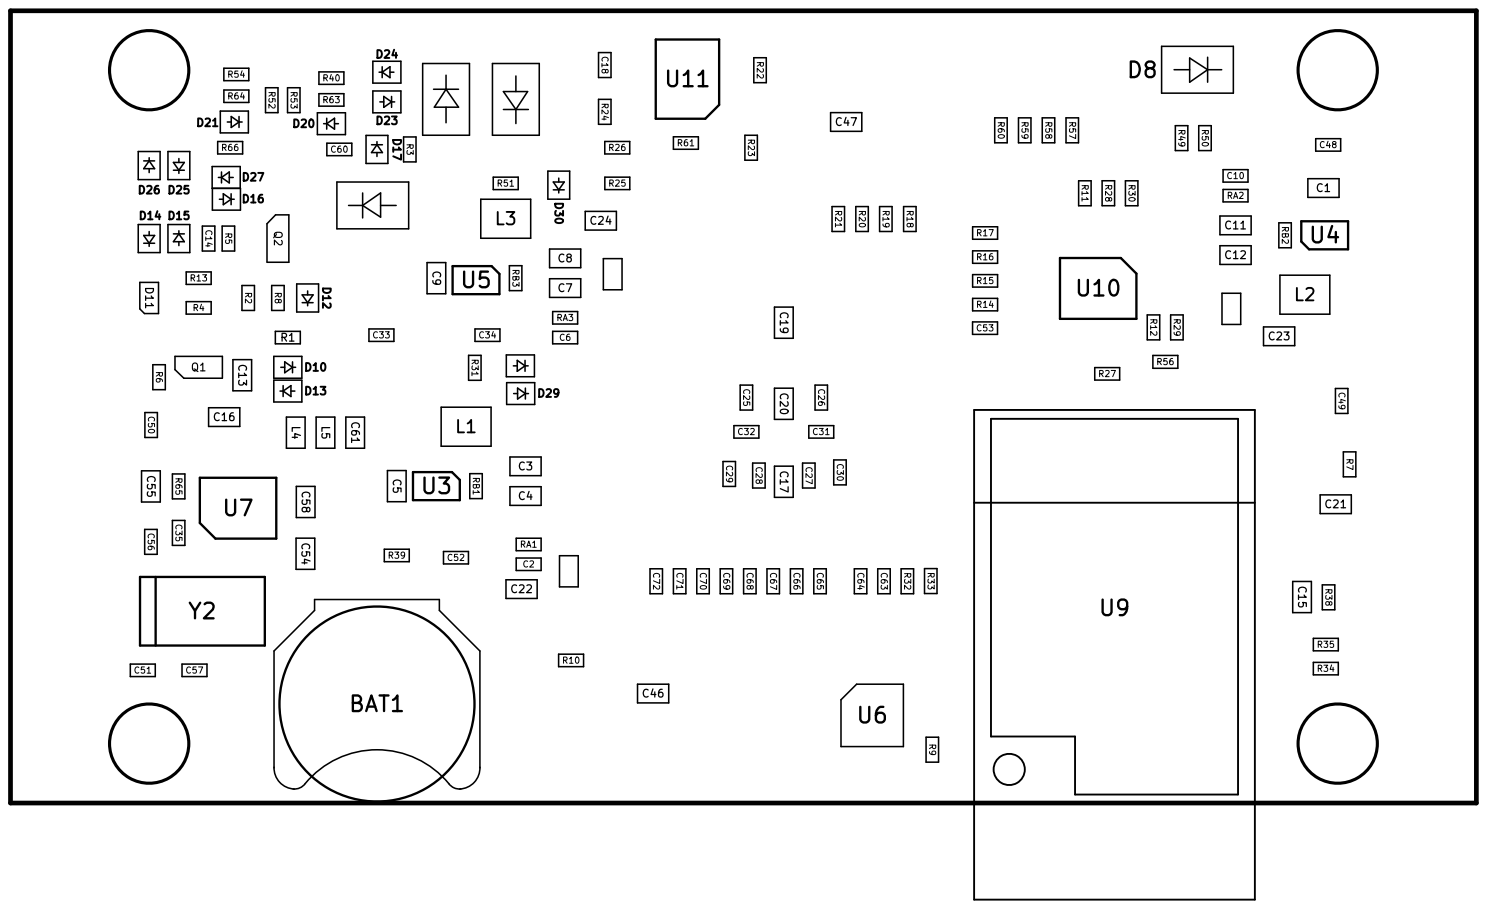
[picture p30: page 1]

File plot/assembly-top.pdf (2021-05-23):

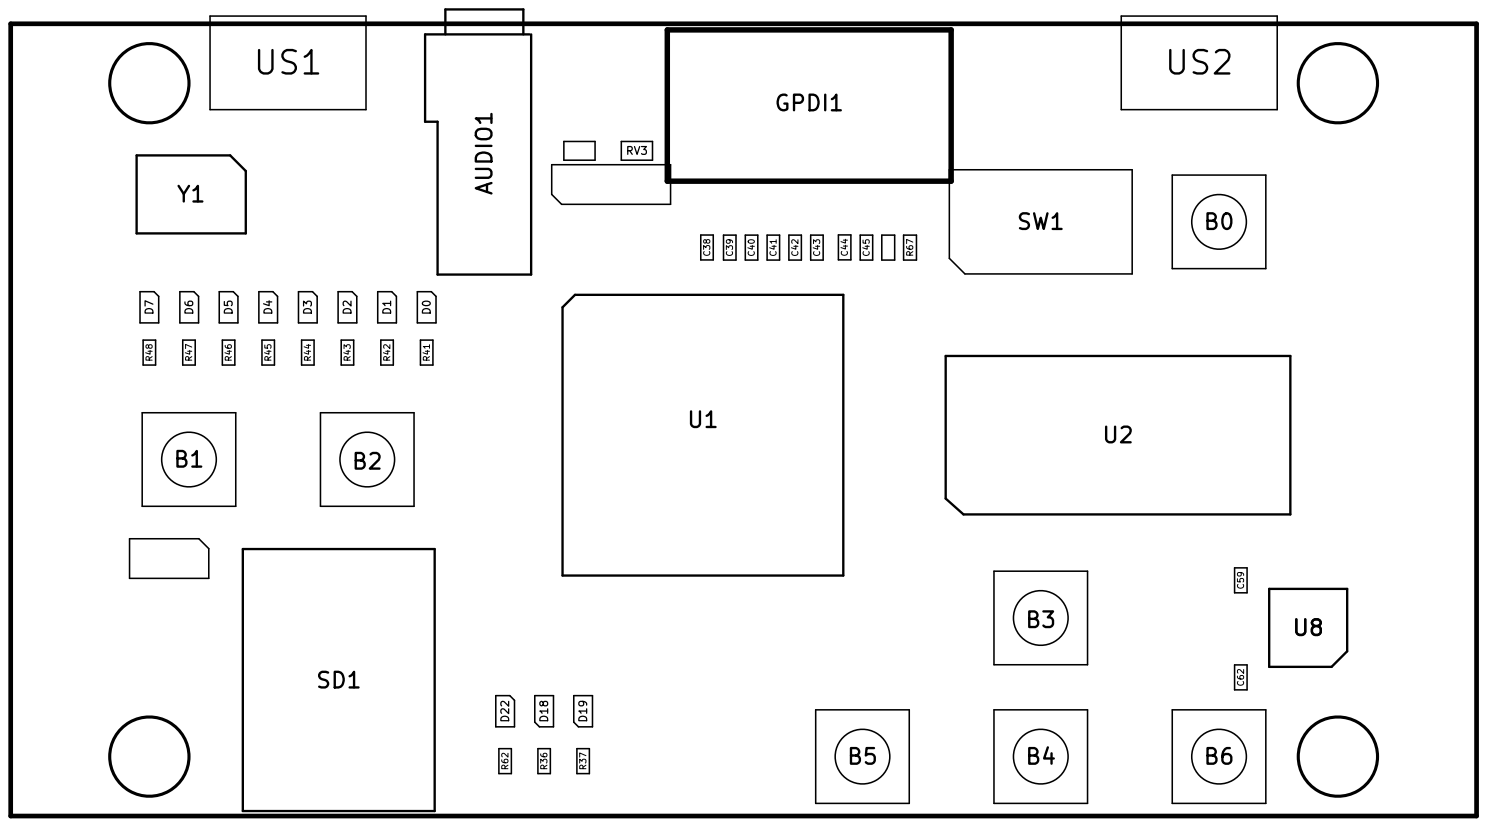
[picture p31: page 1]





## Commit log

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2018-06-02 schematics: Replace 3 power schottky diodes with 0-ohm resistors
    [gpio.sch, power.sch, usb.sch]
2018-06-02 PCB: 3D view replaced didoes with 0-ohm resistors
    [ulx3s.kicad_pcb]
2018-06-02 spice analysis of power section, corrected resistor values
2018-06-02 schematics: corrected resistor values in power section
    [power.sch]
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2018-06-03 spice: actual level of FTDI_nSLEEP is 2.5V replace correct schottky diode model
2018-06-03 spice: 2.5V from FTDI leaks to 3.3V power line and makes more difficult to shutdown. It explains why PCB v1.7 can't shutdown.
2018-06-03 schematics: D12 back to schottky, R8 back to 1.2k because FTDI_nSLEEP is 2.5V
    [power.sch]
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2018-06-03 PCB: moving US2 VIAs from under the footprint to the front of solder pads. Better to avoid any chance of short circuit with connector shell.
    [ulx3s.kicad_pcb]
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2018-06-06 schematics: 3 power schottky diodes replaced with 0-ohm jumpers
    [gpio.sch, power.sch, usb.sch]
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2018-06-07 tools to search-replace schematic symbol fields and fix broken gerbers created by debian kicad5-rc2
2018-06-07 gerbers fix applied
    [ulx3s-B.Cu.gbl, ulx3s-F.Cu.gtl]
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2018-06-07 schematics: revert USB default footprint
    [usb.sch]
2018-06-07 PCB: revert USB default footprint
    [ulx3s.kicad_pcb]
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2018-06-07 schematics v1.8.10: BOM fix for 4.7k resistors
    [gpdi.sch, power.sch, ulx3s.sch]
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2018-06-08 footprints: improve visibility of pin 1 at SOIC-8 packages, avoid writing silkscreen over the pads
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2018-06-08 PCB: SDRAM new footprint, dot for pin 1 for SW1 and ADC
    [ulx3s.kicad_pcb]
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2018-06-08 PCB: J3 correctly rotated
    [ulx3s.kicad_pcb]
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2018-06-09 schematics: revert ESP32 DAC to Audio Jack L/R
    [wifi.sch]
2018-06-09 PCB: revert ESP32 DAC to Audio Jack L/R
    [ulx3s.kicad_pcb]
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2018-06-10 PCB: fix selection of parts for insertion
    [ulx3s.kicad_pcb]
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2018-06-18 PCB v1.8.14: moving Y1 25MHz oscillator down, away from screw hole and silkscreen cosmetix
    [ulx3s.kicad_pcb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]
2018-06-18 gerbers update: switched to ASCII XY position file with mm units and drill file with suppress trailing zeros.
    [ulx3s-B.Cu.gbl, ulx3s-B.Mask.gbs, ulx3s-B.Paste.gbp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]
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2018-06-26 schematics: Update PN for 22uF and 0ohm PN currently available from Mouser
    [power.sch]
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2018-06-26 schematics: PN corrected for 220nF 0805->0603
    [power.sch]
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2018-06-27 footprints: rotating battery holder 90 deg to match Harwin track and reel information schematics: Battery holder PN and datasheet update
    [power.sch]
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2018-06-27 gerbers: part rotation corrected for battery holder
2018-06-27 schematics: cheaper crystals 32768 Hz in small package 3.2x1.5 mm compatible between pins 1 and 4 of current ABS25 package
    [power.sch]
2018-06-27 schematics v1.9.2: load capacitors for 32768 Hz quartz. Depending on internal capacitance of quartz and RTC chip, external capacitors are sometimes required (see RTC datasheet).
    [power.sch, ulx3s.sch]
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2018-07-03 PCB: BAT1 pad size enlarged 0.2 mm and pad clearance set to 0.7 mm
    [ulx3s.kicad_pcb]
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2018-07-03 schematics v1.9.4: correct PN Y2 quartz 32768Hz/6pF and matching load capacitance of 6pF with C56=C57=10pF for RTC MCP7904
    [power.sch, ulx3s.sch]
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2018-07-03 readme update (noise filter for ADC)
2018-07-03 schematics v1.9.5: Noise filter for ADC (L4,C58,C59)
    [analog.sch, power.sch, ulx3s.sch]
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2018-07-03 PCB v1.9.5: Noise filter for ADC (L4,C58,C59)
    [ulx3s.kicad_pcb]
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2018-07-03 PCB: GND-thru VIAs and Non-GND yellow layer clearance from board's edge
    [ulx3s.kicad_pcb]
2018-07-04 PCB: silkscreen names for buttons 0-6: PWR, F1, F2, U, D, L, R
    [ulx3s.kicad_pcb]
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2018-07-04 PCB: renamed references BTNx -> Bx and silkscreen writing PWR, F1, F2, UP, DOWN, LEFT, RIGHT
    [ulx3s.kicad_pcb]
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2018-07-04 PCB: make 3D models of 2.54mm headers invisible by renaming .wrl -> .wrl_disabled
    [ulx3s.kicad_pcb]
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2018-07-05 PCB: avoiding short circuits under SD card. One big VIA deleted, 2 smaller VIAs placed at the top of the GND pad under ESP32
    [ulx3s.kicad_pcb]
2018-07-05 PCB: trac cosmetix for SD card to lower possibility of short circuit unter "no pattern area"
    [ulx3s.kicad_pcb]
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2018-07-05 PCB: usage of 3D alternate footprint for molex hindged SD card slot (disabled) rename .wrl_disabled -> .wrl to enable
    [ulx3s.kicad_pcb]
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2018-07-05 footprints: local 3D button PTS645 (missing in latest kicad 3d library)
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2018-07-06 PCB: solder paste removed from PCB jumpers and added to THT holes of GPDI1 connector
    [ulx3s.kicad_pcb]
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2018-07-06 gerbers update: important: solder mask clearance appeared on all square pads
    [ulx3s-B.Cu.gbl, ulx3s-B.Mask.gbs, ulx3s-B.Paste.gbp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]
2018-07-07 PCB: move grid origin (white target) to cender of drill and place origin (red target)
    [ulx3s.kicad_pcb]
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2018-08-02 PCB: reduced clearance 0.127->0.1 mm to accept BGA slightly larger pads
    [ulx3s.kicad_pcb]
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2018-08-04 PCB: thinner BGA traces 0.19 -> 0.127 mm (5 mil), DRC passed
    [ulx3s.kicad_pcb]
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2018-08-04 PCB: enlarging BGA vias to 0.419 mm, DRC passed, need trac cosmetix
    [ulx3s.kicad_pcb]
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2018-08-04 PCB: thicker traces (0.5 mm) to 2.54 mm connectors J1, J2, SDRAM 0.127 -> 0.19 mm
    [ulx3s.kicad_pcb]
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2018-08-05 PCB: reducing copper traces on top layer under BGA to 0.127 mm
    [ulx3s.kicad_pcb]
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2018-08-07 PCB: trac cosmetix, routing BTN_R around to allow more BGA GND VIAs
    [ulx3s.kicad_pcb]
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2018-08-09 schematics: Mark as NC all BGA pins which are NC in 12F FPGA chip. So those pins can be recognized in PCB as having no net name. Those pins may have use on other chips 25F, 45F or 85F but we won't us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
    [gpdi.sch, gpio.sch, ram.sch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]
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2018-08-11 PCB: solder paste to copper clearance -0.025 mm from each edge
    [ulx3s.kicad_pcb]
2018-08-11 gerbers: solder paste to copper clearance
    [ulx3s-B.Cu.gbl, ulx3s-B.Mask.gbs, ulx3s-B.Paste.gbp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]
2018-08-11 box: adjust clearances, multicolor small notes
    [ulx3s-v19.scad]
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2018-08-17 PCB: in2.Cu fill minimal width increased 0.1->0.126 mm More than this >=0.127 mm DRC will not pass
    [ulx3s.kicad_pcb]
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2018-08-21 PCB: copper fill keepout area around GPDI and ADC, thicker trace 0.127->0.19 for 2.5V under BGA
    [ulx3s.kicad_pcb]
2018-08-23 partially fixed fab layer (need to fix many footprints too)
    [ulx3s.kicad_pcb]
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2018-08-23 PCB: re-run DRC after schematics v2.1.2 to make sure for NOP change
    [ulx3s.kicad_pcb]
2018-08-23 gerbers update: copper fill clearance under pins of GPDI and ADC
    [ulx3s-B.Cu.gbl, ulx3s-B.Mask.gbs, ulx3s-B.Paste.gbp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]
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2018-08-26 schematics: fix typo in comment where usb pull up/down are connected gpio->gpdi sheet
    [usb.sch]
2018-08-27 box update, remove obsolete screw holes at sides, enlarge audio jack hole, enlarge 2.5/3.3V jumper opening
    [ulx3s-v19.scad, upbox.scad]
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2018-08-28 PCB: route GP14 thru nearest VIA and leave space to balance 45deg routing to SDRAM.
    [ulx3s.kicad_pcb]
2018-08-28 footprints: fixing fab layer for assembly layout printed on paper sheet
2018-08-28 PCB: fixing Fab layers for assembly layout printed on paper sheet
    [ulx3s.kicad_pcb]
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2018-08-31 footprints: fixing for Fab layer
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2018-09-05 PCB: one BGA pad was doubly connected to GND, now single connection.
    [ulx3s.kicad_pcb]
2018-09-05 schematics v2.1.4: NOP change - placing NC marks on unused ADC pins
    [analog.sch, ulx3s.sch]
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2018-09-08 PCB: update footprints for ADC and USBSERIAL grid origin to lower left edge of PCB
    [ulx3s.kicad_pcb]
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2018-09-09 BOM: 1-click-bom update (D18 didn't appear with DigiKey PN)
    [1-click-bom.tsv]
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2018-09-12 PCB: balancing thermal relief on both SMD pads of R,C in attempt to prevent tombstoning
    [ulx3s.kicad_pcb]
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2018-09-15 PCB v2.1.9: move VIAs out of pads under BGA update R56 as virtual to not appear in fabrication placement list copper fill keepout on jumpers trac cosmetix
    [ulx3s-B.Cu.gbl, ulx3s-B.Mask.gbs, ulx3s-B.Paste.gbp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]
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2018-09-16 schematics 2.1.10: Flash pull up resistors R11 R12 R27 R28 15k -> 10k
    [flash.sch, ulx3s.sch]
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2018-09-16 box: centering rings on bottom side to avoid screw force and brekaing
    [ulx3s-v19.scad]
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2018-09-17 PCB v2.1.17: Silkscreen cosmetix text "SDRAM" moved away from pads text "R56" moved from top to bottom side, where it belongs
    [ulx3s.kicad_pcb]
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2018-09-18 PCB: solder paste to pad clearance increased -0.025 -> -0.05 applied to everything except BGA
    [ulx3s.kicad_pcb]
2018-09-18 gerbers update: solder paste to pad clearance increased -0.025 -> -0.05 applied to everything except BGA
    [ulx3s-B.Cu.gbl, ulx3s-B.Mask.gbs, ulx3s-B.Paste.gbp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]
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2018-09-22 schematics: corrected Mouser PN for 680 ohm (was 680K)
    [analog.sch]
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2018-09-28 schematics: correct 270 ohm PN
    [analog.sch]
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2018-10-12 footprints: increase paste to copper pad clearance for larger pads
2018-10-12 PCB: increase paste to copper pad clearance for larger pads
    [ulx3s.kicad_pcb]
2018-10-12 schematics: add NC "x" marks to wifi pins where nothing should be connected
    [usb.sch, wifi.sch]
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2018-10-16 PCB: R56 made invisible on 3D view (file renamed to *.wrl_disabled) updated ft231x outline on the silkscreen
    [ulx3s.kicad_pcb]
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2018-11-10 box: more tight front panel
    [ulx3s-v19.scad]
2018-11-11 box: adjusting dimensions, pcb thickness, mounting holes and 2mm wider to better fit 2.54mm headers
    [ulx3s-v19.scad]
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2018-11-13 box: adjusting dimensions, lowering height of in-hole rings, lowering connector cuts, increasing PCB holder clearance
    [ulx3s-v19.scad]
2018-11-14 box: move OLED opening 1 mm up for new displays have screen higher increase bottom foot lolerance 0.15->0.20 mm for tighter case
    [ulx3s-v19.scad]
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2018-11-26 PCB: attempt to fix tombstoning of R2, RA2, RA3, R33. R56 not yet fixed.
    [ulx3s.kicad_pcb]
2018-11-26 PCB v3.0.7: attempt to fix tombstoning of R65
    [ulx3s.kicad_pcb]
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2019-03-17 schematics update: J1 and J2 mirrored in order to have the same visual appearance as on physical PCB.
    [gpio.sch]
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2019-03-18 schematics: fix numbering on mirrored J1/J2
    [gpio.sch]
2019-03-18 schematics: move clock capable text GP18->GP17 after connector rotation things got shifted....
    [gpio.sch]
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2019-03-23 1-click bom update: RTC from microchip, FLASH from winbond, FPGA 85F, TI switchers
    [1-click-bom.tsv]
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2019-04-08 silkscreen: flip fields of hrvatski grb for white on dark printing
    [ulx3s.kicad_pcb]
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2019-05-30 move KONCAR v3.0.3 production files to "old" directory to avoid mixing with new production
    [ulx3s_bom_3.0.3_dolje.csv, ulx3s_bom_3.0.3_gore.csv]
2019-06-05 schematics: additional ADC filter for digital 3.3V supply update analog sheet version to v1.0.4 update toplevel schematics version to v3.0.8
    [analog.sch, ulx3s.sch]
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2019-06-05 PCB: v3.0.8 (warning: stencil incompatible with v3.0.3-v3.0.7)
    [ulx3s.kicad_pcb]
2019-06-05 gerbers: v3.0.8 (warning: stencil incompatible with v3.0.3-v3.0.7)
    [ulx3s-B.Cu.gbl, ulx3s-B.Mask.gbs, ulx3s-B.Paste.gbp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]
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2019-09-27 schematics: alternate PN for 25MHz oscillator Y1
    [analog.sch, blinkey.sch, flash.sch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]
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2019-12-06 PCB, footprints: fix copper jumpers from generating DRC errors
    [ulx3s.kicad_pcb]
2019-12-06 PCB, footprints: closing courtyard of BAT1 to avoid DRC errors
    [ulx3s.kicad_pcb]
2019-12-06 PCB, footprints: closing courtyard of US1,2 connectors to avoid DRC errors
    [ulx3s.kicad_pcb]
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2019-12-13 PCB: fix drc warning with new kicad
    [ulx3s.kicad_pcb]
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2020-04-06 ulx3s-v19f.scad: adjusting dimension increase height, LCD pressed too much
    [ulx3s-v19f.scad]
2020-04-07 ulx3s-v19f.scad: LCD pressed too much - increase height 0.5mm
    [ulx3s-v19f.scad]
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2020-04-07 box: increase feet clearance to make bot and top part touch when screwed
    [ulx3s-v19f.scad]
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2020-04-08 box: enlarging flat cable openings (was too tight)
    [ulx3s-v19f.scad]
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2020-04-16 assembly-bot.pdf: floorplan mirrored to be correctly printed as viewed from bottom side
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2020-04-21 PCB preparation for v3.1.0 (ESP32 25-33 to GP/GN 10-13 need some rework)
    [ulx3s.kicad_pcb]
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2020-05-21 schematics: fix LCSC PN's 127->27 25 MHz 1.8V->3.3V
    [usb.sch]
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2020-06-13 schematics: fix mouser alternate red LED PN
    [blinkey.sch]
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2020-06-13 schematics: swap koncar FR013 FR014 to match their latest PNP file
    [flash.sch, power.sch]
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2020-07-12 schematics: v3.1.1 WiFi/JTAG LED to 3.3V. USB-serial has electrical default pull-up so this LED will be OFF by default. For ESP32 it will have inverted logic, ON when logical 0.
    [blinkey.sch, ulx3s.sch]
2020-07-12 PCB: v3.1.1 WiFi LED inverted
    [ulx3s.kicad_pcb]
2020-07-12 gerbers v3.1.1: WiFi/JTAG LED inverted
    [ulx3s-B_Cu.gbl, ulx3s-B_Mask.gbs, ulx3s-B_Paste.gbp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]
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2020-08-23 schematics: increase RTC quartz load capacitors C56,C57 3.3->4.7 pF (RTC was running too fast)
    [power.sch]
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2020-08-28 PCB: clearance for WROVER size, 2.5V VIAs and traces too thin but pass DRC
    [ulx3s.kicad_pcb]
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2020-10-01 footprints: fix swapped A9-B10 in serdes schematics symbol
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2020-10-03 todo: FT231 too close to LCD holes
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2020-10-18 footprints: remove pin 9 from SD card, currently too close to GND
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2020-10-19 schematics: fix wrong placed zener D30 at gpdi
    [gpdi.sch]
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2020-11-02 PCB: silkscreen logo footprints made "virtual", avoid placement
    [ulx3s.kicad_pcb]
2020-11-02 gerbers: avoid placement virtual footprints for logos
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2020-11-12 PCB: trac cosmetix, delete hidden track on the pad of 3.3V C under BGA
    [ulx3s.kicad_pcb]
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2020-11-16 1-click-bom.tsv: SD card slot for digikey and LCSC, non-stocked 45F at LCSC
    [1-click-bom.tsv]
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2020-11-20 schematics: fix PN newark mistake at BAT1
    [power.sch]
2020-11-20 1-click-bom.tsv: fix PN newark mistake at BAT1
    [1-click-bom.tsv]
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2020-12-30 todo swap WIFI_EN and WIFI_GPIO22, then WIFI_GPIO22 will be at FPGA clock capable pin
2021-01-25 schematics v3.1.5 note on swapping WIFI_EN - WIFI_GPIO22
    [ulx3s.sch, usb.sch]
2021-01-25 PCB: v3.1.5 preliminary, swapped WIFI_EN - WIFI_GPIO22
    [ulx3s.kicad_pcb]
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2021-02-17 gerbers v3.1.5 thicken flash lines, ant 433 straighten, bga flood small update
    [ulx3s-B_Cu.gbl, ulx3s-B_Mask.gbs, ulx3s-B_Paste.gbp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]
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2021-02-27 schematics: v3.1.6 preliminary, WIFI_GPIO0 and WIFI_GPIO22 swapped
    [ulx3s.sch, usb.sch]
2021-02-27 PCB: v3.1.6 preliminary, WIFI_GPIO0 and WIFI_GPIO22 swapped
    [ulx3s.kicad_pcb]
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2021-03-11 correct relative path for micro sd schematics symbol
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2021-06-11 panel: fix area and tolerace to let all board parts included
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2021-06-12 panelizing near what Koncar did, one detail missing, mill cut should be extended few mm left and right
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2021-06-13 panels: reduce mill radius to 1 mm to reduce size of the spikes at the eges as workaround until option to horizontally enlarge mill areas is known
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2021-06-13 PCB: text for panelization workaround: IGNORE THIS EDGE CUT, USE PANEL MILL
    [ulx3s.kicad_pcb]
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2021-07-12 PCB: write note to ignore rectangle cut from paste layer (stencil) until kikit bugs are fixed
    [ulx3s.kicad_pcb]
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2021-08-25 panelization source tolerance 20 mm
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2021-10-09 footprints: D&M logo fix
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2021-11-12 makefile panel: fixes error can't V-Cut a curve
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2021-11-15 snap box
    [boxhook.scad, snapbox.scad, ulx3s-v17-oled.scad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]
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2021-11-16 snapbox: updated dim's and printing comments
    [ulx3s.scad]
2021-11-16 footprints workaround symlink
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2021-11-20 separate ulx3s_pcb include, fix for header_type, side and display cut fix
    [ulx3s.scad, ulx3s_pcb.scad]
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2023-07-30 open/save with kicad 7 in design rules: reduced copper to hole clearance 0.25->0.22 mm to pass DRC check
